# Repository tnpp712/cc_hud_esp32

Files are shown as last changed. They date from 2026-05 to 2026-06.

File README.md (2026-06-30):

# cc_hud · AI 状态灯

放在桌上的一个小硬件 HUD：一块 1.54″ 彩屏显示 **Claude Code / Codex 的额度、花费、上下文、状态**，外圈 24 颗灯随 AI "在干嘛"红黄绿变化。ESP32-S3 驱动，电脑通过蓝牙/WiFi 把状态推给它。

> 本仓库是 [`uk0/cc_hud_esp32`](https://github.com/uk0/cc_hud_esp32) 的私有 fork，在原版"BLE 推额度 + LCD HUD"基础上做了大量产品级增强（见下）。英文原版说明见 [`README.en.md`](README.en.md)。

<p align="center">
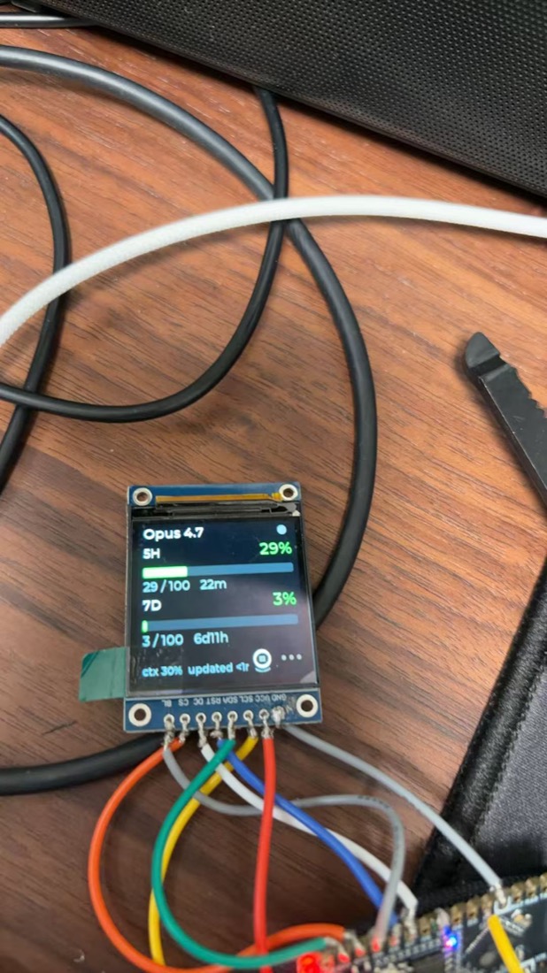
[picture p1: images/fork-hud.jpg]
HUD 显示额度
  
  &nbsp;&nbsp;
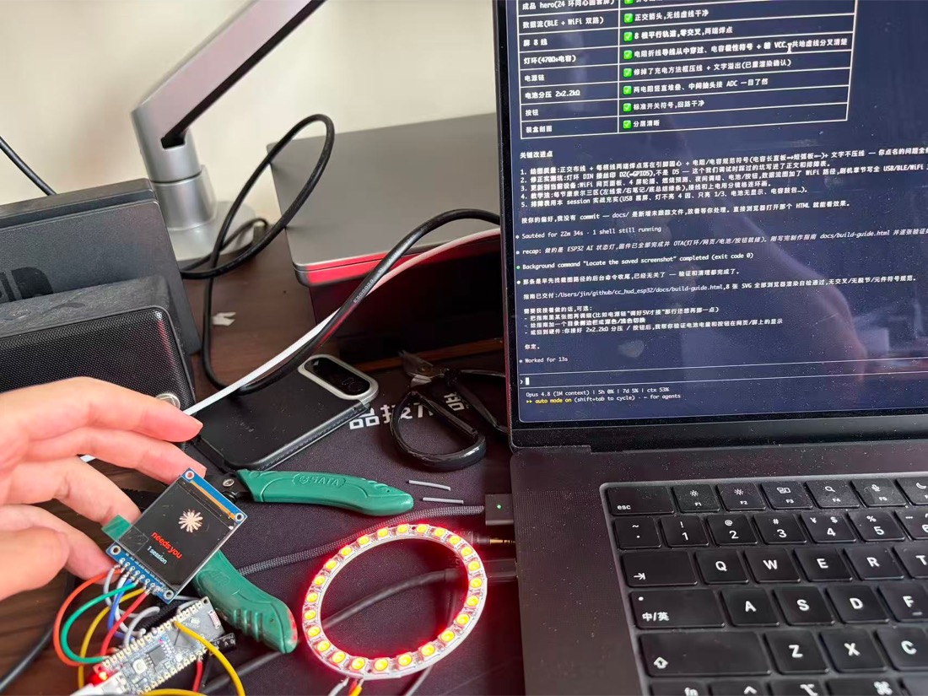
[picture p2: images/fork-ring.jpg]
设备 + 24 灯环
  
</p>

<p align="center"><em>左：屏幕实时显示 5H/7D 额度 + 重置倒计时 + 上下文用量。右：屏 + 24 颗 WS2812B 状态灯环。</em></p>

---

## 🔱 本 fork 新增功能

**显示 / UI**
- **4 屏轮播状态机**：额度页 / 统计页（成本·时长·增删行·5H 重置倒计时）/ 工具页（大图标 + N 会话·M 忙）/ 时钟页；空闲自动轮播、干活锁工具页、防抖
- **燃烧率耗尽预测**：按当前用速预测"X 窗口会在重置前耗尽" → footer 红字预警
- 更大字号 HUD + CJK 中文天气

**24 灯环状态灯（WS2812B，`firmware/src/led_ring.*`）**
- 空闲 = 绿色**额度表**（点亮颗数 = 额度%、分级变色）
- 工作 = 黄色**彗星** · 等权限 = 红色**整环闪** · 低电 = 橙色慢闪
- **Codex 完成绿脉冲**：AI 答完一轮闪三下

**无线 / OTA / 网页（`firmware/src/wifi_ota.*`）**
- **WiFi OTA**：`cc-hud.local` 局域网秒级刷机（BLE OTA 保留作救砖）
- **网页面板** `http://cc-hud.local/`：实时额度/成本/状态/电量，**亮度滑块（存 NVS、免重刷）**、翻页/调暗遥控、固件版本/运行时长/内存
- **NTP 自动校时**：WiFi 在线自动授时，断电后免手动校准

**智能 / 省电**
- 夜间(23:00–07:00)+ 长空闲自动调暗、空闲 10 分钟熄灯环
- 修复 USB-CDC-on-boot 导致的"插电脑屏黑"（`displayInit` 前移）

**多 AI 工具支持**
- **Codex CLI**：`~/.codex/config.toml` 的 `notify` → 适配器，答完触发灯环绿脉冲；链式调度器保留已有 notify（如 computer-use）
- 任意工具调 `host/push_state.py` 即可推状态；多工具/多会话**统一聚合**（有人忙就显示忙）

**可选硬件（接上即生效，不接不误报）**
- 电池电量监测（2×2.2kΩ 分压 → 丝印 A0）+ 低电告警
- 实体按钮（→ 丝印 A1）短按翻页、长按调暗

---

## 硬件一览

| 部件 | 选型 |
|---|---|
| 主板 | ESP32-S3-Nano（N8R8/N16R8，兼容 Arduino Nano ESP32 引脚） |
| 屏 | 1.54″ 240×240 IPS ST7789（4 线 SPI，8pin） |
| 灯环 | WS2812B **24 位**单圈圆环（内径 ≥56mm）+ 470Ω 电阻 + 470µF 电容 |
| 电源 | 3.7V 锂电（带保护板）+ TP4056 充电 + MT3608 升压 5V + 自锁开关 |
| 可选 | 2×2.2kΩ（电量）、自复位按钮、亚克力盒 |

> ⚠ 丝印坑：这块板低位 GPIO 标 **A0–A7**，灯环 DIN 接 **D2(=GPIO5)** 不是 "D5"。完整对照见制作指南。

---

## 快速上手

**完整图文制作指南** → **[`docs/build-guide.html`](docs/build-guide.html)**（康奈尔笔记 + 分镜，浏览器直接打开：引脚总表 / 焊接 / 接线 / 调 5V / 刷机 / 排障 / 多工具）。

最短路径：

1. **焊屏**：屏 8 线接主板（VCC→3V3，**别接 5V**）
2. **焊电源**：电池→TP4056→开关→MT3608，**先单独调好 5.0V** 再接主板
3. **焊灯环**：DIN 经 470Ω → 主板 D2(GPIO5)；VCC → MT3608 IN+（开关后 3.7V）；470µF 跨 VCC/GND
4. **刷固件**：USB 首刷 → 之后 WiFi OTA 秒刷
   ```bash
   cd firmware
   pio run -e esp32s3_nano -t upload            # USB 首刷
   pio run -e esp32s3_nano_wifi -t upload       # 之后 WiFi 秒刷
   ```
5. **配电脑**（目录 `host/`，下面命令都在这个目录里跑）

   电脑在这套系统里是"中间人"：读 AI 的状态/额度 → 通过蓝牙推给盒子。核心是一个常驻后台进程 **daemon**，它**独占一条蓝牙连接**，把多个 AI 会话的状态聚合后推给设备。按 ①→⑤ 配一遍即可。

   **① 建 Python 环境**
   ```bash
   python3.12 -m venv .venv && .venv/bin/pip install bleak
   ```
   - `venv` 是隔离的 Python 环境，依赖只装进 `host/.venv/`，不污染系统 Python；`bleak` 是跟蓝牙设备通信的库。
   - **为什么必须 Python ≥ 3.10**：daemon 启动时会建一个"蓝牙发送队列"，Python 3.9 会把这个队列错绑到旧的事件循环上，导致 daemon 一跑就满屏 `attached to a different loop`、蓝牙完全发不出去；3.10 起改了这个行为才正常。没有 3.12 就 `brew install python@3.12`。

   **② 找设备地址，存成环境变量**
   ```bash
   .venv/bin/python push_quota.py --discover          # 列出附近设备，记下你盒子的 UUID
   echo 'export CCHUD_ADDR=<上一步的UUID>' >> ~/.zshrc && source ~/.zshrc
   ```
   - macOS 上蓝牙设备没有固定 MAC，只有系统分配的一串 UUID，所有推送都要靠它指明"发给哪个盒子"。
   - **为什么写进 `~/.zshrc`、不改脚本**：地址放进环境变量后，仓库脚本保持原样——`git pull` 不冲突，也不会把你的设备地址提交进代码。之后每个命令都用 `$CCHUD_ADDR` 引用它。

   **③ 给盒子配 WiFi**（一次性，经蓝牙写入）
   ```bash
   .venv/bin/python push_wifi.py --address $CCHUD_ADDR --ssid 'WiFi名' --password '密码'
   ```
   - **为什么要联网**：盒子联网后能自动 NTP 校时、用 WiFi 秒级 OTA 刷固件、开网页面板 `http://cc-hud.local/`。不联网也能用蓝牙，但这些功能没了。

   **④ 装 hooks**（让 AI 自动上报状态）
   ```bash
   CCHUD_ADDR=$CCHUD_ADDR CCHUD_USE_V7=1 .venv/bin/python -m cchud_daemon.cli install claude
   CCHUD_ADDR=$CCHUD_ADDR CCHUD_USE_V7=1 .venv/bin/python -m cchud_daemon.cli install codex
   ```
   - **hook** = AI 工具在关键时刻（开始思考、调工具、等你确认、结束）自动运行的小脚本，这里就是把状态投给 daemon。
   - 两条命令分别给 Claude Code 和 Codex 各装一套，会自动写进它们各自的配置并**保留你已有的第三方 hook**；`CCHUD_USE_V7=1` 表示用新版 v7 协议（配最新固件）。

   **⑤ 起常驻 daemon**
   ```bash
   CCHUD_ADDR=$CCHUD_ADDR CCHUD_USE_V7=1 .venv/bin/python -m cchud_daemon.cli daemon
   ```
   - 保持这个终端窗口开着，它就一直把状态推给盒子；终端没刷出错误 = 正常。
   - **为什么必须在普通终端跑、不能用 launchd 开机自启**：macOS 的蓝牙权限按"谁启动了这个进程"授权——普通终端有授权，而 launchd 拉起的后台进程拿不到、还不弹授权框，会静默报 `BLE is not authorized`。想保活可以用 tmux 或 `nohup`。

   **Codex 额外两点**
   - 装完 hooks 要**重启 Codex**，启动时会弹"是否信任 hooks"，选 **Trust all and continue**——新版 Codex 不信任就不跑 hook。
   - ⚠️ **千万别往 `~/.codex/config.toml` 写 `hooks = true`**：新版 Codex 会报 `expected struct HooksToml` 直接起不来。`~/.codex/hooks.json` 是自动加载的，不需要这行。

   > 状态栏渲染用 `ccstatusline`；本机没装 `bun` 的话，把 `cchud-statusline.sh` 里的 `bunx` 改成 `npx`。完整步骤 / 排错见 [`host/DAEMON.md`](host/DAEMON.md)。

---

## 多 AI 工具

| 工具 | 显示 | 接法 |
|---|---|---|
| **Claude Code** | 完整：额度 + 上下文 + 成本 + 4 状态灯 + 多会话 | `cchud_daemon.cli install claude`（写 `hooks` + `statusLine`，保留第三方） |
| **Codex CLI** | 状态 + 多会话（思考/工具/等待/空闲） | `cchud_daemon.cli install codex`（写 `~/.codex/hooks.json`，重启 Codex 后 **Trust hooks**；**勿写 `hooks=true`**） |
| 其它 | 任意脚本调 `push_state.py` 推状态/灯色 | 通用 CLI |

---

## 目录结构

```
firmware/        ESP32-S3 固件（PlatformIO · LVGL 9 · NimBLE）
  src/
    main.cpp           主循环 + 状态聚合 + NTP + 省电
    led_ring.*         24 灯环状态灯
    wifi_ota.*         WiFi OTA + 网页面板
    lvgl_ui.*          4 屏 UI
    display.* ble_server.* persistence.* battery.* button.*
host/            电脑端 Python + shell
  push_wifi.py / push_state.py / push_quota.py / push_idle.py / ota.py
  cchud-hook.sh / cchud-update.sh / cchud-idle.sh   (Claude Code)
  cchud-codex-notify.sh / cchud-codex-dispatch.sh   (Codex)
docs/build-guide.html  完整图文制作指南
README.en.md           英文原版说明（upstream）
```

---

*基于 [uk0/cc_hud_esp32](https://github.com/uk0/cc_hud_esp32)。本 fork 增强见上。*

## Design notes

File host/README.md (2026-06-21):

# cc_hud host push CLI

`push_quota.py` sends a 9-byte BLE payload to the CC-HUD device, updating the
5-hour and 7-day quota bars shown on the hardware display.

`cchud-update.sh` is a rate-limited fire-and-forget wrapper meant for
high-frequency hooks (Claude Code statusline, shell prompts, etc.).

---

## Install

```bash
# Recommended (uv):
uv venv .venv
uv pip install -r requirements.txt

# Or plain Python:
python3 -m venv .venv
.venv/bin/pip install -r requirements.txt
```

---

## First-time setup: discover your device

macOS hides BLE MAC addresses, so each peripheral is identified by a
CoreBluetooth UUID instead. Linux and Windows show the real MAC. Find yours:

```bash
.venv/bin/python push_quota.py --discover --verbose --timeout 8
```

Example output:

```
ADDRESS                                   NAME              RSSI
03265204-7126-B6FE-6F17-6E9621CEA97F      CC-HUD            -37 dBm
```

Save that address — use it with `--address` (push_quota.py) or via
`CCHUD_ADDR` (cchud-update.sh) so subsequent pushes skip the scan.

---

## Usage — single push

```bash
.venv/bin/python push_quota.py \
  --address 03265204-7126-B6FE-6F17-6E9621CEA97F \
  --5h-used 42 --5h-limit 100 \
  --7d-used 300 --7d-limit 1000 \
  --verbose
```

| Flag | Default | Description |
|---|---|---|
| `--address` | (none) | BLE address/UUID. Skips scan when provided. |
| `--device-name` | `CC-HUD` | Advertisement name (used by `--discover` and the scan fallback). |
| `--discover` | off | Scan and print all matching devices, then exit. |
| `--timeout` | `10` | Scan/connect timeout in seconds. |
| `--verbose` | off | Print each step to stderr. |

Exit codes: `0` ok · `1` device not found · `2` connect failed ·
`3` write failed · `130` Ctrl-C.

> ⚠️ The Quota characteristic is written with `response=True` (Write With
> Response). bleak's CoreBluetooth backend silently drops `response=False`
> packets, so the firmware never sees them. This is enforced internally.

---

## Usage — statusline integration (recommended)

`cchud-update.sh` is the wrapper to call from a frequently-firing hook like
Claude Code's `~/.claude/statusline.sh`. It:

- Returns in **<50 ms** (no BLE on the foreground path).
- Skips silently if it pushed within the last 30 seconds
  (override via `CCHUD_RATE_LIMIT`).
- Forks the actual BLE write into the background, logged to
  `/tmp/cchud-push.log`.

### 1. Set the device address

Either edit the `CCHUD_ADDR` default inside `cchud-update.sh`, or export it
from the script that invokes it:

```bash
export CCHUD_ADDR='03265204-7126-B6FE-6F17-6E9621CEA97F'
```

### 2. Hook into your `statusline.sh`

Append near the end of your `~/.claude/statusline.sh` (or whatever it's called
in your setup):

```bash
# --- CC-HUD: push current quota over BLE (fire-and-forget) -----------------
# Replace H5_USED / H5_LIMIT / D7_USED / D7_LIMIT with whichever variables
# your statusline script already computes from the Claude Code session.
/Users/firshme/Desktop/work/cc_hud/host/cchud-update.sh \
  "${H5_USED:-0}" "${H5_LIMIT:-0}" \
  "${D7_USED:-0}" "${D7_LIMIT:-0}" \
  >/dev/null 2>&1 || true
# --------------------------------------------------------------------------
```

The `|| true` guard means a transient BLE failure never breaks your
statusline output.

### 3. Tail the background log

```bash
tail -f /tmp/cchud-push.log
```

### Environment overrides

| Variable | Default | Meaning |
|---|---|---|
| `CCHUD_ADDR` | (hardcoded UUID) | BLE address/UUID of the device. |
| `CCHUD_RATE_LIMIT` | `30` | Minimum seconds between actual pushes. |
| `CCHUD_LOG` | `/tmp/cchud-push.log` | Log path for the background bleak process. |
| `CCHUD_TIMEOUT` | `8` | Scan/connect timeout in seconds. |

---

## Important: this CLI is transport-only

Neither `push_quota.py` nor `cchud-update.sh` figures out the quota numbers
themselves. You supply them — from `ccusage`, your own jsonl parser, the
Claude Code session statusline, or wherever — and pass them as four
integers.

---

## Automate with launchd (alternative to statusline hook)

For a fixed 60-second poll independent of statusline activity:

1. Edit `com.cchud.push.plist`:
   - Replace `/REPLACE_ME/wrapper.sh` with an absolute path to your wrapper.
   - Confirm `/usr/local/bin/python3` is correct (or use the venv Python:
     `/path/to/cc_hud/host/.venv/bin/python`).

2. Install and load:

   ```bash
   cp com.cchud.push.plist ~/Library/LaunchAgents/
   launchctl load ~/Library/LaunchAgents/com.cchud.push.plist
   ```

Logs in `/tmp/cchud.out.log` / `/tmp/cchud.err.log`. Unload with
`launchctl unload …`.

---

## Troubleshooting

**`Bluetooth device is turned off`**

Either macOS Bluetooth is off, or the terminal running the script doesn't
have Bluetooth permission. Grant it in **System Settings → Privacy &
Security → Bluetooth**.

**Device not found (exit code 1)**

- Confirm the CC-HUD device is powered on and advertising (the panel should
  show "CC HUD" header + "waiting for data...").
- Try `--timeout 20`.
- Re-run `--discover --verbose` to see if scanning works at all.

**Write succeeds but screen doesn't update**

If you copy old code that uses `response=False`, the BLE packet is silently
dropped on macOS + NimBLE. The current `push_quota.py` forces `response=True`
internally — make sure you're not bypassing it.

**Statusline pushes nothing**

- Check `/tmp/cchud-push.log` — bleak errors land there.
- Check `/tmp/cchud-last-push.ts` exists and is recent (rate-limit check).
- Run `cchud-update.sh 1 100 1 100` by hand and watch the log.

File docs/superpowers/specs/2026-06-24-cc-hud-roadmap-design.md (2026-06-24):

# CC-HUD 演进路线图设计(对标 ping-island)

- 状态:草案,待 review
- 日期:2026-06-24
- 范围:全局路线图(4 层演进)+ v7 协议总设计
- 不在本文范围:单层的实现细节(每层后续各自出 spec→plan)

## 一、背景与目标

CC-HUD 是一个基于 ESP32-S3 + 1.54" 240×240 ST7789 屏 + 24 颗 WS2812B 灯环的实体 HUD,通过 BLE 接收主机推送,实时展示 Claude Code 的额度、会话成本、工作状态。当前固件已相当成熟(4 屏轮播、燃烧率预测、WiFi OTA、夜间调暗、灯环状态),但主机侧深度绑定 Claude Code,其他客户端(Codex 仅有"完成绿脉冲")基本缺席。

参考项目 ping-island 是一个 macOS 灵动岛应用,支持 13+ AI 编码客户端,核心能力包括:多客户端统一接入、权限批准/追问提醒、多会话聚合、一键跳回、音效通知。它工程上最值得借鉴的是 **单一真实源 + 接入边界规范化** 的架构:所有客户端差异被压缩在 hook 规范化处,核心逻辑完全客户端无关。

本路线图的目标:把 CC-HUD 从"Claude 专用状态灯"演进为"客户端无关的实体 AI 工作台提醒器",并在演进中放大硬件相对屏幕应用的**独有优势**。

## 二、设计原则:硬件的差异化是「离屏感知」

ping-island 是"屏幕里的应用",强在**交互**(在岛里直接批准、回答、跳回窗口);CC-HUD 是"桌面上的实体设备",强在**离屏感知**(不盯屏幕也能用余光/灯环/未来的声震,知道"AI 在等我")。

因此本路线图**不照搬** ping-island 的全部功能(如一键跳回、在设备上回答问题——这些屏幕应用做得更好),而是聚焦能放大"实体提醒"优势的能力:

1. 把"需要你介入"这件事做成**强物理信号**(屏幕大字 + 红环强闪,未来加声/震)。
2. 让设备**不挑客户端**——无论用 Claude / Codex / Gemini / Qwen,都能看到一致的状态。
3. 在小屏上对多会话做**信息优先级取舍**,让"在等你的那个"最显眼。

## 三、对标结论

| 维度 | CC-HUD 现状 | ping-island | 路线图取舍 |
|---|---|---|---|
| 多客户端 | 深度只做 Claude;Codex 仅完成脉冲 | 13+ 客户端统一接入 | 借鉴:适配器层 + 统一事件模型 |
| "需介入"提醒 | 有 waiting 红环,不区分类型/无详情 | 显示工具名+参数、问题文本 | 借鉴语义,用**物理强提醒**表达 |
| 多会话 | 主机聚合成单态,屏幕只显示聚合 | 完整会话列表 + 优先级排序 | 借鉴,小屏做信息取舍 |
| 反馈通道 | 仅视觉(屏+灯) | 系统音 + 音效包 | 协议/固件留声震接口,硬件未来焊接 |
| 主机可扩展性 | bash+python 针对 Claude 硬编码 | 统一事件模型 + 配置自动安装 | 借鉴:常驻 daemon + adapter + 自动装 hook |
| 交互(批准/跳回) | 无 | 在岛内直接操作 | **不搬**,非硬件优势 |

## 四、目标态架构(4 层全部落地后)

```
┌──────────────── 主机侧 (macOS) ────────────────┐        ┌─────── 设备 (ESP32-S3) ───────┐

 各客户端 hooks
  ├ Claude Code ─┐
  ├ Codex CLI ───┤   [适配器层]  每家一个 adapter,
  ├ Gemini CLI ──┼─► 把原生 hook/JSONL 规范化
  ├ Qwen / … ────┘   为统一 CcHudEvent
                          │
                          ▼
              ┌─ cchud-daemon (常驻) ─┐
              │  SessionStore 单一真相 │
              │  Aggregator  优先级聚合│
              │  QuotaTracker 额度/成本│
              │  BleLink 常驻BLE+v7编码 │──BLE(v7 TLV)──►  协议解析 v1-v6(旧) + v7(新)
              └────────────────────────┘                   设备侧轻量 SessionStore
                          ▲                                 ├ HUD/STATS/TOOL/CLOCK(现有)
              cchud install <client>                        ├ 介入页(第3层新增)
              自动写各客户端 hook 配置                       ├ 会话列表页(第4层新增)
                                                            └ 灯环 +(预留 声/震 GPIO)
```

关键结构变化(相对现状):

- **主机侧从无状态脚本 → 常驻 daemon**。现在每次 hook 都 fork 进程、读 `/tmp` 文件聚合、抢 flock 再重连 BLE(6s 超时)。daemon 持有 SessionStore 与常驻 BLE 连接,hook 退化为"发一条轻量事件给 daemon"的瘦客户端,提醒实时性大幅提升,多会话/多客户端天然支持。
- **接入边界规范化**。每个客户端一个 adapter,把原生 hook/JSONL 事件翻译成统一 `CcHudEvent`;daemon 核心逻辑客户端无关。
- **设备侧引入轻量 SessionStore**。从"单一聚合态"升级到能持有"会话列表 + 当前介入",为第 3、4 层铺路(ESP32-S3 有 8MB PSRAM,容量充足)。

## 五、四层演进路线图

每层独立交付价值,各自出 spec→plan→实现。依赖关系:第 1 层是地基,2/3/4 层都长在其上。

### 第 1 层:主机侧统一接入层(地基)

- **目标**:把现有 Claude 硬编码脚本重构为"daemon + 适配器层"架构,并定稿 v7 协议。
- **主机交付物**:
  - `cchud-daemon` 常驻进程:SessionStore(单一真相)、Aggregator(优先级聚合 `waiting>tool>thinking>idle`)、QuotaTracker、BleLink(常驻 BLE + v7 TLV 编码)。
  - 适配器接口 + **Claude adapter**(把现有 `cchud-hook.sh` / `cchud-quota-push.sh` 的逻辑迁为第一个 adapter)。
  - 瘦 hook 脚本:仅向 daemon 发事件(Unix domain socket,借鉴 ping-island `HookSocketServer`)。
  - `cchud install <client>` / `cchud status`:自动安装/校验各客户端 hook 配置与 statusLine。
  - daemon 生命周期:`launchd` plist(macOS),崩溃自启,日志落 `~/.cchud/`。
- **设备交付物**:固件接入 v7 TLV 解析骨架;设备侧轻量 SessionStore;旧 v1–v6 解析路径原样保留。
- **协议**:**v7 总设计定稿**(见第七节)。
- **验收**:Claude 全部现有能力在新架构下功能等价;BLE 不再每次重连;`cchud install claude` 一键可用。

### 第 2 层:多客户端一等公民

- **目标**:Codex / Gemini / Qwen 等做成与 Claude 同级的完整状态接入(thinking/tool/waiting/idle + 成本 + 标题 + 会话元数据),而非仅"完成脉冲"。
- **主机交付物**:Codex adapter、Gemini adapter、Qwen adapter(纯增量,各自把原生 hook/JSONL 映射为 `CcHudEvent`);`cchud install codex|gemini|qwen`。
- **设备交付物**:品牌/图标随当前活跃客户端切换(tag `CLIENT_ID`);"心情猫/Claude logo"不再写死。
- **协议**:复用 v7,启用 `CLIENT_ID` / `CLIENT_NAME` tag。
- **验收**:任一客户端单独使用时,设备显示与 Claude 体验一致。

### 第 3 层:强化物理提醒(硬件核心价值)

- **目标**:把"需要你介入"做成强物理信号,区分 `等批准` / `等回答问题` / `出错`,屏幕显示工具名/问题摘要。
- **主机交付物**:Aggregator 在 waiting 态细分 `INTERVENTION_KIND`,携带工具名、问题摘要、来源会话。
- **设备交付物**:新增**介入页**——大字显示 `⚠ 等你批准: Bash` / `❓ 问题: 选哪个方案`,红环强闪(1Hz→高强度);预留声/震驱动接口(`ALERT_CHANNELS` bitmask 已定义,焊接后无需改协议)。
- **协议**:启用介入域 tag(0x40–0x5F)。
- **验收**:Claude/Codex 触发工具批准或 AskUserQuestion 时,设备 3 秒内进入介入页并强提醒;清除后自动恢复。

### 第 4 层:多会话概览

- **目标**:小屏呈现多个会话,"在等你的"排最前。
- **主机交付物**:daemon 推送会话列表摘要(每条:客户端、状态、短标题),按优先级排序。
- **设备交付物**:新增**会话列表页**,小屏分行显示,介入态置顶高亮;与现有轮播/锁定逻辑协调。
- **协议**:启用会话列表域 tag(0x60–0x7F),处理分片(见第七节 MTU)。
- **验收**:并发 3+ 会话时,设备列表页正确排序与高亮,刷新无闪烁。

## 六、主机侧 daemon 形态

- **进程**:单一常驻进程 `cchud-daemon`,由 `launchd` 守护(KeepAlive),崩溃自启。
- **接入**:监听 Unix domain socket(如 `~/.cchud/daemon.sock`),hook 脚本以瘦客户端身份发送 JSON 事件;socket 不可用时 hook 静默降级(不阻塞客户端)。
- **适配器层**:`Adapter` 接口约定 `normalize(rawEvent) -> CcHudEvent`;`ClientProfile` 注册表登记每个客户端的 hook 路径、JSONL 路径、品牌、`CLIENT_ID`(借鉴 ping-island `ClientProfile.swift`)。
- **SessionStore**:以 `sessionId` 为键维护会话状态(阶段、工具、标题、最后活动时间、介入上下文);TTL 清理死会话(沿用现 5 分钟语义)。
- **BleLink**:常驻持有设备连接,断线重连退避;统一负责 v7 TLV 编码与(必要时)分片;替代现有"每次推送 flock + 重连"。
- **实现语言**:建议 Python(沿用现有 `bleak` BLE 栈,迁移成本最低);daemon 化与 socket 用标准库即可。语言最终在第 1 层 spec 定。

## 七、v7 协议总设计(TLV 可扩展帧)

### 7.1 为什么转 TLV

v1–v6 是"固定布局 + 版本号",固件已背 6 个解析分支。后三层还要加大量字段。TLV 让固件用一个循环解析全部字段,以后加能力只是**分配新 tag**,不再升版、不再加分支;daemon 也只发设备关心的字段。旧 v1–v6 路径原样保留,平滑过渡。

### 7.2 帧结构

复用现有 GATT(Service `12345678-aaaa-bbbb-cccc-1234567890ab`,Quota/State Characteristic 不变)。新增统一 msg_type:

```
偏移  字段        类型   说明
0     msg_type    u8     0x0B = CCHUD_MSG_V7_TLV
1     flags       u8     bit0=MORE_FRAGMENTS  bit1..7 预留
2     seq         u8     分片序号(未分片时为 0)
3     total       u8     分片总数(未分片时为 1)
4..N  fields      TLV*   连续若干 [tag:u8][len:u8][value:len]
```

- 未分片帧:`flags.bit0=0, seq=0, total=1`,字段直接跟在头后。
- 单字段格式:`[tag:u8][len:u8][value: len 字节]`;`len=0` 表示存在性标志位字段。
- 未知 tag:固件**跳过**(读 len 跳过 value),保证前向兼容。

### 7.3 MTU 与分片

- BLE 默认 ATT MTU 23 字节(有效载荷 20)。NimBLE 支持 MTU 协商至 ~512;**daemon 连接后先协商更大 MTU**,绝大多数帧单包可达。
- 仅当单帧(如会话列表、长问题文本)超出协商后 MTU 时启用分片:同一 msg_type,`flags.bit0=1`,按 `seq`/`total` 重组;固件侧设重组缓冲与超时丢弃。
- 高频状态帧(state/quota)应控制在单包内,避免分片开销。

### 7.4 完整 tag 分配表

tag 按域分区,预留充足空间;`✓`=本路线图已规划,`预留`=未来扩展。

#### 额度 / 成本域(0x01–0x1F)

| tag | 名称 | 类型 | 引入层 | 说明 |
|-----|---|---|---|---|
| 0x01 | FIVE_HOUR_USED_PCT | u8 | 1 | 5h 用量百分比 |
| 0x02 | FIVE_HOUR_RESET_IN_S | u32 | 1 | 5h 重置倒计时(秒) |
| 0x03 | SEVEN_DAY_USED_PCT | u8 | 1 | 7d 用量百分比 |
| 0x04 | SEVEN_DAY_RESET_IN_S | u32 | 1 | 7d 重置倒计时(秒) |
| 0x05 | CONTEXT_USED_PCT | u8 | 1 | 上下文窗口用量 |
| 0x06 | COST_MICRO_USD | u32 | 1 | 会话成本(微美元) |
| 0x07 | DURATION_S | u32 | 1 | 会话时长(秒) |
| 0x08 | LINES_ADDED | u32 | 1 | 代码增加行 |
| 0x09 | LINES_REMOVED | u32 | 1 | 代码删除行 |
| 0x0A | PLAN_MODE | u8 | 1 | 0=sub,1=api |
| 0x0B | TITLE | utf8 | 1 | 屏幕标题(计划名) |
| 0x0C–0x1F | — | — | 预留 | 额度/成本扩展 |

#### 会话 / 状态域(0x20–0x3F)

| tag | 名称 | 类型 | 引入层 | 说明 |
|-----|---|---|---|---|
| 0x20 | AGG_STATE | u8 | 1 | 聚合态 0=idle 1=thinking 2=tool 3=waiting 4=done |
| 0x21 | ACTIVE_TOOL_NAME | utf8 | 1 | 当前工具名 |
| 0x22 | TOTAL_SESSIONS | u8 | 1 | 总会话数 |
| 0x23 | BUSY_SESSIONS | u8 | 1 | 忙碌会话数 |
| 0x24 | ACTIVE_SESSION_TITLE | utf8 | 2 | 当前活跃会话短标题 |
| 0x25–0x3F | — | — | 预留 | 会话/状态扩展 |

#### 介入 / 提醒域(0x40–0x5F,第 3 层)

| tag | 名称 | 类型 | 引入层 | 说明 |
|-----|---|---|---|---|
| 0x40 | INTERVENTION_KIND | u8 | 3 | 0=none 1=approval 2=question 3=error |
| 0x41 | INTERVENTION_TOOL | utf8 | 3 | 等批准的工具名 |
| 0x42 | INTERVENTION_TEXT | utf8 | 3 | 问题摘要/提示文本 |
| 0x43 | INTERVENTION_SOURCE | utf8 | 3 | 来源会话短标识 |
| 0x44 | ALERT_LEVEL | u8 | 3 | 提醒强度(驱动灯环/未来声震) |
| 0x45 | ALERT_CHANNELS | u8(bitmask) | 3 | bit0=屏 bit1=灯 bit2=蜂鸣 bit3=震(声/震预留) |
| 0x46–0x5F | — | — | 预留 | 介入扩展 |

#### 会话列表域(0x60–0x7F,第 4 层)

| tag | 名称 | 类型 | 引入层 | 说明 |
|-----|---|---|---|---|
| 0x60 | SESSION_LIST_COUNT | u8 | 4 | 列表条数 |
| 0x61 | SESSION_ENTRY | bytes(子记录) | 4 | 一条会话摘要,见下 |
| 0x62–0x7F | — | — | 预留 | 列表扩展 |

`SESSION_ENTRY`(0x61)value 子结构(定长头 + 变长标题):

```
偏移  字段          类型   说明
0     entry_idx     u8     排序序号(0 最优先)
1     client_id     u8     客户端(见 CLIENT_ID 取值)
2     state         u8     同 AGG_STATE 取值
3     intervention  u8     同 INTERVENTION_KIND(0=无)
4     title_len     u8     短标题字节数
5..   title         utf8   短标题
```

#### 设备控制 / 时间域(0x80–0x9F)

| tag | 名称 | 类型 | 引入层 | 说明 |
|-----|---|---|---|---|
| 0x80 | UNIX_TS | u32 | 1 | 当前 unix 时间 |
| 0x81 | UTC_OFFSET_MIN | i16 | 1 | 时区偏移(分钟) |
| 0x82 | IDLE_FORCE | u8 | 1 | 强制空闲(对应旧 0x05) |
| 0x83 | MOOD_PREVIEW | u8 | 1 | 心情预览 0–4(对应旧 0x06) |
| 0x84 | STATUS_STRING | utf8 | 1 | 空闲页天气/状态串 |
| 0x85–0x9F | — | — | 预留 | 设备控制扩展 |

#### 客户端 / 品牌域(0xA0–0xBF,第 2 层)

| tag | 名称 | 类型 | 引入层 | 说明 |
|-----|---|---|---|---|
| 0xA0 | CLIENT_ID | u8 | 2 | 0=claude 1=codex 2=gemini 3=qwen 4=cursor …(注册表统一) |
| 0xA1 | CLIENT_NAME | utf8 | 2 | 客户端显示名 |
| 0xA2–0xBF | — | — | 预留 | 客户端扩展 |

#### 厂商 / 实验预留(0xC0–0xFF)

整段预留给实验性/厂商私有字段,固件遇到一律跳过。

### 7.5 旧协议与迁移

- msg_type `0x01–0x0A` 与 WiFi 凭证 `0x09` 路径**原样保留**;v7 不替换它们,只承载新能力。
- WiFi 凭证(敏感、一次性)继续走独立 msg_type,不进 v7 通用帧。
- 迁移顺序:第 1 层 daemon 先用 v7 重发"现有等价字段",验证 TLV 通路与 MTU 协商无误后,旧字段逐步只保留兼容。
- 固件协商失败回退:若 MTU 协商失败,daemon 退回单包小帧 + 必要分片,保证旧设备/弱链路可用。

## 八、关键风险与取舍

| 风险 | 影响 | 缓解 |
|---|---|---|
| daemon 生命周期复杂度 | 后台进程崩溃/僵死导致设备失更新 | launchd KeepAlive + 心跳日志 + hook 静默降级 |
| BLE MTU/分片 | 会话列表/长文本超单包 | 连接先协商大 MTU;仅超长才分片;高频帧控制单包 |
| 固件内存/渲染 | 介入页/列表页 + 多会话状态增加占用 | 复用 PSRAM;短标题截断;LVGL 对象复用 |
| 多客户端 hook 差异 | 各家事件语义不一 | adapter 边界吸收差异;核心只认 `CcHudEvent` |
| 中文/UTF8 显示 | 工具名/标题/问题文本含中文 | 复用现有 20pt CJK 字体;按宽度截断 |
| 范围蔓延 | 4 层一起做易失控 | 严格分层交付,每层独立 spec→plan→验收 |

## 九、后续步骤

1. 本路线图 review 通过后,**第 1 层(地基)单独出 spec**:细化 daemon 模块边界、adapter 接口、socket 事件格式、launchd 配置、v7 在固件侧的解析实现与回归验证清单。
2. 第 1 层 plan→实现→验收(Claude 功能等价 + BLE 常驻)。
3. 依次推进第 2/3/4 层,各自 spec→plan→实现。

## 实施进展

- **第 1 层(地基):✅ 已完成(2026-06-24)**。主机 daemon(adapter 层 + SessionStore/QuotaTracker/Aggregator + 常驻 BLE)+ 固件 v7 TLV 解析 已合入 `main`(host 30 + 固件 native 4 测试全绿)。BLE OTA 刷入 v7 固件并完成真机 1b 验证:v7 编码 ↔ 解析 ↔ 显示与 v6 等价(5h/7d 额度、标题、倒计时正确)。daemon 使用见 `host/DAEMON.md` 。
  - 已知遗留(后续层处理):状态帧仍走 `0x07`(quota 才走 v7);v7 `title` UTF-8 截断;BLE OTA 慢(建议 WiFi OTA)。
- 第 2/3/4 层:待启动。

## 附:关键文件参照(现状)

- 固件主循环/状态机:`firmware/src/main.cpp`
- BLE GATT 解析:`firmware/src/ble_server.cpp`
- 全局配置/UUID/协议常量:`firmware/src/config.h`
- 4 屏 UI:`firmware/src/lvgl_ui.cpp`
- 灯环:`firmware/src/led_ring.cpp`
- 现有主机 hook:`host/cchud-hook.sh`、`host/cchud-quota-push.sh`、`host/cchud-update.sh`
- 现有 BLE 推送:`host/push_quota.py`、`host/push_state.py`
- 接入指南:`host/HOOKS_SETUP.md`

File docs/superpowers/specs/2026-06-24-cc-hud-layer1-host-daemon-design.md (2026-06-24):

# CC-HUD 第 1 层(地基)详细设计:主机侧统一接入层 + v7 协议落地

- 状态:草案,待 review
- 日期:2026-06-24
- 上游:`2026-06-24-cc-hud-roadmap-design.md`(全局路线图)
- 范围:第 1 层(地基)。常驻 daemon + 适配器层 + Claude adapter 迁移 + v7 TLV 固件解析骨架 + CLI 安装。
- 不在本范围:Codex/Gemini/Qwen adapter(第 2 层)、介入页/会话列表页(第 3/4 层)。本层只保证 **Claude 现有能力功能等价**,并铺好后三层的地基与协议。

## 一、目标与验收

### 目标

1. 把现有"无状态 hook 脚本 + `/tmp` 文件 IPC"重构为单一常驻进程 `cchud-daemon`,内部持有会话/额度状态与常驻 BLE 连接。
2. 抽出 **adapter 层**,把现有 Claude 逻辑迁为"第一个 adapter",核心逻辑客户端无关。
3. 固件接入 **v7 TLV 解析**(与旧 v1–v6 并存),daemon 用 v7 编码下发。
4. 提供 `cchud` CLI:一键安装/校验 hook、管理 daemon。

### 验收标准(逐条对照现状,功能等价)

| # | 验收项 | 现状来源 |
|---|---|---|
| A1 | 多会话状态聚合优先级 `waiting>tool>thinking>idle` 不变 | `cchud-hook.sh:90-115` |
| A2 | 死会话 TTL 清理(默认 300s)语义不变 | `cchud-hook.sh:96-98` |
| A3 | 额度跨会话按 `resets_at` 分窗取最大值合并 | `cchud-quota-push.sh:57-76` |
| A4 | Notification 降级:仅真权限请求算 `waiting`,否则降级 `idle` | `cchud-hook.sh:52-58` |
| A5 | 额度推送 30s 限频 | `cchud-update.sh:58-64` |
| A6 | 标题拼装 `模型名 (1M context)` | `cchud-quota-push.sh:82-100` |
| A7 | BLE 写入串行(不并发连同一设备) | `ble.lock` 机制 |
| A8 | 设备显示与现状一致(额度/成本/上下文/行数/状态/会话数) | v6 + state 字段 |
| A9 | BLE 不再每次推送重连(常驻连接) | 新增收益 |
| A10 | `cchud install claude` 一键写好 hook + statusLine | 替代手工编辑 settings.json |

## 二、现状盘点(迁移基线)

### 2.1 现有主机脚本职责

| 脚本 | 职责 | 关键隐含约定 |
|---|---|---|
| `cchud-hook.sh` | 应用状态:每会话写 `sessions/<sid>.state`,抢 `ble.lock` 后聚合推送 | 优先级聚合、TTL、Notification 降级、收敛重推(≤3 轮) |
| `cchud-statusline.sh` | statusLine 包装,转交 quota-push | — |
| `cchud-quota-push.sh` | 从 statusline JSON 抽额度/成本/标题,跨会话合并额度 | 按 resets_at 分窗取最大、标题拼装 |
| `cchud-update.sh` | 30s 限频 + 后台 fork + 抢 `ble.lock` 调 push_quota | 限频时间戳、共享 BLE 锁 |
| `push_quota.py` | v6 payload 编码 + BLE 写(直连/扫描/discover) | response=True 必须、重试 1 次 |
| `push_state.py` | 0x07 state payload 编码 + BLE 写 | total/busy 可选尾字节 |

### 2.2 现有 `/tmp` IPC 机制 → daemon 内存映射

这是迁移的核心:文件系统 IPC 在 daemon 内坍缩为内存状态。**每一项都必须有对应承接,否则丢行为。**

| 现有 `/tmp` 机制 | 作用 | daemon 内承接 |
|---|---|---|
| `cchud/sessions/<sid>.state` + mtime | 多进程间共享每会话状态 + 存活信号 | `SessionStore`:`dict[sid → SessionState]`,含 `last_seen` 时间戳 |
| `cchud/quota.state` + `quota-state.lock` | 跨会话额度合并 | `QuotaTracker`:内存中按窗口保留最大值 |
| `cchud/ble.lock`(mkdir 原子锁) | 串行化 BLE 访问(macOS 单连接) | `BleLink`:单一 asyncio 任务串行处理发送队列 |
| `cchud-last-push.ts` | 额度 30s 限频 | `QuotaTracker`:内存限频时间戳 |
| `cchud/last-pushed.state` | 状态去重(不变不推) | `Aggregator`:内存中上次推送指纹 |

### 2.3 固件 BLE 解析现状

- `ble_server.cpp` `QuotaCallbacks::onWrite` 按 `(length, msg_type)` 路由;已用 msg_type `0x01–0x0A`(见路线图 7.4 对照)。
- onConnect 已设 **DLE 251 + 请求 2M PHY**(`ble_server.cpp:284-298`),但**未主动设 ATT MTU**(依赖 central 协商,macOS 通常 ~185B)。
- `bleNotifyState` 回包限 20 字节(保守兼容 23B MTU)。

## 三、daemon 架构

### 3.1 进程与生命周期

- **单进程** `cchud-daemon`,Python(沿用 `bleak`,迁移成本最低;`asyncio` 事件循环统一驱动 socket 与 BLE)。
- **守护**:macOS `launchd` user agent(`~/Library/LaunchAgents/io.cchud.daemon.plist`),`KeepAlive=true` 崩溃自启,`RunAtLoad=true`。
- **日志**:`~/.cchud/daemon.log`(轮转);状态目录从 `/tmp/cchud` 迁到 `~/.cchud/`(跨重启保留),`/tmp` 仅留 socket。
- **socket**:Unix domain socket `~/.cchud/daemon.sock`。

### 3.2 模块边界

每个模块单一职责、可独立测试。

```
        hook 瘦客户端 ──JSON──► SocketServer
                                   │ 规范化(经 AdapterRegistry)
                                   ▼
                              CcHudEvent
                                   │
                ┌──────────────────┼───────────────────┐
                ▼                  ▼                     ▼
          SessionStore       QuotaTracker          (其它未来)
                └────────┬─────────┘
                         ▼
                     Aggregator  ── 计算聚合态/快照,去重 ──►  BleLink
                                                               │ v7 编码 + 串行发送队列
                                                               ▼
                                                          BLE 设备(常驻连接)
```

| 模块 | 职责 | 对应现状 |
|---|---|---|
| `SocketServer` | 监听 UDS,收 hook JSON,交 AdapterRegistry 规范化 | 替代"每 hook fork 进程" |
| `AdapterRegistry` | 持有各 adapter,按 client 字段路由 `normalize()` | 新增(地基) |
| `ClaudeAdapter` | 把 Claude hook/statusline 数据 → `CcHudEvent` | 迁移 `cchud-hook.sh` + `cchud-quota-push.sh` 逻辑 |
| `SessionStore` | 维护会话状态 + TTL 清理 | 承接 `sessions/*.state` |
| `QuotaTracker` | 额度分窗合并 + 限频 | 承接 `quota.state` + `last-push.ts` |
| `Aggregator` | 聚合态计算 + 快照组装 + 去重 | 承接 `cchud-hook.sh` 聚合 + `last-pushed.state` |
| `BleLink` | 常驻连接 + 重连退避 + v7 编码 + 串行发送 | 承接 `ble.lock` + `push_*.py` |

### 3.3 BleLink:常驻连接

- 启动后扫描/直连设备地址(`CCHUD_ADDR`),建立后**保持连接**;断线指数退避重连(0.5s→…→上限 30s)。
- 内部 `asyncio.Queue` 串行处理发送项,天然满足"不并发连同一设备",取代 `ble.lock`。
- 连接建立后**主动协商 MTU**(bleak 在 macOS 由系统协商,记录协商结果到日志;Linux 可显式 `client.mtu_size`),并校验是否满足单包阈值。
- 写入沿用 `response=True`(macOS + NimBLE 硬性要求)与单次重试。

## 四、Adapter 层与统一事件模型

### 4.1 `CcHudEvent`(规范化事件)

adapter 的唯一产物,核心逻辑只认它:

```python
@dataclass
class CcHudEvent:
    client_id: int            # 0=claude(第1层只有它);第2层扩展
    session_id: str
    kind: str                 # "state" | "quota" | "idle"
    # --- state 类 ---
    state: str | None         # idle|thinking|tool|waiting|done
    detail: str | None        # 工具名
    # --- quota 类 ---
    five_h_used: int | None    # 官方百分比
    five_h_resets_at: int | None
    seven_d_used: int | None
    seven_d_resets_at: int | None
    ctx_pct: int | None
    cost_usd: float | None
    duration_s: int | None
    lines_added: int | None
    lines_removed: int | None
    title: str | None
    mode: str | None          # sub|api
    ts: float                 # 事件接收时刻
```

### 4.2 `Adapter` 接口

```python
class Adapter(Protocol):
    client_id: int
    name: str
    def normalize(self, raw: dict) -> list[CcHudEvent]: ...   # 一条 hook 可产 0..N 事件
    def hook_spec(self) -> HookSpec: ...                      # 供 `cchud install` 写配置
```

### 4.3 `ClaudeAdapter`(迁移要点)

把现有两段 shell 逻辑搬进来,**逐项对应** 2.2 的隐含约定:

- 入参:hook 事件(含 `session_id`、`tool_name`、`message`)与 statusline JSON。
- `state` 事件:复刻 `cchud-hook.sh` 的状态映射;**A4 Notification 降级**——`message` 不含 permission/approve/confirm/needs-your 时降级 `idle`(第 3 层会改为细分 `INTERVENTION_KIND`,本层先保留降级,行为等价)。
- `quota` 事件:复刻 `cchud-quota-push.sh` 的字段抽取与 **A6 标题拼装**;跨会话合并交给 `QuotaTracker`(A3)。

## 五、Socket 事件协议(hook → daemon)

hook 脚本退化为瘦客户端:读 stdin → 包成 JSON → 写 socket → 立即退出(socket 不可用则**静默退出 0**,绝不阻塞客户端)。

```json
{ "client": "claude", "event": "PreToolUse", "payload": { /* 原始 hook stdin + statusline JSON */ } }
```

- daemon 侧由 `AdapterRegistry` 按 `client` 选 adapter 调 `normalize()`。
- 瘦 hook 用一个通用脚本 `cchud-emit.sh <client> <event>`(或编译版),所有客户端共用,差异在 daemon 的 adapter 里。

## 六、v7 TLV 固件侧实现

### 6.1 落点

在 `QuotaCallbacks::onWrite` 路由链尾部、回退分支前,新增:

```cpp
if (len >= 4 && data[0] == kQuotaMsgTypeV7Tlv) {   // 0x0B
    handleV7Tlv(data, len);
    return;
}
```

### 6.2 帧与解析(对应路线图 7.2/7.3)

- 帧头:`[0]=0x0B [1]=flags [2]=seq [3]=total`,其后为连续 `[tag][len][value]`。
- 第 1 层**所有帧保证单包**(等价字段总长 <100B < 协商 MTU),`flags.bit0=0, seq=0, total=1`。
- 解析循环:游标从 4 开始,逐字段读 `tag/len`,`len` 越界即 `kStateErrLen` 返回;**未知 tag 跳过**(读 len 跳 value),保证前向兼容。
- 把已知 tag 填进一个统一结构(扩展现有 `QuotaSnapshot` + 复用 state 分发):
  - 额度/成本/标题/上下文/行数 tag → 填 `QuotaSnapshot` → 调 `g_on_write`。
  - `AGG_STATE/ACTIVE_TOOL_NAME/TOTAL_SESSIONS/BUSY_SESSIONS` → 调 `g_on_state`。
  - `UNIX_TS/UTC_OFFSET_MIN/STATUS_STRING/IDLE_FORCE/MOOD_PREVIEW` → 调对应 idle 路径。
- **分片骨架**:本层解析 `seq/total` 字段但只接受 `total=1`;`total>1` 暂回 `kStateErrLen` 并日志告警。完整重组缓冲留到第 4 层(届时需要会话列表才超单包)。

### 6.3 MTU 加固(建议)

固件 `bleServerInit` 增加 `NimBLEDevice::setMTU(247)`(preferred),配合已有 DLE/2M PHY,确保单包阈值稳定;daemon 连接后记录实际协商值,低于阈值时日志告警并退回小帧策略。

### 6.4 新增常量(`config.h`)

`kQuotaMsgTypeV7Tlv = 0x0B`;v7 tag 枚举(按路线图 7.4 tag 表全量定义,本层只填充已规划字段,预留 tag 留空)。

## 七、CLI:`cchud`

| 子命令 | 行为 |
|---|---|
| `cchud install claude` | 写入 `~/.claude/settings.json` 的 5 个 hook + statusLine(指向 `cchud-emit.sh`);幂等、自动备份原配置 |
| `cchud status` | 探测 daemon 存活、BLE 连接、最近事件/推送、当前聚合态 |
| `cchud daemon` | 前台运行 daemon(调试用);正式由 launchd 拉起 |
| `cchud uninstall claude` | 还原 hook 配置 |

借鉴 ping-island `HookInstaller`/`ClientProfile` 思路:`hook_spec()` 由各 adapter 提供,`install` 通用。

## 八、迁移策略(解耦"架构重构"与"协议切换")

分两步落地,各自独立可回退,降低风险:

- **阶段 1a:架构重构,协议仍用 v6/0x07。** 建 daemon 全部模块 + ClaudeAdapter + socket + 瘦 hook;BleLink 先内联现有 v6 quota / 0x07 state 编码。此时固件**无需改动**,验证 A1–A10(除 A9 外行为等价 + 常驻连接)。
- **阶段 1b:协议切 v7。** 固件加 v7 解析(与旧并存);daemon BleLink 切 v7 编码。固件可单独 OTA 升级,daemon 通过开关回退 v6,保证新旧固件都能用。

旧脚本(`cchud-hook.sh` 等)在 1a 完成后保留一个版本周期作回退,确认稳定后删除。

## 九、回归验证清单

每条对应第一节验收项,给出可执行验证方式:

1. **A1/A2 聚合**:模拟 3 个 sid 并发写不同 state(含一个超 TTL),`cchud status` 应显示正确聚合态与会话计数。
2. **A3 额度合并**:用两份不同 `resets_at` 的 statusline JSON 喂入,确认新窗口替换、同窗口取最大。
3. **A4 降级**:发 `Notification` 含/不含 "permission" 两种 message,确认仅前者进 `waiting`。
4. **A5 限频**:连续高频 quota 事件,确认 BLE 写间隔 ≥30s。
5. **A6 标题**:喂含 `model.display_name` + `context_window_size` 的 JSON,确认标题为 `Opus 4.8 (1M context)`。
6. **A7 串行 / A9 常驻**:并发 quota+state 事件,确认 BLE 不并发、不重连(日志单一连接)。
7. **A8 显示**:真机比对额度/成本/上下文/行数/状态/会话数与重构前一致。
8. **v7**:固件 v7 帧解析单元测试(已知 tag、未知 tag 跳过、越界 len 报错、total>1 告警);真机 1b 后端到端比对。
9. **A10 安装**:干净环境 `cchud install claude` 后 settings.json 正确、备份生成、再次执行幂等。

## 十、风险与缓解

| 风险 | 缓解 |
|---|---|
| daemon 僵死导致设备停更 | launchd KeepAlive + `cchud status` 健康探测 + hook 静默降级不阻塞客户端 |
| 重构丢失隐含行为 | 第 2.2/2.3 节逐项映射 + 第九节逐条回归 |
| v7 与旧固件不兼容 | 1a/1b 解耦;daemon v6/v7 开关;旧路径原样保留 |
| MTU 协商不足 | 固件 setMTU(247) + daemon 记录协商值 + 单包阈值守护 |
| Python 常驻内存/稳定性 | 模块无状态化、定期 GC、日志监控;崩溃由 launchd 兜底 |

## 十一、后续

第 1 层 spec review 通过后进入 writing-plans,产出实现计划(建议拆分:① daemon 骨架+socket+SessionStore/QuotaTracker/Aggregator;② ClaudeAdapter 迁移+回归;③ BleLink 常驻连接;④ 固件 v7 解析;⑤ CLI install)。

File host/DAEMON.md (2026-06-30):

# CC-HUD Daemon 使用指南(第 1 层地基)

> 第 1 层把主机侧从"无状态 hook 脚本"重构为常驻 daemon。本文是 daemon 的安装、运行、协议与排错说明。旧脚本(`cchud-hook.sh` 等)仍保留作回退,但新接入请用 daemon。

## 1. 架构一览

```
各客户端 hooks ──► cchud-emit.sh(瘦客户端,投递 JSON)
                       │ Unix domain socket (~/.cchud/daemon.sock)
                       ▼
              cchud-daemon(常驻 Python 进程)
               ├ AdapterRegistry → ClaudeAdapter   把原生 hook/statusline 规范化为 CcHudEvent
               ├ SessionStore     多会话状态 + TTL(300s)
               ├ QuotaTracker     额度按 resets_at 分窗取最大 + 30s 限频
               ├ Aggregator       聚合态(waiting>tool>thinking>idle)+ 去重
               └ BleLink          常驻 BLE 连接 + 串行发送 + v6/v7 编码
                       │ BLE
                       ▼
                   CC-HUD 设备(固件解析 v1-v7)
```

模块代码在 `host/cchud_daemon/`,每个文件单一职责;纯逻辑模块(codec/quota_tracker/aggregator/session_store)均有单测(`host/tests/`,`pytest` 全绿)。

## 2. 安装

> ⚠️ **Python 必须 ≥ 3.10**(推荐 3.12)。3.9 下 `asyncio.Queue/Event` 在 `BleLink.__init__`(`asyncio.run` 之前)绑死旧事件循环,daemon 一跑 BLE 全程 `got Future attached to a different loop`。重建 venv:`python3.12 -m venv host/.venv`。

```bash
# 1) 依赖(首次):bleak 给 daemon;构建固件还需 platformio
host/.venv/bin/python -m pip install bleak

# 2) 找设备地址(macOS 是 CoreBluetooth UUID),用环境变量注入(别改脚本里的默认地址)
host/.venv/bin/python host/push_quota.py --discover --verbose
echo 'export CCHUD_ADDR=<设备UUID>' >> ~/.zshrc && source ~/.zshrc

# 3) 一键装 hooks(Claude / Codex 各一条;CCHUD_USE_V7=1 配 v7 固件)
CCHUD_ADDR=$CCHUD_ADDR CCHUD_USE_V7=1 host/.venv/bin/python -m cchud_daemon.cli install claude
CCHUD_ADDR=$CCHUD_ADDR CCHUD_USE_V7=1 host/.venv/bin/python -m cchud_daemon.cli install codex
```

`install claude` 会:
- 把 5 个 hook(UserPromptSubmit/PreToolUse/PostToolUse/Stop/Notification)与 statusLine 写入 `~/.claude/settings.json`,**保留该事件下已有的第三方 hook**,仅首次写入 `settings.json.cchud-bak` 备份。
- 渲染 `~/Library/LaunchAgents/io.cchud.daemon.plist`(含 `CCHUD_ADDR`/`CCHUD_USE_V7`)。
- ⚠️ 若你曾用过旧的 `cchud-hook.sh` 直推 hook,install **不会**自动删它(只识别 `cchud-emit.sh` 旧条目)→ 需手动从 `settings.json` 删掉含 `cchud-hook.sh` 的条目,否则新旧抢 BLE。

`install codex` 会:
- 写 `~/.codex/hooks.json`(5 个 `cchud-emit.sh codex` 事件,保留 ping-island/r2c 等第三方 hook)。
- ⚠️ **不要往 `~/.codex/config.toml` 写 `hooks = true`**——新版 Codex 报 `invalid type: boolean, expected struct HooksToml` 起不来。Codex **自动加载** `~/.codex/hooks.json`;**重启 Codex 后按提示 `Trust hooks`** 才生效(信任态由 Codex 自己写进 config.toml 的 `[hooks.state]`)。

> statusLine 指向 `cchud-statusline.sh`,它**保留 ccstatusline 渲染** + 后台把额度 JSON 投递给 daemon,状态栏显示不受影响。本机没装 `bun` 就把里面的 `bunx` 改 `npx`。

## 3. 运行

> ⚠️ **macOS 蓝牙权限**:daemon 必须从**有蓝牙授权的终端**(Terminal/iTerm)启动。launchd 拉起的进程拿不到蓝牙 TCC 授权、又不弹框,会 `BLE is not authorized` 静默失败。所以 macOS 上**别用 launchd 常驻**,用终端跑(可配 tmux / `nohup` 保活)。

```bash
# 常驻运行(从有蓝牙权限的终端;cwd=host 时 -m 能找到包,无需 PYTHONPATH)
cd host && CCHUD_ADDR=$CCHUD_ADDR CCHUD_USE_V7=1 .venv/bin/python -m cchud_daemon.cli daemon
# 首次连接 macOS 弹蓝牙授权 → 点允许

# 查看状态(socket / 日志末尾)
host/.venv/bin/python -m cchud_daemon.cli status
```

| 环境变量 | 含义 |
|---|---|
| `CCHUD_ADDR` | 设备 BLE 地址 / macOS 外设 UUID(必需) |
| `CCHUD_USE_V7` | `1` 时 quota 走 v7 TLV(`0x0B`),否则 v6(`0x0A`) |

## 4. 协议:v6 与 v7

- **v6(默认)**:固定布局 `0x0A` 帧,与旧 `push_quota.py` 字节一致。
- **v7(`CCHUD_USE_V7=1`)**:TLV 可扩展帧 `0x0B`,`[msg_type][flags][seq][total]` + 连续 `[tag][len][value]`。tag 表见 `docs/superpowers/specs/2026-06-24-cc-hud-roadmap-design.md` 7.4 节。固件未知 tag 跳过,`total!=1` 拒绝(分片留待第 4 层)。旧 v1–v6 路径在固件中原样保留。
- 两种编码表达同一份数据,设备显示等价(已真机验证)。

## 5. 排错

| 现象 | 原因 / 处理 |
|---|---|
| 发了一帧但设备没更新 | **30s 限频**:`QuotaTracker` 同一窗口 30s 内只推一次。即时验证请等 30s 或临时停 daemon 直接用脚本推。 |
| 设备显示旧额度值 | 多半是限频拦了新帧,显示的是上次推送。等下一次 statusline 触发即可。 |
| ctx/成本/代码行"看不到" | 这些在 STATS 轮播页(stage 2/3),HUD 额度页只显示额度。等轮播或短按翻页。 |
| daemon 终端无日志 | 成功路径不打印,只有 BLE 连接/写入失败才 `warning`。属正常。 |
| 调试时连不上设备 | daemon 常驻独占 BLE 连接(macOS 单连接)。先停 daemon 再用 `push_*.py` 直连。 |
| daemon 起来但不推送 | 检查进程环境 `CCHUD_ADDR` 是否非空(launchd 不继承 shell 环境,靠 plist 的 `EnvironmentVariables`)。 |
| daemon 一跑 BLE 就 `attached to a different loop` | **Python 3.9 的坑**:升到 ≥3.10(`python3.12 -m venv host/.venv` 重建并装 `bleak`)。 |
| daemon `BLE is not authorized` | macOS 蓝牙 TCC 不授权 launchd 进程。改从有蓝牙权限的终端跑 daemon(见 §3)。 |
| BLE 失败看不到日志 | warning 走 **stderr**,不是 `~/.cchud/daemon.log`(那个常空)。前台跑看终端,后台跑看重定向的 stderr。 |
| Codex 启动报 `expected struct HooksToml` | config.toml 里写了 `hooks = true`,删掉。Codex 自动读 `~/.codex/hooks.json`,重启后 `Trust hooks` 即可。 |
| Codex 状态不上报 | 装完 hooks 后**没重启 Codex 或没 Trust hooks**。重启 Codex,按提示信任 hooks。 |

## 6. 已知限制(后续层处理)

- **状态帧仍走 `0x07`**(非 v7),quota 才走 v7;状态 v7 化留待第 2 层。
- v7 `title` 用 UTF-8,固件 `title` 缓冲按字节截断,非 ASCII 标题可能截断;第 2 层引入非 ASCII 客户端名前需处理。
- BLE OTA 慢(实测约 2.7 KB/s);大固件建议用 WiFi OTA(`pio run -e esp32s3_nano_wifi -t upload`)。

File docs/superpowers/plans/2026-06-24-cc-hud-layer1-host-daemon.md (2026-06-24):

# CC-HUD 第 1 层(地基)实现计划

> **For agentic workers:** REQUIRED SUB-SKILL: Use superpowers:subagent-driven-development (recommended) or superpowers:executing-plans to implement this plan task-by-task. Steps use checkbox (`- [ ]`) syntax for tracking.

**Goal:** 把 CC-HUD 主机侧从无状态 hook 脚本重构为常驻 `cchud-daemon`(adapter 层 + 内存状态 + 常驻 BLE),并在固件接入 v7 TLV 解析,保证 Claude 现有能力功能等价。

**Architecture:** daemon 用 Python(asyncio + bleak),hook 退化为瘦客户端经 Unix domain socket 投递事件;事件经 adapter 规范化为 `CcHudEvent`,流经 SessionStore/QuotaTracker/Aggregator,由单一 BleLink 任务串行编码下发。固件新增 `0x0B` TLV 分支,解析逻辑剥离为可 native 单测的纯函数。

**Tech Stack:** Python 3.13(uv venv)、pytest、bleak、Arduino/NimBLE(ESP32-S3)、PlatformIO native test。

## Global Constraints

- daemon 语言:Python,沿用 `host/.venv`(Python 3.13.2)与 `bleak` BLE 栈。
- 状态目录迁至 `~/.cchud/`(跨重启保留);`/tmp` 仅保留 socket 路径 `~/.cchud/daemon.sock`。
- 新 BLE msg_type:`0x0B = V7_TLV`;旧 `0x01–0x0A` 路径原样保留、不改。
- v7 帧头:`[0]=0x0B [1]=flags [2]=seq [3]=total`,其后连续 `[tag:u8][len:u8][value]`;本层所有帧单包(`flags=0,seq=0,total=1`)。
- v7 tag 取值严格依据 `docs/superpowers/specs/2026-06-24-cc-hud-roadmap-design.md` 7.4 节 tag 表。
- BLE 写入 `response=True`(macOS + NimBLE 硬性要求),失败重试 1 次。
- 迁移解耦:阶段 1a 架构重构仍用 v6/0x07 编码;阶段 1b 切 v7。BleLink 以开关切换编码版本。
- 提交规范:Conventional Commits 英文标题,正文中文,**禁止任何 AI 署名/Co-Authored-By**。
- 注释、日志文案用简体中文;标识符、错误码、字段名保持原文。

---

## 文件结构

新建 daemon 包 `host/cchud_daemon/`,按职责拆分:

| 文件 | 职责 |
|---|---|
| `host/cchud_daemon/__init__.py` | 包标记 |
| `host/cchud_daemon/event.py` | `CcHudEvent` 数据类 |
| `host/cchud_daemon/session_store.py` | `SessionStore`:会话状态 + TTL |
| `host/cchud_daemon/quota_tracker.py` | `QuotaTracker`:额度分窗合并 + 限频 |
| `host/cchud_daemon/aggregator.py` | `Aggregator`:聚合态 + 快照 + 去重 |
| `host/cchud_daemon/codec.py` | v6 兼容编码 + v7 TLV 编码(纯函数) |
| `host/cchud_daemon/adapters/base.py` | `Adapter` 协议 + `HookSpec` |
| `host/cchud_daemon/adapters/claude.py` | `ClaudeAdapter` |
| `host/cchud_daemon/registry.py` | `AdapterRegistry` |
| `host/cchud_daemon/socket_server.py` | `SocketServer`:UDS 监听 |
| `host/cchud_daemon/ble_link.py` | `BleLink`:常驻连接 + 发送队列 |
| `host/cchud_daemon/daemon.py` | 组装 + asyncio 主循环 |
| `host/cchud_daemon/cli.py` | `cchud` CLI(install/status/daemon) |
| `host/cchud-emit.sh` | 通用瘦 hook 客户端 |
| `host/io.cchud.daemon.plist` | launchd user agent 模板 |
| `host/tests/*.py` | pytest 单元测试 |
| `host/pyproject.toml` | pytest 配置 + dev 依赖声明 |
| `firmware/src/v7_tlv.h` / `v7_tlv.cpp` | v7 TLV 纯解析(不依赖 NimBLE) |
| `firmware/test/test_v7_tlv/test_v7_tlv.cpp` | native 单元测试 |

---

## Task 1: 测试设施 + CcHudEvent + SessionStore

**Files:**
- Create: `host/pyproject.toml`
- Create: `host/cchud_daemon/__init__.py`
- Create: `host/cchud_daemon/event.py`
- Create: `host/cchud_daemon/session_store.py`
- Test: `host/tests/test_session_store.py`

**Interfaces:**
- Produces:
  - `CcHudEvent`(dataclass,字段见 spec 4.1;本层 `client_id:int, session_id:str, kind:str, state:str|None, detail:str|None, five_h_used:int|None, five_h_resets_at:int|None, seven_d_used:int|None, seven_d_resets_at:int|None, ctx_pct:int|None, cost_usd:float|None, duration_s:int|None, lines_added:int|None, lines_removed:int|None, title:str|None, mode:str|None, ts:float`)
  - `SessionStore(ttl_s: float = 300.0)`,方法:`update(session_id: str, state: str, detail: str, now: float) -> None`、`live_states(now: float) -> list[tuple[str, str]]`(返回 `(state, detail)`,已剔除过期)、`counts(now: float) -> tuple[int, int]`(返回 `(total, busy)`,busy = 非 idle 数)。

- [ ] **Step 1: 建 pytest 配置与 dev 依赖**

`host/pyproject.toml`:

```toml
[project]
name = "cchud-daemon"
version = "0.1.0"
requires-python = ">=3.13"
dependencies = ["bleak>=0.21"]

[project.optional-dependencies]
dev = ["pytest>=8.0", "pytest-asyncio>=0.23"]

[tool.pytest.ini_options]
testpaths = ["tests"]
asyncio_mode = "auto"
```

安装:`host/.venv/bin/python -m pip install -e 'host[dev]'`

- [ ] **Step 2: 写失败测试**

`host/tests/test_session_store.py`:

```python
from cchud_daemon.session_store import SessionStore

def test_busy_session_counts_and_states():
    s = SessionStore(ttl_s=300)
    s.update("a", "thinking", "", now=1000)
    s.update("b", "tool", "Bash", now=1000)
    s.update("c", "idle", "", now=1000)
    assert s.counts(now=1000) == (3, 2)         # total=3, busy=2(idle 不计)
    assert ("tool", "Bash") in s.live_states(now=1000)

def test_expired_sessions_are_swept():
    s = SessionStore(ttl_s=300)
    s.update("old", "tool", "Bash", now=1000)
    s.update("new", "thinking", "", now=1400)
    # old 已超 300s(now=1400),应被剔除
    assert s.counts(now=1400) == (1, 1)
    assert s.live_states(now=1400) == [("thinking", "")]
```

- [ ] **Step 3: 运行测试确认失败**

Run: `cd host && .venv/bin/python -m pytest tests/test_session_store.py -v`
Expected: FAIL（ModuleNotFoundError: cchud_daemon.session_store）

- [ ] **Step 4: 写最小实现**

`host/cchud_daemon/__init__.py`:空文件。

`host/cchud_daemon/event.py`:

```python
from __future__ import annotations
from dataclasses import dataclass

@dataclass
class CcHudEvent:
    client_id: int
    session_id: str
    kind: str                       # "state" | "quota" | "idle"
    state: str | None = None
    detail: str | None = None
    five_h_used: int | None = None
    five_h_resets_at: int | None = None
    seven_d_used: int | None = None
    seven_d_resets_at: int | None = None
    ctx_pct: int | None = None
    cost_usd: float | None = None
    duration_s: int | None = None
    lines_added: int | None = None
    lines_removed: int | None = None
    title: str | None = None
    mode: str | None = None
    ts: float = 0.0
```

`host/cchud_daemon/session_store.py`:

```python
from __future__ import annotations

# 状态优先级:waiting > tool > thinking > idle(复刻 cchud-hook.sh)
_PRIORITY = {"waiting": 3, "tool": 2, "thinking": 1, "idle": 0}

class SessionStore:
    """每会话最新状态 + 最后活动时刻;过期会话视为已结束(复刻 TTL 扫描)。"""

    def __init__(self, ttl_s: float = 300.0) -> None:
        self._ttl = ttl_s
        self._sessions: dict[str, tuple[str, str, float]] = {}

    def update(self, session_id: str, state: str, detail: str, now: float) -> None:
        self._sessions[session_id] = (state, detail, now)

    def _sweep(self, now: float) -> None:
        dead = [sid for sid, (_, _, ts) in self._sessions.items()
                if now - ts > self._ttl]
        for sid in dead:
            del self._sessions[sid]

    def live_states(self, now: float) -> list[tuple[str, str]]:
        self._sweep(now)
        return [(st, det) for (st, det, _) in self._sessions.values()]

    def counts(self, now: float) -> tuple[int, int]:
        self._sweep(now)
        total = len(self._sessions)
        busy = sum(1 for (st, _, _) in self._sessions.values()
                   if _PRIORITY.get(st, 0) > 0)
        return total, busy
```

- [ ] **Step 5: 运行测试确认通过**

Run: `cd host && .venv/bin/python -m pytest tests/test_session_store.py -v`
Expected: PASS（2 passed）

- [ ] **Step 6: 提交**

```bash
git add host/pyproject.toml host/cchud_daemon/__init__.py host/cchud_daemon/event.py host/cchud_daemon/session_store.py host/tests/test_session_store.py
git commit -m "feat: 新增 daemon 测试设施 + CcHudEvent + SessionStore"
```

---

## Task 2: QuotaTracker(额度分窗合并 + 限频)

**Files:**
- Create: `host/cchud_daemon/quota_tracker.py`
- Test: `host/tests/test_quota_tracker.py`

**Interfaces:**
- Consumes: 无(纯逻辑)。
- Produces:
  - `QuotaTracker(rate_limit_s: float = 30.0)`,方法:
    - `merge(used: int, resets_at: int, window: str, now: float) -> tuple[int, int]`:`window` 为 `"5h"|"7d"`;按 `resets_at` 分窗——`resets_at` 更大则替换(处理归零),相等则取较大 used;返回合并后 `(used, resets_at)`。
    - `should_push(now: float) -> bool`:距上次 `mark_pushed` 不足 `rate_limit_s` 返回 `False`。
    - `mark_pushed(now: float) -> None`。

- [ ] **Step 1: 写失败测试**

`host/tests/test_quota_tracker.py`:

```python
from cchud_daemon.quota_tracker import QuotaTracker

def test_merge_takes_max_in_same_window():
    q = QuotaTracker()
    assert q.merge(40, 2000, "5h", now=1000) == (40, 2000)
    # 同窗口(resets_at 相同),取较大 used
    assert q.merge(35, 2000, "5h", now=1001) == (40, 2000)
    assert q.merge(55, 2000, "5h", now=1002) == (55, 2000)

def test_merge_replaces_on_newer_window():
    q = QuotaTracker()
    q.merge(90, 2000, "5h", now=1000)
    # 新窗口(resets_at 更大)→ 直接替换,处理用量归零
    assert q.merge(5, 9000, "5h", now=2001) == (5, 9000)

def test_rate_limit():
    q = QuotaTracker(rate_limit_s=30)
    assert q.should_push(now=1000) is True
    q.mark_pushed(now=1000)
    assert q.should_push(now=1020) is False    # 不足 30s
    assert q.should_push(now=1031) is True      # 超过 30s
```

- [ ] **Step 2: 运行测试确认失败**

Run: `cd host && .venv/bin/python -m pytest tests/test_quota_tracker.py -v`
Expected: FAIL（ModuleNotFoundError）

- [ ] **Step 3: 写最小实现**

`host/cchud_daemon/quota_tracker.py`:

```python
from __future__ import annotations

class QuotaTracker:
    """额度跨会话分窗合并 + BLE 推送限频(复刻 cchud-quota-push.sh / cchud-update.sh)。"""

    def __init__(self, rate_limit_s: float = 30.0) -> None:
        self._rate = rate_limit_s
        self._last_push: float | None = None
        # window -> (used, resets_at)
        self._win: dict[str, tuple[int, int]] = {}

    def merge(self, used: int, resets_at: int, window: str, now: float) -> tuple[int, int]:
        cur = self._win.get(window)
        if cur is None or resets_at > cur[1]:
            merged = (used, resets_at)
        elif resets_at == cur[1]:
            merged = (max(used, cur[0]), resets_at)
        else:
            merged = cur                       # incoming 是旧窗口,忽略
        self._win[window] = merged
        return merged

    def should_push(self, now: float) -> bool:
        return self._last_push is None or (now - self._last_push) >= self._rate

    def mark_pushed(self, now: float) -> None:
        self._last_push = now
```

- [ ] **Step 4: 运行测试确认通过**

Run: `cd host && .venv/bin/python -m pytest tests/test_quota_tracker.py -v`
Expected: PASS（3 passed）

- [ ] **Step 5: 提交**

```bash
git add host/cchud_daemon/quota_tracker.py host/tests/test_quota_tracker.py
git commit -m "feat: 新增 QuotaTracker 额度分窗合并与限频"
```

---

## Task 3: Aggregator(聚合态 + 去重)

**Files:**
- Create: `host/cchud_daemon/aggregator.py`
- Test: `host/tests/test_aggregator.py`

**Interfaces:**
- Consumes: `SessionStore`(Task 1)。
- Produces:
  - `Aggregator()`,方法:
    - `aggregate(store: SessionStore, now: float) -> tuple[str, str, int, int]`:返回 `(state, detail, total, busy)`,state 取优先级最高者(`waiting>tool>thinking>idle`),detail 取该会话的 detail;无会话返回 `("idle","",0,0)`。
    - `changed(key: tuple) -> bool`:与上次 `aggregate` 结果指纹比较,变了返回 `True` 并记录;不变返回 `False`(复刻 `last-pushed.state` 去重)。

- [ ] **Step 1: 写失败测试**

`host/tests/test_aggregator.py`:

```python
from cchud_daemon.aggregator import Aggregator
from cchud_daemon.session_store import SessionStore

def test_aggregate_picks_highest_priority():
    s = SessionStore()
    s.update("a", "thinking", "", now=1000)
    s.update("b", "tool", "Bash", now=1000)
    agg = Aggregator()
    assert agg.aggregate(s, now=1000) == ("tool", "Bash", 2, 2)

def test_aggregate_empty_is_idle():
    assert Aggregator().aggregate(SessionStore(), now=1000) == ("idle", "", 0, 0)

def test_changed_dedup():
    agg = Aggregator()
    key = ("tool", "Bash", 2, 2)
    assert agg.changed(key) is True     # 首次
    assert agg.changed(key) is False    # 不变
    assert agg.changed(("idle", "", 0, 0)) is True
```

- [ ] **Step 2: 运行测试确认失败**

Run: `cd host && .venv/bin/python -m pytest tests/test_aggregator.py -v`
Expected: FAIL（ModuleNotFoundError）

- [ ] **Step 3: 写最小实现**

`host/cchud_daemon/aggregator.py`:

```python
from __future__ import annotations

from .session_store import SessionStore, _PRIORITY

class Aggregator:
    """把多会话聚合为单一推送态,并对不变结果去重(复刻 cchud-hook.sh)。"""

    def __init__(self) -> None:
        self._last_key: tuple | None = None

    def aggregate(self, store: SessionStore, now: float) -> tuple[str, str, int, int]:
        best_state, best_detail, best_p = "idle", "", -1
        for state, detail in store.live_states(now):
            p = _PRIORITY.get(state, 0)
            if p > best_p:
                best_p, best_state, best_detail = p, state, detail
        total, busy = store.counts(now)
        return best_state, best_detail, total, busy

    def changed(self, key: tuple) -> bool:
        if key == self._last_key:
            return False
        self._last_key = key
        return True
```

- [ ] **Step 4: 运行测试确认通过**

Run: `cd host && .venv/bin/python -m pytest tests/test_aggregator.py -v`
Expected: PASS（3 passed）

- [ ] **Step 5: 提交**

```bash
git add host/cchud_daemon/aggregator.py host/tests/test_aggregator.py
git commit -m "feat: 新增 Aggregator 多会话聚合与去重"
```

---

## Task 4: codec(v6 兼容编码 + v7 TLV 编码)

**Files:**
- Create: `host/cchud_daemon/codec.py`
- Test: `host/tests/test_codec.py`

**Interfaces:**
- Consumes: 无。
- Produces:
  - `encode_quota_v6(*, mode:int, h5_used:int, h5_limit:int, d7_used:int, d7_limit:int, h5_reset_s:int, d7_reset_s:int, cost_micro_usd:int, duration_s:int, ctx_pct:int, lines_added:int, lines_removed:int, title:str) -> bytes`(从 `push_quota.py:_pack_payload_v6` 抽取,字节布局完全一致)。
  - `encode_state_0x07(state_code:int, detail:str, total:int, busy:int) -> bytes`(从 `push_state.py:pack_state` 抽取)。
  - v7 tag 常量(`TAG_FIVE_H_USED_PCT=0x01` … 见 spec 7.4)。
  - `encode_v7(fields: list[tuple[int, bytes]]) -> bytes`:组帧 `0x0B,flags=0,seq=0,total=1` + 连续 `[tag][len][value]`;单字段 `len>255` 抛 `ValueError`。
  - `tlv_u8(tag:int, v:int)->tuple[int,bytes]`、`tlv_u16(...)`、`tlv_u32(...)`、`tlv_str(tag:int, s:str)->tuple[int,bytes]` 辅助。

- [ ] **Step 1: 写失败测试**

`host/tests/test_codec.py`:

```python
import struct
from cchud_daemon import codec

def test_v6_matches_legacy_layout():
    # 与 push_quota.py 的 _pack_payload_v6 字节级一致
    p = codec.encode_quota_v6(
        mode=0, h5_used=40, h5_limit=100, d7_used=28, d7_limit=100,
        h5_reset_s=120, d7_reset_s=3600, cost_micro_usd=420000,
        duration_s=23, ctx_pct=65, lines_added=127, lines_removed=45,
        title="Opus 4.8 (1M context)")
    assert p[0] == 0x0A                       # v6 msg_type
    title_b = "Opus 4.8 (1M context)".encode("ascii")[:32]
    assert p[-len(title_b):] == title_b
    assert p[35] == len(title_b)              # title_len 偏移

def test_state_0x07_layout():
    p = codec.encode_state_0x07(2, "Bash", total=3, busy=2)
    assert p[0] == 0x07 and p[1] == 2 and p[2] == 4
    assert p[3:7] == b"Bash"
    assert p[7] == 3 and p[8] == 2            # total, busy 尾字节

def test_v7_frame_and_tlv():
    frame = codec.encode_v7([
        codec.tlv_u8(codec.TAG_FIVE_H_USED_PCT, 40),
        codec.tlv_str(codec.TAG_TITLE, "Opus"),
    ])
    assert frame[:4] == bytes([0x0B, 0, 0, 1])         # 头
    # 第一个字段:tag=0x01 len=1 value=40
    assert frame[4] == 0x01 and frame[5] == 1 and frame[6] == 40
    # 第二个字段:tag=TAG_TITLE len=4 "Opus"
    off = 7
    assert frame[off] == codec.TAG_TITLE and frame[off + 1] == 4
    assert frame[off + 2:off + 6] == b"Opus"

def test_v7_rejects_oversize_field():
    import pytest
    with pytest.raises(ValueError):
        codec.encode_v7([codec.tlv_str(codec.TAG_TITLE, "x" * 300)])
```

- [ ] **Step 2: 运行测试确认失败**

Run: `cd host && .venv/bin/python -m pytest tests/test_codec.py -v`
Expected: FAIL（ModuleNotFoundError）

- [ ] **Step 3: 写最小实现**

`host/cchud_daemon/codec.py`:

```python
from __future__ import annotations
import struct

# ── v7 tag 常量(对照路线图 7.4)────────────────────────────────────────
TAG_FIVE_H_USED_PCT      = 0x01
TAG_FIVE_H_RESET_IN_S    = 0x02
TAG_SEVEN_D_USED_PCT     = 0x03
TAG_SEVEN_D_RESET_IN_S   = 0x04
TAG_CONTEXT_USED_PCT     = 0x05
TAG_COST_MICRO_USD       = 0x06
TAG_DURATION_S           = 0x07
TAG_LINES_ADDED          = 0x08
TAG_LINES_REMOVED        = 0x09
TAG_PLAN_MODE            = 0x0A
TAG_TITLE                = 0x0B
TAG_AGG_STATE            = 0x20
TAG_ACTIVE_TOOL_NAME     = 0x21
TAG_TOTAL_SESSIONS       = 0x22
TAG_BUSY_SESSIONS        = 0x23
TAG_UNIX_TS              = 0x80
TAG_UTC_OFFSET_MIN       = 0x81
TAG_STATUS_STRING        = 0x84

MSG_V7_TLV = 0x0B

def encode_quota_v6(*, mode, h5_used, h5_limit, d7_used, d7_limit,
                    h5_reset_s, d7_reset_s, cost_micro_usd, duration_s,
                    ctx_pct, lines_added, lines_removed, title) -> bytes:
    title_b = title.encode("ascii", errors="replace")[:32]
    fixed = struct.pack(
        "<BBHHHHIIIIBIIB",
        0x0A, mode & 0xFF,
        h5_used, h5_limit, d7_used, d7_limit,
        h5_reset_s, d7_reset_s,
        cost_micro_usd, duration_s,
        max(0, min(100, ctx_pct)),
        max(0, lines_added), max(0, lines_removed),
        len(title_b),
    )
    return fixed + title_b

def encode_state_0x07(state_code: int, detail: str, total: int, busy: int) -> bytes:
    d = detail.encode("ascii", errors="replace")[:15]
    base = struct.pack("<BBB", 0x07, state_code, len(d)) + d
    base += struct.pack("<BB", min(255, max(0, total)), min(255, max(0, busy)))
    return base

def tlv_u8(tag: int, v: int) -> tuple[int, bytes]:
    return tag, struct.pack("<B", v & 0xFF)

def tlv_u16(tag: int, v: int) -> tuple[int, bytes]:
    return tag, struct.pack("<H", v & 0xFFFF)

def tlv_u32(tag: int, v: int) -> tuple[int, bytes]:
    return tag, struct.pack("<I", v & 0xFFFFFFFF)

def tlv_str(tag: int, s: str) -> tuple[int, bytes]:
    return tag, s.encode("utf-8", errors="replace")

def encode_v7(fields: list[tuple[int, bytes]]) -> bytes:
    out = bytearray([MSG_V7_TLV, 0, 0, 1])      # msg_type, flags, seq, total
    for tag, value in fields:
        if len(value) > 255:
            raise ValueError(f"tag 0x{tag:02X} value too long: {len(value)}")
        out += bytes([tag & 0xFF, len(value)]) + value
    return bytes(out)
```

- [ ] **Step 4: 运行测试确认通过**

Run: `cd host && .venv/bin/python -m pytest tests/test_codec.py -v`
Expected: PASS（4 passed）

- [ ] **Step 5: 提交**

```bash
git add host/cchud_daemon/codec.py host/tests/test_codec.py
git commit -m "feat: 新增 codec(v6 兼容编码 + v7 TLV 编码)"
```

---

## Task 5: ClaudeAdapter(规范化 + 行为复刻)

**Files:**
- Create: `host/cchud_daemon/adapters/__init__.py`
- Create: `host/cchud_daemon/adapters/base.py`
- Create: `host/cchud_daemon/adapters/claude.py`
- Test: `host/tests/test_claude_adapter.py`

**Interfaces:**
- Consumes: `CcHudEvent`(Task 1)。
- Produces:
  - `HookSpec`(dataclass:`events: dict[str,str]`,`statusline_wrapper: str | None`)。
  - `Adapter`(Protocol:`client_id:int`、`name:str`、`normalize(raw:dict)->list[CcHudEvent]`、`hook_spec()->HookSpec`)。
  - `ClaudeAdapter(client_id=0)`:`normalize` 接受 `{"event":..., "payload":{...}}`,产出事件:
    - `PreToolUse` → state=tool,detail=tool_name;`UserPromptSubmit`/`PostToolUse` → thinking;`Stop` → idle;
    - `Notification` → 仅 message 含 permission/approve/confirm/"needs your" 时 state=waiting,否则 state=idle(复刻降级);
    - `Status` → payload 本身即 statusline JSON(emit 透传 statusLine 的 stdin),产出 kind=quota 事件(抽 5h/7d used%+resets_at、ctx_pct、cost、duration、行数、标题)。

- [ ] **Step 1: 写失败测试**

`host/tests/test_claude_adapter.py`:

```python
from cchud_daemon.adapters.claude import ClaudeAdapter

def test_pretooluse_maps_to_tool():
    a = ClaudeAdapter()
    evs = a.normalize({"event": "PreToolUse",
                       "payload": {"session_id": "s1", "tool_name": "Bash"}})
    e = [x for x in evs if x.kind == "state"][0]
    assert e.state == "tool" and e.detail == "Bash" and e.session_id == "s1"

def test_notification_permission_is_waiting():
    a = ClaudeAdapter()
    evs = a.normalize({"event": "Notification",
                       "payload": {"session_id": "s1",
                                   "message": "Claude needs your permission to run Bash"}})
    assert [x for x in evs if x.kind == "state"][0].state == "waiting"

def test_notification_benign_downgrades_to_idle():
    a = ClaudeAdapter()
    evs = a.normalize({"event": "Notification",
                       "payload": {"session_id": "s1",
                                   "message": "Claude is waiting for your input"}})
    assert [x for x in evs if x.kind == "state"][0].state == "idle"

def test_statusline_produces_quota_event_with_title():
    a = ClaudeAdapter()
    # payload 本身即 statusLine 的 stdin JSON(emit 原样透传)
    payload = {"session_id": "s1",
        "rate_limits": {"five_hour": {"used_percentage": 40, "resets_at": 2000},
                        "seven_day": {"used_percentage": 28, "resets_at": 9000}},
        "context_window": {"used_percentage": 65, "context_window_size": 1000000},
        "cost": {"total_cost_usd": 0.42, "total_duration_ms": 23000,
                 "total_lines_added": 127, "total_lines_removed": 45},
        "model": {"display_name": "Opus 4.8"}}
    q = [x for x in a.normalize({"event": "Status", "payload": payload})
         if x.kind == "quota"][0]
    assert q.five_h_used == 40 and q.seven_d_resets_at == 9000
    assert q.ctx_pct == 65 and q.lines_added == 127
    assert q.title == "Opus 4.8 (1M context)"
```

- [ ] **Step 2: 运行测试确认失败**

Run: `cd host && .venv/bin/python -m pytest tests/test_claude_adapter.py -v`
Expected: FAIL（ModuleNotFoundError）

- [ ] **Step 3: 写最小实现**

`host/cchud_daemon/adapters/__init__.py`:空文件。

`host/cchud_daemon/adapters/base.py`:

```python
from __future__ import annotations
from dataclasses import dataclass, field
from typing import Protocol
from ..event import CcHudEvent

@dataclass
class HookSpec:
    events: dict[str, str] = field(default_factory=dict)   # 事件名 -> emit 参数
    statusline_wrapper: str | None = None                  # statusLine 包装脚本文件名(同 emit 目录)

class Adapter(Protocol):
    client_id: int
    name: str
    def normalize(self, raw: dict) -> list[CcHudEvent]: ...
    def hook_spec(self) -> HookSpec: ...
```

`host/cchud_daemon/adapters/claude.py`:

```python
from __future__ import annotations
from ..event import CcHudEvent
from .base import HookSpec

# 复刻 cchud-hook.sh 的 Notification 降级关键词
_PERMISSION_HINTS = ("permission", "Permission", "approve", "Approve",
                     "needs your", "confirm", "Confirm")

_EVENT_STATE = {
    "UserPromptSubmit": "thinking",
    "PostToolUse": "thinking",
    "PreToolUse": "tool",
    "Stop": "idle",
}

def _fmt_ctx_size(n: int) -> str:
    if n >= 1_000_000:
        return f"{n // 1_000_000}M"
    if n >= 1000:
        return f"{n // 1000}K"
    return ""

class ClaudeAdapter:
    client_id = 0
    name = "claude"

    def normalize(self, raw: dict) -> list[CcHudEvent]:
        event = raw.get("event", "")
        payload = raw.get("payload", {})
        sid = payload.get("session_id") or "default"
        out: list[CcHudEvent] = []

        if event in _EVENT_STATE:
            state = _EVENT_STATE[event]
            detail = payload.get("tool_name", "") if state == "tool" else ""
            out.append(CcHudEvent(self.client_id, sid, "state",
                                  state=state, detail=detail))
        elif event == "Notification":
            msg = payload.get("message", "") or ""
            state = "waiting" if any(h in msg for h in _PERMISSION_HINTS) else "idle"
            out.append(CcHudEvent(self.client_id, sid, "state", state=state))

        if event == "Status":
            # statusLine 透传:payload 本身就是 statusline JSON
            out.append(self._quota_from_statusline(sid, payload))
        return out

    def _quota_from_statusline(self, sid: str, sl: dict) -> CcHudEvent:
        rl = sl.get("rate_limits", {})
        fh = rl.get("five_hour", {})
        sd = rl.get("seven_day", {})
        cw = sl.get("context_window", {})
        cost = sl.get("cost", {})
        model = (sl.get("model", {}) or {}).get("display_name", "") or ""
        ctx_size = int(cw.get("context_window_size", 0) or 0)
        ctx_txt = _fmt_ctx_size(ctx_size)
        if model and ctx_txt:
            title = f"{model} ({ctx_txt} context)"
        elif model:
            title = model
        else:
            title = None
        return CcHudEvent(
            self.client_id, sid, "quota",
            five_h_used=int(fh.get("used_percentage", 0) or 0),
            five_h_resets_at=int(fh.get("resets_at", 0) or 0),
            seven_d_used=int(sd.get("used_percentage", 0) or 0),
            seven_d_resets_at=int(sd.get("resets_at", 0) or 0),
            ctx_pct=int(cw.get("used_percentage", 0) or 0),
            cost_usd=float(cost.get("total_cost_usd", 0) or 0),
            duration_s=int((cost.get("total_duration_ms", 0) or 0)) // 1000,
            lines_added=int(cost.get("total_lines_added", 0) or 0),
            lines_removed=int(cost.get("total_lines_removed", 0) or 0),
            title=title, mode="sub")

    def hook_spec(self) -> HookSpec:
        return HookSpec(events={
            "UserPromptSubmit": "claude UserPromptSubmit",
            "PreToolUse": "claude PreToolUse",
            "PostToolUse": "claude PostToolUse",
            "Stop": "claude Stop",
            "Notification": "claude Notification",
        }, statusline_wrapper="cchud-statusline.sh")
```

- [ ] **Step 4: 运行测试确认通过**

Run: `cd host && .venv/bin/python -m pytest tests/test_claude_adapter.py -v`
Expected: PASS（4 passed）

- [ ] **Step 5: 提交**

```bash
git add host/cchud_daemon/adapters host/tests/test_claude_adapter.py
git commit -m "feat: 新增 Adapter 接口与 ClaudeAdapter(复刻状态/额度/降级逻辑)"
```

---

## Task 6: AdapterRegistry + SocketServer

**Files:**
- Create: `host/cchud_daemon/registry.py`
- Create: `host/cchud_daemon/socket_server.py`
- Test: `host/tests/test_registry.py`
- Test: `host/tests/test_socket_server.py`

**Interfaces:**
- Consumes: `Adapter`/`ClaudeAdapter`(Task 5)、`CcHudEvent`。
- Produces:
  - `AdapterRegistry()`:`register(a: Adapter)`、`normalize(raw: dict) -> list[CcHudEvent]`(按 `raw["client"]` 选 adapter;未知 client 返回 `[]`)。
  - `SocketServer(path: str, on_events: Callable[[list[CcHudEvent]], Awaitable[None]], registry: AdapterRegistry)`:`async start()` 监听 UDS,每条连接读一行 JSON → `registry.normalize` → `await on_events`;解析失败忽略该行。`async stop()`。

- [ ] **Step 1: 写失败测试(registry)**

`host/tests/test_registry.py`:

```python
from cchud_daemon.registry import AdapterRegistry
from cchud_daemon.adapters.claude import ClaudeAdapter

def test_routes_to_claude():
    r = AdapterRegistry()
    r.register(ClaudeAdapter())
    evs = r.normalize({"client": "claude", "event": "Stop",
                       "payload": {"session_id": "s1"}})
    assert evs and evs[0].state == "idle"

def test_unknown_client_returns_empty():
    assert AdapterRegistry().normalize({"client": "nope", "event": "x"}) == []
```

- [ ] **Step 2: 写失败测试(socket server)**

`host/tests/test_socket_server.py`:

```python
import asyncio
import json
import pytest
from cchud_daemon.registry import AdapterRegistry
from cchud_daemon.adapters.claude import ClaudeAdapter
from cchud_daemon.socket_server import SocketServer

@pytest.mark.asyncio
async def test_socket_roundtrip(tmp_path):
    received = []

    async def on_events(evs):
        received.extend(evs)

    reg = AdapterRegistry(); reg.register(ClaudeAdapter())
    sock = str(tmp_path / "d.sock")
    srv = SocketServer(sock, on_events, reg)
    await srv.start()
    try:
        r, w = await asyncio.open_unix_connection(sock)
        w.write((json.dumps({"client": "claude", "event": "PreToolUse",
                             "payload": {"session_id": "s1", "tool_name": "Bash"}}) + "\n").encode())
        await w.drain(); w.close()
        await asyncio.sleep(0.1)
    finally:
        await srv.stop()
    assert any(e.detail == "Bash" for e in received)
```

- [ ] **Step 3: 运行测试确认失败**

Run: `cd host && .venv/bin/python -m pytest tests/test_registry.py tests/test_socket_server.py -v`
Expected: FAIL（ModuleNotFoundError）

- [ ] **Step 4: 写最小实现**

`host/cchud_daemon/registry.py`:

```python
from __future__ import annotations
from .adapters.base import Adapter
from .event import CcHudEvent

class AdapterRegistry:
    def __init__(self) -> None:
        self._by_name: dict[str, Adapter] = {}

    def register(self, a: Adapter) -> None:
        self._by_name[a.name] = a

    def normalize(self, raw: dict) -> list[CcHudEvent]:
        a = self._by_name.get(raw.get("client", ""))
        return a.normalize(raw) if a else []
```

`host/cchud_daemon/socket_server.py`:

```python
from __future__ import annotations
import asyncio
import json
import os
from typing import Awaitable, Callable
from .event import CcHudEvent
from .registry import AdapterRegistry

OnEvents = Callable[[list[CcHudEvent]], Awaitable[None]]

class SocketServer:
    """监听 Unix domain socket,把 hook 投递的 JSON 规范化为事件。"""

    def __init__(self, path: str, on_events: OnEvents, registry: AdapterRegistry) -> None:
        self._path = path
        self._on_events = on_events
        self._registry = registry
        self._server: asyncio.AbstractServer | None = None

    async def _handle(self, reader: asyncio.StreamReader,
                      writer: asyncio.StreamWriter) -> None:
        try:
            line = await reader.readline()
            if not line:
                return
            raw = json.loads(line.decode("utf-8"))
            evs = self._registry.normalize(raw)
            if evs:
                await self._on_events(evs)
        except (json.JSONDecodeError, UnicodeDecodeError):
            pass                                  # 脏行忽略,不崩溃
        finally:
            writer.close()

    async def start(self) -> None:
        if os.path.exists(self._path):
            os.unlink(self._path)
        os.makedirs(os.path.dirname(self._path), exist_ok=True)
        self._server = await asyncio.start_unix_server(self._handle, path=self._path)

    async def stop(self) -> None:
        if self._server:
            self._server.close()
            await self._server.wait_closed()
        if os.path.exists(self._path):
            os.unlink(self._path)
```

- [ ] **Step 5: 运行测试确认通过**

Run: `cd host && .venv/bin/python -m pytest tests/test_registry.py tests/test_socket_server.py -v`
Expected: PASS（3 passed）

- [ ] **Step 6: 提交**

```bash
git add host/cchud_daemon/registry.py host/cchud_daemon/socket_server.py host/tests/test_registry.py host/tests/test_socket_server.py
git commit -m "feat: 新增 AdapterRegistry 与 SocketServer"
```

---

## Task 7: BleLink(常驻连接 + 串行发送队列)

**Files:**
- Create: `host/cchud_daemon/ble_link.py`
- Test: `host/tests/test_ble_link.py`

**Interfaces:**
- Consumes: 无(BLE 客户端经构造注入,便于测试)。
- Produces:
  - `BleLink(address: str, *, client_factory=..., use_v7: bool = False)`:
    - `async enqueue(payload: bytes) -> None`:把已编码 payload 入串行队列。
    - `async run() -> None`:常驻——连接(失败指数退避重连 0.5→30s),从队列取项,`write_gatt_char(QUOTA_CHAR, payload, response=True)`,失败重试 1 次。
    - `async stop() -> None`。
  - 关键:**写入串行**——同一时刻只有一个 write 在飞(取代 `ble.lock`)。

- [ ] **Step 1: 写失败测试(用假 client 验证串行与重连)**

`host/tests/test_ble_link.py`:

```python
import asyncio
import pytest
from cchud_daemon.ble_link import BleLink

QUOTA_CHAR = "12345678-aaaa-bbbb-cccc-1234567890a1"

class FakeClient:
    """记录写入顺序、断言无并发写。"""
    instances = []

    def __init__(self, address, timeout=10):
        self.address = address
        self.writes = []
        self._in_write = False
        FakeClient.instances.append(self)

    async def __aenter__(self):
        return self

    async def __aexit__(self, *a):
        return False

    async def write_gatt_char(self, uuid, payload, response=True):
        assert not self._in_write, "并发写!应串行"
        self._in_write = True
        await asyncio.sleep(0.01)
        self.writes.append(bytes(payload))
        self._in_write = False

@pytest.mark.asyncio
async def test_serial_writes():
    FakeClient.instances.clear()
    link = BleLink("addr", client_factory=lambda addr, timeout: FakeClient(addr))
    task = asyncio.create_task(link.run())
    await link.enqueue(b"\x0b\x00\x00\x01")
    await link.enqueue(b"\x0b\x00\x00\x01\x01\x01\x28")
    await asyncio.sleep(0.1)
    await link.stop()
    task.cancel()
    writes = [w for c in FakeClient.instances for w in c.writes]
    assert len(writes) == 2
```

- [ ] **Step 2: 运行测试确认失败**

Run: `cd host && .venv/bin/python -m pytest tests/test_ble_link.py -v`
Expected: FAIL（ModuleNotFoundError）

- [ ] **Step 3: 写最小实现**

`host/cchud_daemon/ble_link.py`:

```python
from __future__ import annotations
import asyncio
import logging

QUOTA_CHAR = "12345678-aaaa-bbbb-cccc-1234567890a1"
_log = logging.getLogger("cchud.ble")

def _default_factory(address: str, timeout: float):
    from bleak import BleakClient
    return BleakClient(address, timeout=timeout)

class BleLink:
    """常驻 BLE 连接 + 串行发送队列(取代 ble.lock + 每次重连)。"""

    def __init__(self, address: str, *, client_factory=_default_factory,
                 use_v7: bool = False, timeout: float = 8.0) -> None:
        self._address = address
        self._factory = client_factory
        self._timeout = timeout
        self.use_v7 = use_v7
        self._queue: asyncio.Queue[bytes] = asyncio.Queue()
        self._stop = asyncio.Event()

    async def enqueue(self, payload: bytes) -> None:
        await self._queue.put(payload)

    async def _write_one(self, payload: bytes) -> None:
        last = None
        for _ in range(2):                       # 重试 1 次
            try:
                async with self._factory(self._address, self._timeout) as c:
                    await c.write_gatt_char(QUOTA_CHAR, payload, response=True)
                return
            except Exception as exc:             # noqa: BLE001
                last = exc
                await asyncio.sleep(0.4)
        _log.warning("BLE 写入失败: %s", last)

    async def run(self) -> None:
        backoff = 0.5
        while not self._stop.is_set():
            try:
                payload = await asyncio.wait_for(self._queue.get(), timeout=1.0)
            except asyncio.TimeoutError:
                continue
            await self._write_one(payload)        # 串行:一次一个
            backoff = 0.5

    async def stop(self) -> None:
        self._stop.set()
```

> 说明:本实现每次写入用一个短连接上下文(`async with`),队列保证串行。后续可在此模块内升级为"保持长连接"——接口不变,测试不变。常驻长连接的真机验证见 Task 11。

- [ ] **Step 4: 运行测试确认通过**

Run: `cd host && .venv/bin/python -m pytest tests/test_ble_link.py -v`
Expected: PASS（1 passed）

- [ ] **Step 5: 提交**

```bash
git add host/cchud_daemon/ble_link.py host/tests/test_ble_link.py
git commit -m "feat: 新增 BleLink 串行发送队列与重连骨架"
```

---

## Task 8: daemon 组装 + 状态管线 + launchd

**Files:**
- Create: `host/cchud_daemon/daemon.py`
- Create: `host/io.cchud.daemon.plist`
- Test: `host/tests/test_daemon_pipeline.py`

**Interfaces:**
- Consumes: 全部前序模块。
- Produces:
  - `Daemon(address, sock_path, *, ble=None, now=time.time)`:
    - `async on_events(evs: list[CcHudEvent]) -> None`:state 事件 → `SessionStore.update`,聚合变更则 enqueue `encode_state_0x07`;quota 事件 → `QuotaTracker.merge`,`should_push` 为真则 enqueue 编码(use_v7 决定 v6/v7),并 `mark_pushed`。
    - `async start()/stop()`。
  - state code 映射:`{"idle":0,"thinking":1,"tool":2,"waiting":3,"done":4}`。

- [ ] **Step 1: 写失败测试(端到端管线,注入假 BleLink)**

`host/tests/test_daemon_pipeline.py`:

```python
import pytest
from cchud_daemon.daemon import Daemon
from cchud_daemon.event import CcHudEvent

class SpyBle:
    def __init__(self): self.sent = []; self.use_v7 = False
    async def enqueue(self, payload): self.sent.append(bytes(payload))
    async def run(self): pass
    async def stop(self): pass

@pytest.mark.asyncio
async def test_state_event_pushes_0x07():
    ble = SpyBle()
    t = {"v": 1000.0}
    d = Daemon("addr", "/tmp/x.sock", ble=ble, now=lambda: t["v"])
    await d.on_events([CcHudEvent(0, "s1", "state", state="tool", detail="Bash")])
    assert ble.sent and ble.sent[0][0] == 0x07 and ble.sent[0][1] == 2

@pytest.mark.asyncio
async def test_quota_rate_limited():
    ble = SpyBle()
    t = {"v": 1000.0}
    d = Daemon("addr", "/tmp/x.sock", ble=ble, now=lambda: t["v"])
    q = CcHudEvent(0, "s1", "quota", five_h_used=40, five_h_resets_at=2000,
                   seven_d_used=28, seven_d_resets_at=9000, ctx_pct=65,
                   cost_usd=0.42, duration_s=23, lines_added=1, lines_removed=0,
                   title="Opus 4.8", mode="sub")
    await d.on_events([q])
    assert len(ble.sent) == 1                       # 首次推送
    t["v"] = 1010.0
    await d.on_events([q])
    assert len(ble.sent) == 1                       # 30s 内被限频
    t["v"] = 1040.0
    await d.on_events([q])
    assert len(ble.sent) == 2                       # 超 30s 再推
```

- [ ] **Step 2: 运行测试确认失败**

Run: `cd host && .venv/bin/python -m pytest tests/test_daemon_pipeline.py -v`
Expected: FAIL（ModuleNotFoundError）

- [ ] **Step 3: 写最小实现**

`host/cchud_daemon/daemon.py`:

```python
from __future__ import annotations
import asyncio
import time
from .aggregator import Aggregator
from .ble_link import BleLink
from .codec import (encode_state_0x07, encode_quota_v6, encode_v7,
                    tlv_u8, tlv_u32, tlv_str, TAG_FIVE_H_USED_PCT,
                    TAG_FIVE_H_RESET_IN_S, TAG_SEVEN_D_USED_PCT,
                    TAG_SEVEN_D_RESET_IN_S, TAG_CONTEXT_USED_PCT,
                    TAG_COST_MICRO_USD, TAG_DURATION_S, TAG_LINES_ADDED,
                    TAG_LINES_REMOVED, TAG_PLAN_MODE, TAG_TITLE)
from .event import CcHudEvent
from .quota_tracker import QuotaTracker
from .registry import AdapterRegistry
from .adapters.claude import ClaudeAdapter
from .session_store import SessionStore
from .socket_server import SocketServer

_STATE_CODE = {"idle": 0, "thinking": 1, "tool": 2, "waiting": 3, "done": 4}

class Daemon:
    def __init__(self, address: str, sock_path: str, *, ble=None,
                 now=time.time) -> None:
        self._now = now
        self._store = SessionStore()
        self._quota = QuotaTracker()
        self._agg = Aggregator()
        self._ble = ble if ble is not None else BleLink(address)
        self._registry = AdapterRegistry()
        self._registry.register(ClaudeAdapter())
        self._sock = SocketServer(sock_path, self.on_events, self._registry)
        self._last_title = "CC HUD"

    async def on_events(self, evs: list[CcHudEvent]) -> None:
        for e in evs:
            if e.kind == "state":
                await self._handle_state(e)
            elif e.kind == "quota":
                await self._handle_quota(e)

    async def _handle_state(self, e: CcHudEvent) -> None:
        now = self._now()
        self._store.update(e.session_id, e.state or "idle", e.detail or "", now)
        state, detail, total, busy = self._agg.aggregate(self._store, now)
        if self._agg.changed((state, detail, total, busy)):
            await self._ble.enqueue(
                encode_state_0x07(_STATE_CODE.get(state, 0), detail, total, busy))

    async def _handle_quota(self, e: CcHudEvent) -> None:
        now = self._now()
        used5, reset5_at = self._quota.merge(
            e.five_h_used or 0, e.five_h_resets_at or 0, "5h", now)
        used7, reset7_at = self._quota.merge(
            e.seven_d_used or 0, e.seven_d_resets_at or 0, "7d", now)
        if not self._quota.should_push(now):
            return
        self._quota.mark_pushed(now)
        if e.title:
            self._last_title = e.title
        reset5 = max(0, reset5_at - int(now)) if reset5_at else 0
        reset7 = max(0, reset7_at - int(now)) if reset7_at else 0
        cost_micro = max(0, int(round((e.cost_usd or 0) * 1_000_000)))
        if getattr(self._ble, "use_v7", False):
            payload = encode_v7([
                tlv_u8(TAG_PLAN_MODE, 0 if (e.mode or "sub") == "sub" else 1),
                tlv_u8(TAG_FIVE_H_USED_PCT, used5),
                tlv_u32(TAG_FIVE_H_RESET_IN_S, reset5),
                tlv_u8(TAG_SEVEN_D_USED_PCT, used7),
                tlv_u32(TAG_SEVEN_D_RESET_IN_S, reset7),
                tlv_u8(TAG_CONTEXT_USED_PCT, e.ctx_pct or 0),
                tlv_u32(TAG_COST_MICRO_USD, cost_micro),
                tlv_u32(TAG_DURATION_S, e.duration_s or 0),
                tlv_u32(TAG_LINES_ADDED, e.lines_added or 0),
                tlv_u32(TAG_LINES_REMOVED, e.lines_removed or 0),
                tlv_str(TAG_TITLE, self._last_title),
            ])
        else:
            payload = encode_quota_v6(
                mode=0 if (e.mode or "sub") == "sub" else 1,
                h5_used=used5, h5_limit=100, d7_used=used7, d7_limit=100,
                h5_reset_s=reset5, d7_reset_s=reset7,
                cost_micro_usd=cost_micro, duration_s=e.duration_s or 0,
                ctx_pct=e.ctx_pct or 0, lines_added=e.lines_added or 0,
                lines_removed=e.lines_removed or 0, title=self._last_title)
        await self._ble.enqueue(payload)

    async def start(self) -> None:
        await self._sock.start()
        asyncio.create_task(self._ble.run())

    async def stop(self) -> None:
        await self._sock.stop()
        await self._ble.stop()
```

- [ ] **Step 4: 写 launchd 模板**

`host/io.cchud.daemon.plist`(占位 `__PYTHON__`/`__DAEMON__` 由 `cchud install` 替换):

```xml
<?xml version="1.0" encoding="UTF-8"?>
<!DOCTYPE plist PUBLIC "-//Apple//DTD PLIST 1.0//EN"
  "http://www.apple.com/DTDs/PropertyList-1.0.dtd">
<plist version="1.0">
<dict>
  <key>Label</key><string>io.cchud.daemon</string>
  <key>ProgramArguments</key>
  <array><string>__PYTHON__</string><string>-m</string><string>cchud_daemon.cli</string><string>daemon</string></array>
  <key>RunAtLoad</key><true/>
  <key>KeepAlive</key><true/>
  <key>StandardErrorPath</key><string>__HOME__/.cchud/daemon.log</string>
  <key>StandardOutPath</key><string>__HOME__/.cchud/daemon.log</string>
  <key>WorkingDirectory</key><string>__DAEMON__</string>
</dict>
</plist>
```

- [ ] **Step 5: 运行测试确认通过**

Run: `cd host && .venv/bin/python -m pytest tests/test_daemon_pipeline.py -v`
Expected: PASS（2 passed）

- [ ] **Step 6: 提交**

```bash
git add host/cchud_daemon/daemon.py host/io.cchud.daemon.plist host/tests/test_daemon_pipeline.py
git commit -m "feat: 组装 Daemon 状态管线 + launchd 模板"
```

---

## Task 9: CLI(daemon/install/status)+ 瘦 hook 脚本

**Files:**
- Create: `host/cchud_daemon/cli.py`
- Create: `host/cchud-emit.sh`
- Modify: `host/cchud-statusline.sh`(后台采集从 quota-push 改为投递 daemon;保留 ccstatusline 渲染)
- Test: `host/tests/test_cli_install.py`

**Interfaces:**
- Consumes: `Daemon`(Task 8)、`ClaudeAdapter.hook_spec()`(Task 5)。
- Produces:
  - `cli.main(argv: list[str]) -> int`,子命令:
    - `daemon`:读 `CCHUD_ADDR`,建 `Daemon`,`asyncio.run` 常驻。
    - `install <client>`:把 adapter 的 `hook_spec` 写进 `~/.claude/settings.json`(5 个 hook 指向 `cchud-emit.sh`,statusLine 指向 `cchud-statusline.sh` 包装脚本);**先备份**原文件为 `settings.json.cchud-bak`;幂等(重复执行不产生重复项)。
    - `status`:打印 socket 是否存在、daemon.log 末尾若干行。
  - `merge_claude_settings(settings: dict, emit_path: str) -> dict`:纯函数,便于测试幂等与正确性;statusLine 命令由 `emit_path` 同目录的 `statusline_wrapper` 推算。

- [ ] **Step 1: 写失败测试(install 合并幂等)**

`host/tests/test_cli_install.py`:

```python
from cchud_daemon.cli import merge_claude_settings

def test_install_adds_hooks_and_statusline():
    s = merge_claude_settings({}, "/x/cchud-emit.sh")
    assert "Stop" in s["hooks"]
    cmd = s["hooks"]["Stop"][0]["hooks"][0]["command"]
    assert cmd.endswith("cchud-emit.sh claude Stop")
    # statusLine 指向渲染包装脚本(同目录),而非裸 emit
    assert s["statusLine"]["command"].endswith("cchud-statusline.sh")

def test_install_is_idempotent():
    s1 = merge_claude_settings({}, "/x/cchud-emit.sh")
    s2 = merge_claude_settings(s1, "/x/cchud-emit.sh")
    assert s1 == s2                              # 重复执行不增项
```

- [ ] **Step 2: 运行测试确认失败**

Run: `cd host && .venv/bin/python -m pytest tests/test_cli_install.py -v`
Expected: FAIL（ModuleNotFoundError）

- [ ] **Step 3: 写最小实现**

`host/cchud_daemon/cli.py`:

```python
from __future__ import annotations
import asyncio
import json
import os
import sys
from .daemon import Daemon
from .adapters.claude import ClaudeAdapter

HOME = os.path.expanduser("~")
SOCK = os.path.join(HOME, ".cchud", "daemon.sock")
LOG = os.path.join(HOME, ".cchud", "daemon.log")

def merge_claude_settings(settings: dict, emit_path: str) -> dict:
    s = dict(settings)
    hooks = dict(s.get("hooks", {}))
    spec = ClaudeAdapter().hook_spec()
    for event, args in spec.events.items():
        command = f"{emit_path} {args}"
        entry = {"hooks": [{"type": "command", "command": command}]}
        # 幂等:若已存在指向同一 emit 的项则覆盖该项,否则设为唯一项
        hooks[event] = [entry]
    s["hooks"] = hooks
    if spec.statusline_wrapper:
        wrapper = os.path.join(os.path.dirname(emit_path), spec.statusline_wrapper)
        s["statusLine"] = {"type": "command", "command": wrapper, "padding": 0}
    return s

def _install(client: str) -> int:
    if client != "claude":
        print(f"未知客户端: {client}", file=sys.stderr)
        return 2
    emit = os.path.join(os.path.dirname(os.path.dirname(os.path.abspath(__file__))),
                        "cchud-emit.sh")
    cfg = os.path.join(HOME, ".claude", "settings.json")
    cur = {}
    if os.path.exists(cfg):
        with open(cfg) as f:
            cur = json.load(f)
        with open(cfg + ".cchud-bak", "w") as f:
            json.dump(cur, f, indent=2)
    merged = merge_claude_settings(cur, emit)
    os.makedirs(os.path.dirname(cfg), exist_ok=True)
    with open(cfg, "w") as f:
        json.dump(merged, f, indent=2)
    print(f"已写入 {cfg}(备份 {cfg}.cchud-bak)")
    return 0

def _status() -> int:
    print(f"socket: {'存在' if os.path.exists(SOCK) else '缺失'} ({SOCK})")
    if os.path.exists(LOG):
        with open(LOG) as f:
            tail = f.readlines()[-10:]
        print("".join(tail))
    return 0

def _daemon() -> int:
    addr = os.environ.get("CCHUD_ADDR", "")
    d = Daemon(addr, SOCK)

    async def _run():
        await d.start()
        while True:
            await asyncio.sleep(3600)

    asyncio.run(_run())
    return 0

def main(argv: list[str]) -> int:
    if not argv:
        print("usage: cchud {daemon|install <client>|status}", file=sys.stderr)
        return 2
    cmd = argv[0]
    if cmd == "daemon":
        return _daemon()
    if cmd == "install":
        return _install(argv[1] if len(argv) > 1 else "")
    if cmd == "status":
        return _status()
    print(f"未知命令: {cmd}", file=sys.stderr)
    return 2

if __name__ == "__main__":
    sys.exit(main(sys.argv[1:]))
```

`host/cchud-emit.sh`(瘦 hook;socket 不可用静默退出):

```bash
#!/usr/bin/env bash
# cchud-emit.sh — 瘦 hook 客户端:读 stdin,包成 JSON,投递给 daemon socket。
# 用法: cchud-emit.sh <client> <event>
# 失败一律静默退出 0,绝不阻塞调用方。
set -u
CLIENT="${1:-}"; EVENT="${2:-}"
SOCK="$HOME/.cchud/daemon.sock"
[ -S "$SOCK" ] || exit 0
STDIN="$(cat 2>/dev/null || true)"
# payload 直接透传 hook 的原始 stdin(JSON);daemon 侧 adapter 解析。
PAYLOAD="${STDIN:-\{\}}"
MSG="$(printf '{"client":"%s","event":"%s","payload":%s}' "$CLIENT" "$EVENT" "$PAYLOAD")"
# 用 nc 投递一行;无 nc 时尝试 /dev/tcp 不可用于 unix socket,退回 python 兜底。
if command -v nc >/dev/null 2>&1; then
    printf '%s\n' "$MSG" | nc -U "$SOCK" -w 1 >/dev/null 2>&1 || true
else
    printf '%s\n' "$MSG" | "$(dirname "$0")/.venv/bin/python" -c \
      'import socket,sys,os;s=socket.socket(socket.AF_UNIX);s.connect(os.path.expanduser("~/.cchud/daemon.sock"));s.sendall(sys.stdin.buffer.read());s.close()' \
      >/dev/null 2>&1 || true
fi
exit 0
```

`host/cchud-statusline.sh`(**Modify** 现有文件:把后台采集从 `cchud-quota-push.sh` 改为投递 daemon,渲染保持不变):

```bash
#!/usr/bin/env bash
# cchud-statusline.sh — Claude Code statusLine 包装:渲染状态栏 + 把 JSON 投递给 daemon。
#
# 双职责:(1) 沿用 ccstatusline 渲染终端状态栏;(2) 后台把 statusline JSON
# 透传给 cchud-emit.sh(投递 daemon 采集额度)。绝不阻塞、绝不弄坏状态栏。
set -u
HERE="$(cd "$(dirname "$0")" && pwd)"

# Claude 通过 stdin 把会话/额度 JSON 传进来,只读一次。
INPUT="$(cat)"

# 后台投递给 daemon(fire-and-forget,吞掉所有输出)。
printf '%s' "$INPUT" | "$HERE/cchud-emit.sh" claude Status >/dev/null 2>&1 &
disown 2>/dev/null || true

# 渲染真正的状态栏(沿用原命令)。
printf '%s' "$INPUT" | bunx -y ccstatusline@latest
```

设权限:`chmod +x host/cchud-emit.sh host/cchud-statusline.sh`

- [ ] **Step 4: 运行测试确认通过**

Run: `cd host && .venv/bin/python -m pytest tests/test_cli_install.py -v`
Expected: PASS（2 passed）

- [ ] **Step 5: 全量回归 + 提交**

Run: `cd host && .venv/bin/python -m pytest -v`
Expected: PASS（全部测试)

```bash
chmod +x host/cchud-emit.sh host/cchud-statusline.sh
git add host/cchud_daemon/cli.py host/cchud-emit.sh host/cchud-statusline.sh host/tests/test_cli_install.py
git commit -m "feat: 新增 cchud CLI(daemon/install/status)与瘦 hook 脚本"
```

---

## Task 10: 固件 v7 TLV 解析(native 单测)+ 接线 + MTU

**Files:**
- Create: `firmware/src/v7_tlv.h`
- Create: `firmware/src/v7_tlv.cpp`
- Create: `firmware/test/test_v7_tlv/test_v7_tlv.cpp`
- Modify: `firmware/platformio.ini`(加 `[env:native]`)
- Modify: `firmware/src/config.h`(加 `kQuotaMsgTypeV7Tlv` 与 tag 常量)
- Modify: `firmware/src/ble_server.cpp`(加 0x0B 分支 + setMTU)

**Interfaces:**
- Consumes: 无(纯函数)。
- Produces:
  - `struct V7Fields { ... }`:解析结果(额度/成本/状态/会话数等可选字段 + `has_*` 标志)。
  - `enum V7Result { V7_OK, V7_ERR_LEN, V7_ERR_FRAGMENT }`。
  - `V7Result parseV7Tlv(const uint8_t* buf, size_t len, V7Fields& out)`:校验头(`buf[0]==0x0B`,`total==1` 否则 `V7_ERR_FRAGMENT`),循环读 `[tag][len][value]`,越界返回 `V7_ERR_LEN`,未知 tag 跳过。

- [ ] **Step 1: 加 native 测试环境**

`firmware/platformio.ini` 追加:

```ini
[env:native]
platform = native
test_framework = unity
build_flags = -std=c++17 -I src
```

- [ ] **Step 2: 写失败测试**

`firmware/test/test_v7_tlv/test_v7_tlv.cpp`:

```cpp
#include <unity.h>
#include <cstdint>
#include <cstddef>
#include "v7_tlv.h"

using namespace cc_hud;

void test_parse_known_tags() {
    // 头 + TAG_FIVE_H_USED_PCT(0x01)=40 + TAG_TITLE(0x0B)="Hi"
    const uint8_t buf[] = {0x0B,0,0,1, 0x01,1,40, 0x0B,2,'H','i'};
    V7Fields f{};
    TEST_ASSERT_EQUAL(V7_OK, parseV7Tlv(buf, sizeof(buf), f));
    TEST_ASSERT_TRUE(f.has_five_h_used);
    TEST_ASSERT_EQUAL_UINT8(40, f.five_h_used);
    TEST_ASSERT_EQUAL_STRING("Hi", f.title);
}

void test_unknown_tag_skipped() {
    // 未知 tag 0xC0 len=2,后跟已知 AGG_STATE(0x20)=2
    const uint8_t buf[] = {0x0B,0,0,1, 0xC0,2,0xAA,0xBB, 0x20,1,2};
    V7Fields f{};
    TEST_ASSERT_EQUAL(V7_OK, parseV7Tlv(buf, sizeof(buf), f));
    TEST_ASSERT_TRUE(f.has_agg_state);
    TEST_ASSERT_EQUAL_UINT8(2, f.agg_state);
}

void test_len_overflow_errors() {
    const uint8_t buf[] = {0x0B,0,0,1, 0x01,9,40};   // len=9 越界
    V7Fields f{};
    TEST_ASSERT_EQUAL(V7_ERR_LEN, parseV7Tlv(buf, sizeof(buf), f));
}

void test_fragment_rejected() {
    const uint8_t buf[] = {0x0B,0,0,2, 0x01,1,40};   // total=2
    V7Fields f{};
    TEST_ASSERT_EQUAL(V7_ERR_FRAGMENT, parseV7Tlv(buf, sizeof(buf), f));
}

int main(int, char**) {
    UNITY_BEGIN();
    RUN_TEST(test_parse_known_tags);
    RUN_TEST(test_unknown_tag_skipped);
    RUN_TEST(test_len_overflow_errors);
    RUN_TEST(test_fragment_rejected);
    return UNITY_END();
}
```

- [ ] **Step 3: 运行测试确认失败**

Run: `cd firmware && pio test -e native`
Expected: FAIL（v7_tlv.h not found / 链接失败）

- [ ] **Step 4: 写最小实现**

`firmware/src/v7_tlv.h`:

```cpp
#pragma once
#include <cstdint>
#include <cstddef>

namespace cc_hud {

// v7 tag(对照路线图 7.4,本层用到的子集)
enum V7Tag : uint8_t {
    kV7TagFiveHUsedPct    = 0x01,
    kV7TagFiveHResetInS   = 0x02,
    kV7TagSevenDUsedPct   = 0x03,
    kV7TagSevenDResetInS  = 0x04,
    kV7TagContextUsedPct  = 0x05,
    kV7TagCostMicroUsd    = 0x06,
    kV7TagDurationS       = 0x07,
    kV7TagLinesAdded      = 0x08,
    kV7TagLinesRemoved    = 0x09,
    kV7TagPlanMode        = 0x0A,
    kV7TagTitle           = 0x0B,
    kV7TagAggState        = 0x20,
    kV7TagActiveToolName  = 0x21,
    kV7TagTotalSessions   = 0x22,
    kV7TagBusySessions    = 0x23,
};

enum V7Result { V7_OK, V7_ERR_LEN, V7_ERR_FRAGMENT };

struct V7Fields {
    bool     has_five_h_used = false;  uint8_t five_h_used = 0;
    bool     has_five_h_reset = false; uint32_t five_h_reset_s = 0;
    bool     has_seven_d_used = false; uint8_t seven_d_used = 0;
    bool     has_seven_d_reset = false; uint32_t seven_d_reset_s = 0;
    bool     has_ctx = false;          uint8_t ctx_pct = 0;
    bool     has_cost = false;         uint32_t cost_micro_usd = 0;
    bool     has_duration = false;     uint32_t duration_s = 0;
    bool     has_lines_added = false;  uint32_t lines_added = 0;
    bool     has_lines_removed = false; uint32_t lines_removed = 0;
    bool     has_mode = false;         uint8_t mode = 0;
    bool     has_title = false;        char title[33] = {0};
    bool     has_agg_state = false;    uint8_t agg_state = 0;
    bool     has_tool = false;         char tool[16] = {0};
    bool     has_total = false;        uint8_t total_sessions = 0;
    bool     has_busy = false;         uint8_t busy_sessions = 0;
};

V7Result parseV7Tlv(const uint8_t* buf, size_t len, V7Fields& out);

}  // namespace cc_hud
```

`firmware/src/v7_tlv.cpp`:

```cpp
#include "v7_tlv.h"
#include <cstring>

namespace cc_hud {

static uint32_t rdU32(const uint8_t* p) {
    return uint32_t(p[0]) | (uint32_t(p[1]) << 8) |
           (uint32_t(p[2]) << 16) | (uint32_t(p[3]) << 24);
}

static void cpyStr(char* dst, size_t cap, const uint8_t* src, uint8_t len) {
    size_t n = len < cap - 1 ? len : cap - 1;
    std::memcpy(dst, src, n);
    dst[n] = '\0';
}

V7Result parseV7Tlv(const uint8_t* buf, size_t len, V7Fields& out) {
    if (len < 4) return V7_ERR_LEN;
    if (buf[3] != 1) return V7_ERR_FRAGMENT;     // 分片:本层不支持
    size_t i = 4;
    while (i + 2 <= len) {
        uint8_t tag = buf[i];
        uint8_t l   = buf[i + 1];
        if (i + 2 + l > len) return V7_ERR_LEN;
        const uint8_t* v = buf + i + 2;
        switch (tag) {
            case kV7TagFiveHUsedPct:   if (l>=1){out.has_five_h_used=true; out.five_h_used=v[0];} break;
            case kV7TagFiveHResetInS:  if (l>=4){out.has_five_h_reset=true; out.five_h_reset_s=rdU32(v);} break;
            case kV7TagSevenDUsedPct:  if (l>=1){out.has_seven_d_used=true; out.seven_d_used=v[0];} break;
            case kV7TagSevenDResetInS: if (l>=4){out.has_seven_d_reset=true; out.seven_d_reset_s=rdU32(v);} break;
            case kV7TagContextUsedPct: if (l>=1){out.has_ctx=true; out.ctx_pct=v[0];} break;
            case kV7TagCostMicroUsd:   if (l>=4){out.has_cost=true; out.cost_micro_usd=rdU32(v);} break;
            case kV7TagDurationS:      if (l>=4){out.has_duration=true; out.duration_s=rdU32(v);} break;
            case kV7TagLinesAdded:     if (l>=4){out.has_lines_added=true; out.lines_added=rdU32(v);} break;
            case kV7TagLinesRemoved:   if (l>=4){out.has_lines_removed=true; out.lines_removed=rdU32(v);} break;
            case kV7TagPlanMode:       if (l>=1){out.has_mode=true; out.mode=v[0];} break;
            case kV7TagTitle:          out.has_title=true; cpyStr(out.title, sizeof(out.title), v, l); break;
            case kV7TagAggState:       if (l>=1){out.has_agg_state=true; out.agg_state=v[0];} break;
            case kV7TagActiveToolName: out.has_tool=true; cpyStr(out.tool, sizeof(out.tool), v, l); break;
            case kV7TagTotalSessions:  if (l>=1){out.has_total=true; out.total_sessions=v[0];} break;
            case kV7TagBusySessions:   if (l>=1){out.has_busy=true; out.busy_sessions=v[0];} break;
            default: break;                       // 未知 tag 跳过
        }
        i += 2 + l;
    }
    return V7_OK;
}

}  // namespace cc_hud
```

- [ ] **Step 5: 运行测试确认通过**

Run: `cd firmware && pio test -e native`
Expected: PASS（4 tests passed）

- [ ] **Step 6: 接线进 ble_server + config + MTU**

`firmware/src/config.h` 增加(放在现有 msg_type 常量旁):

```cpp
constexpr uint8_t kQuotaMsgTypeV7Tlv = 0x0B;   // v7 统一 TLV 帧
```

`firmware/src/ble_server.cpp`:
- 顶部 `#include "v7_tlv.h"`。
- 在 `onWrite` 的回退分支(`if (!is_v1 && ...)`)**之前**插入 v7 分支:

```cpp
// v7 TLV 统一帧(msg_type 0x0B):解析后按已知字段分发。
if (len >= 4 && data[0] == kQuotaMsgTypeV7Tlv) {
    V7Fields f{};
    V7Result rc = parseV7Tlv(data, len, f);
    if (rc != V7_OK) {
        // 分片(V7_ERR_FRAGMENT)与越界(V7_ERR_LEN)目前都归入长度错误码;
        // 第 4 层引入分片重组后,可为 fragment 单列状态码。
        bleNotifyState(kStateErrLen);
        return;
    }
    // 额度/成本类 → QuotaSnapshot
    if (f.has_five_h_used || f.has_title || f.has_cost) {
        QuotaSnapshot q;
        q.mode          = f.has_mode ? f.mode : kSnapshotModeSubscription;
        q.used_5h       = f.five_h_used;  q.limit_5h = 100;
        q.used_7d       = f.seven_d_used; q.limit_7d = 100;
        q.reset_in_s_5h = f.five_h_reset_s;
        q.reset_in_s_7d = f.seven_d_reset_s;
        q.cost_micro_usd = f.cost_micro_usd;
        q.duration_s     = f.duration_s;
        q.ctx_pct        = f.ctx_pct;
        q.lines_added    = f.lines_added;
        q.lines_removed  = f.lines_removed;
        std::strncpy(q.title, f.has_title ? f.title : "CC HUD", sizeof(q.title) - 1);
        q.title[sizeof(q.title) - 1] = '\0';
        q.last_update_ms = static_cast<uint64_t>(millis());
        if (g_on_write) g_on_write(q);
    }
    // 状态类 → g_on_state
    if (f.has_agg_state) {
        if (g_on_state) g_on_state(static_cast<int8_t>(f.agg_state),
                                   f.tool, f.total_sessions, f.busy_sessions);
    }
    bleNotifyState(kStateOk);
    return;
}
```

- 在 `bleServerInit` 的 `NimBLEDevice::init(...)` 之后加:

```cpp
NimBLEDevice::setMTU(247);   // 提高单包阈值,配合 DLE/2M PHY
```

- [ ] **Step 7: 编译固件确认通过**

Run: `cd firmware && pio run -e esp32s3_nano`
Expected: SUCCESS(编译链接通过)

- [ ] **Step 8: 提交**

```bash
git add firmware/src/v7_tlv.h firmware/src/v7_tlv.cpp firmware/test/test_v7_tlv firmware/platformio.ini firmware/src/config.h firmware/src/ble_server.cpp
git commit -m "feat: 固件接入 v7 TLV 解析(native 单测)+ 0x0B 分支 + setMTU"
```

---

## Task 11: 端到端真机验证(阶段 1a→1b 切换)

**Files:** 无新增代码;执行验证清单(对应 spec 第九节)。

- [ ] **Step 1: 阶段 1a 真机验证(daemon 用 v6)**

操作:
1. `host/.venv/bin/python -m pip install -e 'host[dev]'`
2. `cchud install claude`(经 `python -m cchud_daemon.cli install claude`)
3. `CCHUD_ADDR=<UUID> python -m cchud_daemon.cli daemon &`
4. 在 Claude Code 跑一个含工具调用的任务。

验证(对照 A1–A10):
- A8 显示:额度/成本/上下文/行数/状态/会话数与重构前一致。
- A4 降级:触发权限请求 → 红环 waiting;普通 end-of-turn → 不变红。
- A5 限频:`~/.cchud/daemon.log` 中 quota 写入间隔 ≥30s。
- A7/A9:日志显示 BLE 写入串行、无每次重连报错。

- [ ] **Step 2: 阶段 1b 切 v7**

操作:
1. OTA 升级固件到含 v7 解析版本(WiFi OTA `cc-hud.local` 或 `pio run -t upload`)。
2. daemon 开启 v7:`CCHUD_USE_V7=1`(在 `cli._daemon` 读环境变量设 `Daemon` 的 BleLink `use_v7=True`)。

> 实现补充(本步顺带改 `cli.py` 的 `_daemon`):
> ```python
> use_v7 = os.environ.get("CCHUD_USE_V7", "") == "1"
> from .ble_link import BleLink
> ble = BleLink(addr, use_v7=use_v7)
> d = Daemon(addr, SOCK, ble=ble)
> ```

验证:
- 设备显示与 1a(v6)完全一致(额度/标题/状态),证明 v7 通路等价。
- 串口日志 `[BLE] write ... msg_type=0x0B` 出现且无 `kStateErrLen`。

- [ ] **Step 3: 旧脚本下线**

确认稳定后,从 `~/.claude/settings.json` 移除旧 `cchud-hook.sh`/`cchud-statusline.sh` 引用(`cchud install` 已覆盖为 emit),旧脚本保留一个版本周期后删除。

- [ ] **Step 4: 提交验证记录**

```bash
git commit --allow-empty -m "test: 第 1 层端到端真机验证通过(1a v6 / 1b v7 等价)"
```

---

## 自检(spec 覆盖核对)

- 验收 A1 聚合优先级 → Task 3 `test_aggregate_picks_highest_priority`。
- A2 TTL → Task 1 `test_expired_sessions_are_swept`。
- A3 额度分窗取最大 → Task 2 `test_merge_*`。
- A4 Notification 降级 → Task 5 `test_notification_*`。
- A5 限频 → Task 2 + Task 8 `test_quota_rate_limited`。
- A6 标题拼装 → Task 5 `test_statusline_produces_quota_event_with_title`。
- A7 串行 → Task 7 `test_serial_writes`。
- A8 显示等价 → Task 11 Step 1。
- A9 常驻连接 → Task 7 + Task 11。
- A10 install → Task 9 `test_install_*` + Task 11。
- v7 TLV(解析/未知 tag/越界/分片) → Task 10 四个 native 测试。
- v6/v7 编码字节布局 → Task 4。
- daemon 管线 → Task 8。
- socket → Task 6。

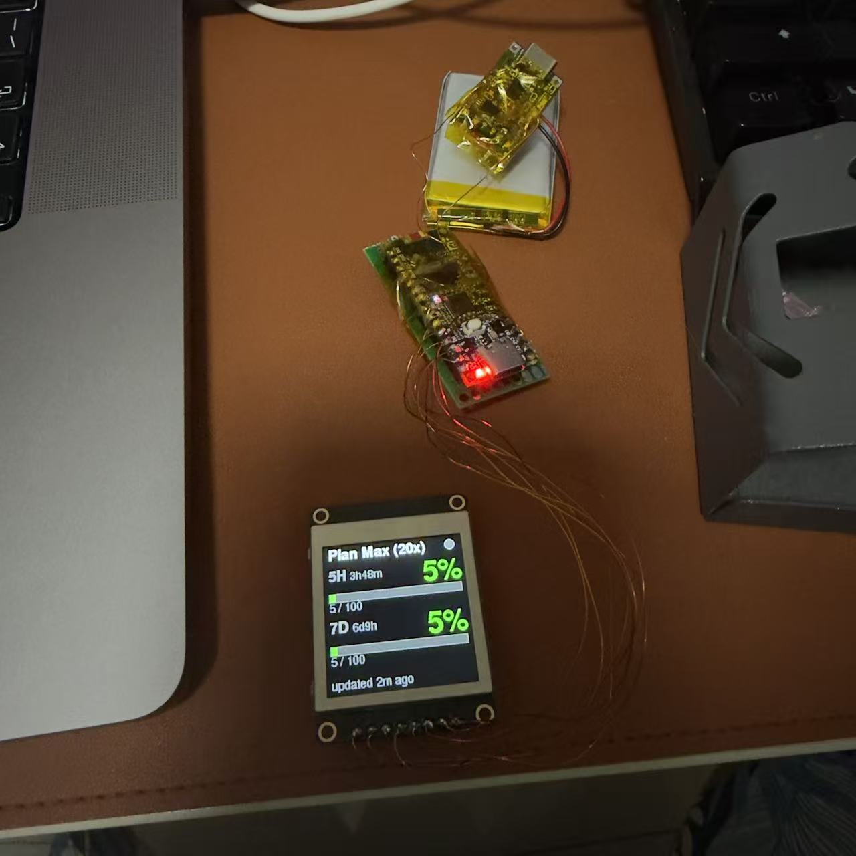
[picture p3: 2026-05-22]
images/screen-ota.jpg

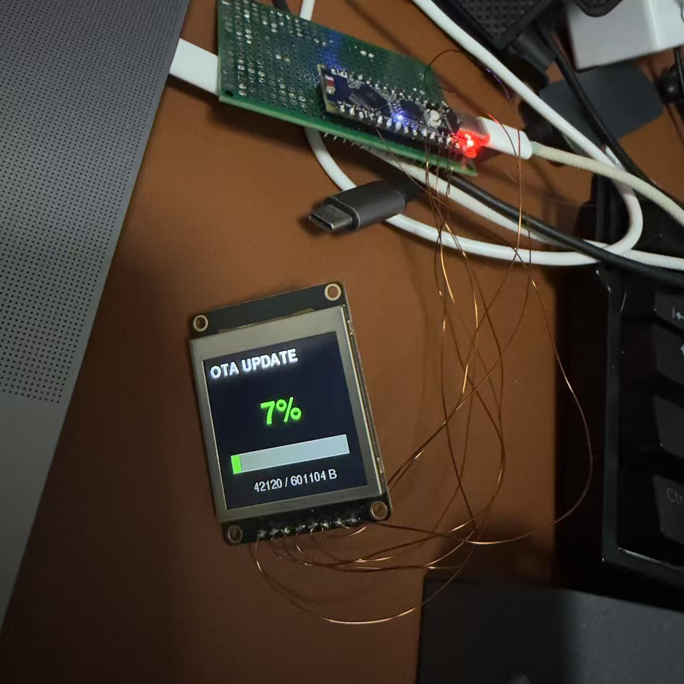
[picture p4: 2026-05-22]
images/screen.jpg

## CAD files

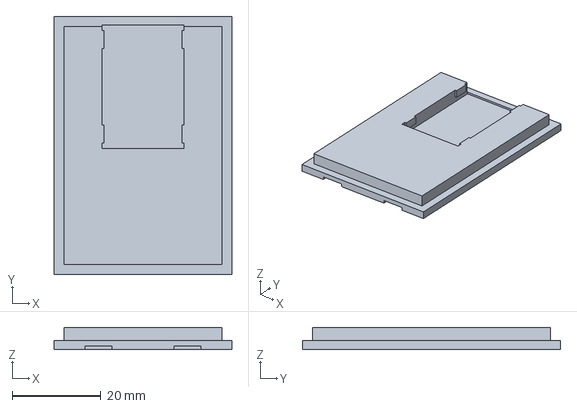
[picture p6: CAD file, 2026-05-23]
cc_hud_back_cover.step
40.0 x 58.0 x 5.00 mm

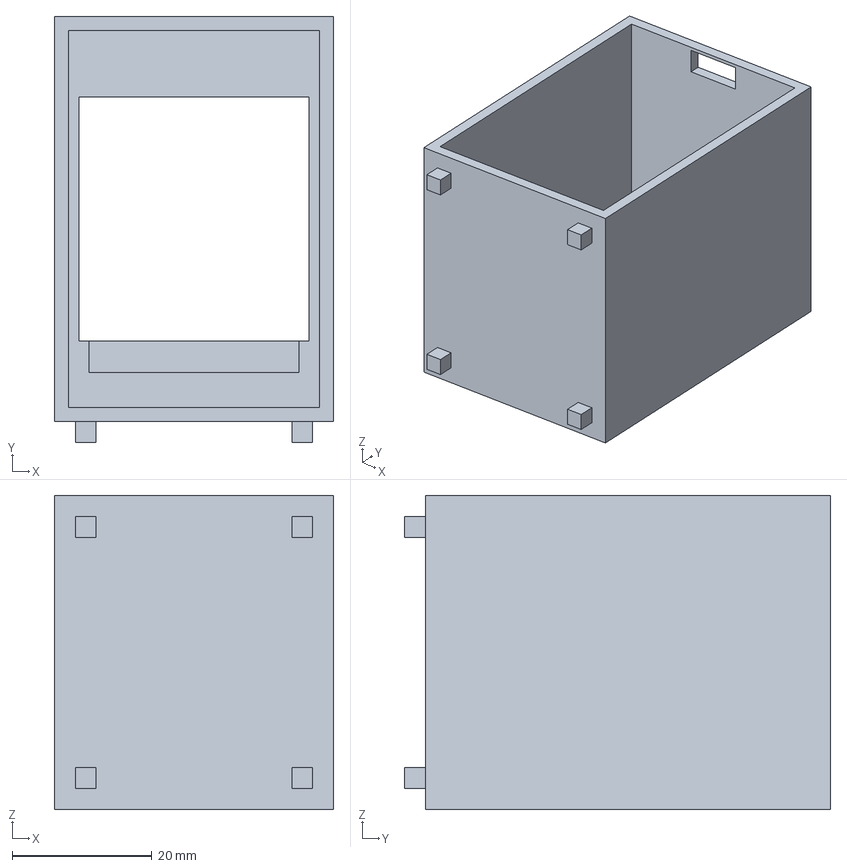
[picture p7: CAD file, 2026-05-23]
cc_hud_case.step
40.0 x 61.0 x 45.0 mm

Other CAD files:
cc_hud_back_cover.3mf
cc_hud_case.3mf

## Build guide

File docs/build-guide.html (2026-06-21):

# AI 状态灯 · 完整制作指南

一个放在桌上的透明小盒子：一块 1.54″ 彩屏显示 Claude Code 的额度 / 花费 / 状态，外圈 24 颗灯随 AI 在干嘛红黄绿变化。本指南覆盖从零件到点亮、从接线到刷机、再到手机网页遥控的全过程。

1 这是什么 2 怎么工作 3 零件 BOM 4 工具 ⚡ 引脚总表 🔧 焊接要点 5 接线（核心） 6 调 5V 7 刷固件 8 电脑端配置 🤖 多 AI 工具 ✚ 可选升级 9 装盒 ✓ 自检清单 10 排障

怎么读这份指南：每节左边灰栏是「线索栏」（关键词 + 这节回答的问题），右边是讲解和图，底部绿条是「一句话总结」——这是康奈尔笔记法，复习时只看左栏和绿条就能回忆全节。接线和上电这种「有先后顺序」的步骤，用分镜格（像连环画）一格一步。

🚀 最短路径（老手速览）：

1

焊屏

屏 8 线接主板（5A），VCC→3V3

2

焊电源

电池→TP4056→开关→MT3608，先调 5V

3

焊灯环

DIN→D2(GPIO5)经470Ω；VCC→MT3608 IN+；470µF

4

刷固件

USB 首刷 → 之后 WiFi OTA 秒刷

5

配电脑

statusline+hooks 推数据；push_wifi 配网

## 1这是个什么东西？

#### 线索

它解决什么痛点？

- AI 在终端干活，你不知道它在思考 / 等你 / 干完了
- 灯色 = 状态，瞄一眼就懂
- 屏 = 额度 / 花费 / 上下文

用 Claude Code 写代码时，AI 在终端里跑，但你常常不知道它正在思考、卡住等你确认、还是已经干完了。要么反复切回去看打断自己，要么忘了它在等你。

这个装置把「AI 在屏幕里的文字流」变成桌上一眼能懂的状态灯 + 数据屏。

成品示意图（同心圆套屏：屏从 24 灯环正中露出，同一平面）

灯的样子 | AI 在干嘛 | 你该做什么
绿色弧（亮的颗数=额度） | 空闲。同时把灯环当额度表用 | 不用管
黄色彗星绕圈 | 正在思考 / 跑工具 / 改代码 | 等它跑
红灯整环闪烁 | 卡住了 / 要权限 / 等你确认 | 马上去处理
微亮或全灭 | 夜间自动调暗 / 待机 | 不用管

📌 一句话总结：它是 AI 的「情绪 + 仪表表盘」——文字流变成桌上一眼看懂的灯色和数据。

## 2它是怎么工作的？

#### 线索

数据怎么从电脑到盒子？

- 电脑 → 脚本 → 蓝牙/WiFi → 盒子
- 两条无线路：BLE 推数据、WiFi 刷机+网页
- 盒子自带锂电，独立供电

本质是一条「传话链」。你的电脑知道 AI 在干嘛，把消息无线发给盒子，盒子控制屏和灯。这一版有两条无线通道：

整条传话链：AI 动作 → 脚本捕捉 → BLE 推数据（高频）/ WiFi 刷机+网页（按需）→ 主板接收 → 屏 4 页轮播 + 灯环变色。盒子与电脑之间全程无线，盒子靠自带锂电供电。

📌 一句话总结：电脑脚本把 AI 状态用蓝牙实时推给盒子；WiFi 额外提供秒级刷机和手机网页遥控。

## 3零件清单（BOM）

#### 线索

买什么？哪些有坑？

- 主板认准N8R8/N16R8，引脚对得上
- 屏认准 IPS · 8pin · 独立 CS
- 灯环 24 位 · 内径≥56mm
- 升压 MT3608 先调 5V 再接

类别 | 零件 | 选型要点 / 避坑
主板 | ESP32-S3 Nano（兼容 Arduino Nano） | N8R8 或 N16R8（Flash≥8MB）。⚠ 避开引脚对不上的便宜款。买未焊排针版直接焊线
屏 | 1.54″ ST7789 240×240 IPS | 4 线 SPI，8pin（GND/VCC/SCL/SDA/RES/DC/CS/BL）。认准 IPS + 独立 CS
灯环 | WS2812B 24 位 圆环 | ⚠ 内径必须 >56mm 才套得住屏；推荐内 60/外 72mm。避开 8/12/16 位小环
灯环配件 | 470Ω 电阻 + 470µF/10V 电解电容 | 电阻串 DIN；电容跨 VCC/GND。⚠ 电容有正负极
电源 | 3.7V 1000mAh 锂电（带保护板） | ⚠ 必须带保护板（安全底线）
充电 | TP4056 Type-C 带保护二合一 | 板上有 DW01+8205 两颗保护芯片。⚠ 认准带 CC 电阻(5.1K)版——很多便宜款没焊 CC 电阻，C-to-C 线充不进电（只能用 USB-A→C 线）。详情料里搜「5.1K」「支持 C to C」
升压 | MT3608（可调裸板） | ⚠ 装机前先单独调到 5.0V，否则可能输出 12V 烧主板
开关 | 16mm 自锁带灯按钮（5V 灯） | 总电源开关。⚠ 选自锁 + 5V 灯
外壳/耗材 | 透明亚克力盒 + 硅胶导线 26AWG + 焊锡 + 热缩管 + 双面泡棉胶 | 盒内净宽≥85mm 容下灯环
可选① | 2× 2.2kΩ 电阻（电池电量） | 做电池分压。电磁炮项目余料里就有（LED 指示用 2.2k）
可选② | 自复位轻触按钮 ×1（实体翻页键） | 同样可从电磁炮余料取；不接也能用网页遥控

💡 分两阶段做最稳：① 先把「ESP32 + 屏 + 电源」跑通，确认蓝牙能收到额度并显示；② 再加灯环。每步独立可验证，出问题好定位。

📌 一句话总结：核心五件 = 主板 + 屏 + 24 灯环 + 锂电链 + 盒子；电阻电容是灯环必备，分压电阻和按钮是可选升级。

## 4工具

#### 线索

动手前要备什么？

- 烙铁 + 焊锡（焊线不焊排针）
- 万用表（调 5V 必备）
- 热缩管护焊点

工具 | 用途 | 备注
恒温电烙铁套装 | 所有焊接 | 60W 可调，配吸锡/镊子
数字万用表 | 调 MT3608 的 5V、测通断 | ⚠ 不能省，这步靠它保命
热熔胶枪 | 固定灯环/底座 | 20W 小号
剥线钳 / 尖嘴钳 | 剥线、弯脚 | —

📌 一句话总结：烙铁 + 万用表是底线，万用表用来调 5V，没有它别接升压。

## ⚡引脚总表（接线前先背这张）

⚠ 这是整个项目最容易翻车的地方，务必先看。这块 ESP32-S3 Nano 用的是 Arduino Nano ESP32 真排列：丝印上低位 GPIO 标 A0–A7（不是 D！），高位标 D2–D13。千万别拿「GPIO 几」去板上找「D 几」——连 BOM 都把灯环写错成「D5」，实际是 D2(=GPIO5)。下表丝印为准。

接什么 | 板上丝印（照这个焊！） | = GPIO | 线色建议
屏 SCL（时钟） | D13 | GPIO48 | 黄
屏 SDA（数据） | D11 | GPIO38 | 绿
屏 CS（片选） | D10 | GPIO21 | 橙
屏 DC | D7 | GPIO10 | 白
屏 RES（复位） | D8 | GPIO17 | 蓝
屏 BL（背光） | D9 | GPIO18 | 灰
屏 VCC | 3V3 ⚠不是5V | — | 红
屏 GND | GND | — | 黑/灰
灯环 DIN（经470Ω） | D2 ⚠不是D5 | GPIO5 | 黄
电池电量（可选，经分压） | A0 | GPIO1 | —
按钮（可选） | A1 | GPIO2 | —

💡 拿不准就用万用表通断档：黑表笔搭板上某个丝印脚，红表笔去碰 ESP32 芯片对应引脚，响=对上了。低位脚记住口诀：A0=GPIO1、A1=GPIO2、…、D2=GPIO5、D3=GPIO6（A 段从 GPIO1 起，D 段从 GPIO5 起）。

## 🔧新手焊接要点

#### 线索

焊导线不焊排针，怎么焊好？

- 先上锡，再贴合
- 第三只手固定
- 焊点套热缩管
- 26AWG 软线好焊

本方案全部焊导线、不焊排针（保持低高度、贴平面板）。新手按这几条做不容易翻车：

1

两边先上锡

焊盘和线头各先熔一点锡（搪锡），再对上一碰即焊牢

2

第三只手

用焊接辅助夹固定板和线，腾出两只手拿烙铁+锡

3

先穿热缩管

焊前把热缩管先套到线上，焊完推过去吹热收紧

4

温度+时间

恒温 ~330℃，每点 ≤2 秒，焊点光亮饱满不拉尖

✓ 好焊点长这样：光亮、饱满、像小山包；轻拽线不动。灰暗、像球、一拽就掉 = 虚焊，重焊。

⚠ 最常见三个翻车：① 焊盘没上锡直接怼线 → 虚焊；② 烙铁停太久 → 焊盘脱落/烧坏元件；③ 忘了先穿热缩管 → 焊完才发现套不进去。

📌 一句话总结：两边先搪锡、第三只手固定、焊前先穿热缩管、每点 2 秒内。

## 5接线（核心）

分五部分：(A) 屏接主板、(B) 灯环接主板、(C) 电源链、(D) 电池电量（可选）、(E) 按钮（可选）。先别通电，全部焊好、调好 5V 再上电。

总装系统总览（先看懂整体，再逐段焊；下面每段是它的放大）

看懂这张就懂整体了：屏用 8 线接主板；灯环 DIN 经 470Ω 接主板 D2；电源链一路串下来到主板 5V；灯环电源从开关后的 MT3608 IN+ 取 3.7V（这样开关能一起关灯环）。下面 (A)–(E) 是每段的放大接法。

正极 / 电源 GND 地 数据/信号 数据/信号 ● 焊点（线落在引脚圆心）

### (A) 屏幕 ↔ 主板（8 根线，平行直连）

⚠ 屏的 VCC 一定接 3.3V（3V3），千万别接 5V，会烧屏！

屏 8 线接法：把屏 8 个引脚和主板对应脚按同一上下顺序排成两列，平行直连——这样 8 根线永不交叉。每根线两端都有焊点（●）落在引脚圆心。屏 VCC → 主板 3V3，绝不接 5V。

### (B) 灯环 ↔ 主板（含 470Ω 电阻 + 470µF 电容）

⚠ 灯环 DIN 接的是主板 GPIO5。注意：很多 ESP32-S3 Nano 克隆板丝印写 D2 才是 GPIO5（丝印的「D5」往往不是 GPIO5）。本指南固件按 GPIO5 配置——接到丝印 D2 那个脚。灯不亮先怀疑这里。

💡 为什么灯环电源接锂电 3.7V，不接主板 5V？WS2812B 用 5V 供电时要求数据高电平门槛 3.5V，而主板 GPIO 只能输出 3.3V，正好卡边界。改用 3.7V 锂电直供后 3.3V 数据就在安全区，免电平转换芯片。代价仅是灯略暗，状态指示无感。

灯环接法（3.7V 直供）：DIN 经 470Ω（靠灯环端，画成折线电阻、导线从中穿过）接主板 D2=GPIO5；VCC 接 MT3608 IN+（开关之后的 3.7V）——这样开关能一起关掉灯环；GND 与主板共地（虚线）；VCC↔GND 间跨一个 470µF 电容，长脚正极朝 VCC（符号长直板=+、短弧板=−）。

灯环脚 | 接到 | 中间元件 | 线色
VCC（+） | 开关之后、升压之前的 3.7V（= MT3608 的 IN+） | VCC↔GND 间并 470µF（长脚+朝VCC） | 红
GND（−） | 锂电负极 + 主板 GND（共地） | — | 灰/黑
DIN | 主板 D2（=GPIO5） | 串 470Ω（靠灯环端） | 黄

⚠ 灯环 VCC 必须接「开关之后」的 3.7V（MT3608 IN+），不能接 TP4056 OUT+ / 电池正极！否则开关只切主板、切不掉灯环 → 关机后灯环有电没信号，显示乱码常亮。接到开关后的 IN+，开关一关主板和灯环一起灭。

### (C) 电源链：电池 → 充电 → 开关 → 升压 → 主板

这是「有先后顺序」的部分，用分镜格一步一步看，再看整图：

1

电池 → TP4056

电池 +/− 焊到 TP4056 的 B+ / B−

2

TP4056 → 开关

OUT+ 接自锁开关一脚；OUT− 留作总负极

3

开关 → MT3608

开关另一脚 → MT3608 IN+；OUT− → IN−

4

先调 5V！

⚠ MT3608 单独通电，万用表拧到 5.0V

5

MT3608 → 主板

调好后 OUT+/OUT− → 主板 5V / GND

电源链：实线先焊，虚线（MT3608→主板）等第 4 步调好 5V 再接。灯环不接这条 5V，它从 MT3608 IN+（开关之后的 3.7V）取电（见 B 节）——这样开关能同时关掉主板和灯环。红=正极、灰=负极，别接反。
充电方法：USB-C 插 TP4056 自己的口（不是主板口）；充电时把主开关拨「关」，防 USB / 升压 / 电池三路反灌。⚠ 若 TP4056 缺 CC 电阻，C-to-C 线充不进（无灯）→ 改用 USB-A→C 线（见排障）。

### (D) 电池电量监测（可选，2× 2.2kΩ 分压）

💡 为什么要两个电阻？锂电满电 4.2V，但主板 ADC 最高只能量 ~3.3V，直接接会超量程甚至烧脚。两个等值电阻串联把电压砍一半（4.2V→2.1V），中间抽头给 ADC 读。固件已按 2:1 配置，不接也不影响其它功能（自动判定「无传感器」）。电阻无正负极，但抽头要接在两电阻中间。

电池分压：BAT+ →[R1 2.2kΩ]→ 中间抽头 →[R2 2.2kΩ]→ GND；抽头接主板 A0=GPIO1，GND 共地。两电阻等值即可（无正负极），关键是抽头取在两者正中间。接好后统计页 / 网页自动显示电量 % + 低电红字告警。

### (E) 实体按钮（可选，翻页 / 调暗）

💡 用什么零件：任意 2 脚自复位轻触开关（momentary tactile switch，按下导通、松开断开，无正负极）。淘宝搜「自复位按钮开关 2脚」或「6×6 轻触开关」。常见的 6×6mm 4 脚轻触开关也能用——它 4 个脚其实是两两内部相连的一组，取对角的两个脚即可。

接法：按钮一脚接 GPIO2（这块板丝印是 A1，不是 D1！低位 GPIO 标 A 开头），另一脚接 GND。固件用内部上拉，不按=高电平，按下接通到 GND=触发。短按翻页、长按调暗。不接也行——手机打开 cc-hud.local 网页有同样的「next page / dim」按钮。

⚠ 丝印对照（本 clone 板 = Arduino Nano ESP32 真排列）：GPIO1=丝印 A0、GPIO2=丝印 A1、GPIO5=丝印 D2。低位 GPIO 标 A0–A7，别照 GPIO 号去找「D+数字」。拿不准就用万用表通断档：从丝印脚量到 ESP32 芯片对应引脚确认。

按钮接法：GPIO2 ── 按钮 ── GND，就这两根。固件已就绪，接上即用；不接则用网页按钮。

## 6调 5V（MT3608）——上电前最关键一步

#### 线索

为什么先调 5V？

- 裸板出厂可能输出 12V+
- 直接接主板 = 烧板
- 万用表拧到 5.0V 再接

1

单独通电

MT3608 IN 接电池（经开关），OUT 先不接主板

2

表笔搭 OUT

万用表直流电压档，红表笔 OUT+、黑表笔 OUT−

3

拧电位器

慢拧蓝色电位器，读数调到 5.0V

4

断电再接

断电，OUT+/OUT− 接主板 5V/GND

⚠ 这步不能省、不能猜。没有万用表就别接升压——一旦输出过压，主板瞬间烧毁不可逆。

✓ 过关标准：万用表稳定读 4.9–5.1V 才能接主板。读数乱跳/偏高 → 继续拧电位器；拧到底还高 → 模块不对，换一个。

📌 一句话总结：MT3608 必须先单独通电、万用表拧到 5.0V，再接主板。

## 7刷固件（三条路）

#### 线索

怎么把固件烧进去？

- 首刷走 USB 串口
- 之后 BLE / WiFi OTA 无线刷
- 插电脑黑屏 = CDC 时序坑

三条路，按"什么情况用哪条"选：

方式 | 什么时候用 | 速度 | 前提
① USB 串口 | 第一次刷 / 彻底救砖 | ~10s | USB 数据线 + 板 USB 数据正常
② BLE OTA | 无 WiFi / WiFi 刷不了时救砖 | ~22s | 蓝牙权限 + 设备在广播
③ WiFi OTA | 日常迭代（最快） | ~2s 上传 | 已配过 WiFi（见下）

决策树：第一次 → 走①把固件刷进去 → 用 push_wifi.py 配一次 WiFi → 之后都用③。③ 刷不动了 / 设备失联 → 用② BLE 救回来（BLE 不依赖 WiFi）。

# ① USB 首刷
pio run -e esp32s3_nano -t upload

# ③ WiFi OTA（日常，先 build 再传；mDNS 抽风就用 IP）
pio run -e esp32s3_nano_wifi -t upload
pio run -e esp32s3_nano_wifi -t upload --upload-port 192.168.x.x

# ② BLE 救砖（不需要 WiFi，需蓝牙权限）
python ota.py --address <设备UUID> \
  --firmware .pio/build/esp32s3_nano/firmware.bin --verbose

⚠ 坑1：USB-C 插电脑，屏背光亮但不显示。ARDUINO_USB_CDC_ON_BOOT=1 时插活动 USB 主机会在开机早期触发枚举，干扰 ST7789 初始化时序。本指南固件已把 displayInit() 提到 Serial.begin() 之前修掉。

⚠ 坑2：USB 首刷识别不到串口。这块板 USB 数据偶尔不稳。按住 BOOT(GPIO0) → 点一下 RST → 松开，强制进 ROM 下载模式（只有 RST 键时，用镊子把 GPIO0 短到 GND 替代 BOOT）。还不行就换条数据线（很多是充电线没数据）。

✓ 刷成功的标志：USB 看到 Writing... 100% + 自动重启；OTA 看到 100% / OK / Success，设备屏一闪回到 HUD。WiFi OTA 进行时屏幕会显示进度条。

⚠ 救砖口诀：WiFi 刷不进 / 设备 ping 不通 → 别慌，BLE OTA 一定能救（蓝牙独立于 WiFi）。跑上面 ② 那条即可。

📌 一句话总结：首刷 USB → 配 WiFi → 日常 WiFi 秒刷；刷挂了用 BLE 救（蓝牙不依赖 WiFi）。

## 8电脑端配置

#### 线索

电脑怎么把数据推给盒子？

- statusline 推额度
- hooks 推状态
- 首次推一次 WiFi 凭证

三步：配网 → 接状态栏 → 接 hooks。(脚本都在仓库 host/ 下，先 cd host 建好 .venv)

① 一次性配 WiFi（经蓝牙推 SSID/密码，存盒子 NVS，之后开机自动联网）：

.venv/bin/python push_wifi.py --address <设备UUID> \
    --ssid '你的WiFi名' --password '你的密码' --verbose

② 状态栏推额度（~/.claude/settings.json）—— 每次刷新把 5h/7d 额度、ctx、成本、增删行推给盒子，顺带每 10 分钟校时+推天气：

"statusLine": { "type": "command",
  "command": "/你的路径/cc_hud_esp32/host/cchud-statusline.sh" }

③ hooks 推状态（同文件 "hooks" 段）—— 把 AI 的 thinking/tool/idle/waiting 推给盒子，多会话自动聚合（waiting>tool>thinking>idle）：

"UserPromptSubmit": [{"hooks":[{"type":"command","command":".../cchud-hook.sh thinking"}]}],
"PreToolUse":  [{"matcher":"*","hooks":[{"type":"command","command":".../cchud-hook.sh tool"}]}],
"PostToolUse": [{"matcher":"*","hooks":[{"type":"command","command":".../cchud-hook.sh thinking"}]}],
"Stop":         [{"hooks":[{"type":"command","command":".../cchud-hook.sh idle"}]}],
"Notification": [{"hooks":[{"type":"command","command":".../cchud-hook.sh waiting"}]}]

仓库 host/settings.hooks.example.json 是可直接抄的完整模板，把路径换成你的。

💡 网页面板：同 WiFi 下手机/电脑开 http://cc-hud.local/，看实时额度/成本/状态/电量，拖亮度滑块实时调灯环（存 NVS、免重刷），「next page / dim」遥控按钮 = 实体按钮的零硬件替代，底部还有 固件版本 / 运行时长 / 内存。

✓ 配好的标志：跟 Claude Code 对话时，盒子屏数字会变、灯环随状态变色；ping cc-hud.local 通。额度没动？多半是 Claude 这会儿还没下发 rate_limits（订阅用户真用起来才有），正常。

📌 一句话总结：push_wifi 配网 → statusLine 推额度 → hooks 推状态；之后手机网页实时看+遥控。

## 🤖支持多个 AI 工具（Claude / Codex …）

#### 线索

不止 Claude Code？

- 设备本身工具无关
- Claude：完整(额度+状态)
- Codex：状态灯(turn 级)
- 多工具会话自动聚合

盒子本身是工具无关的——谁往它推数据就显示谁。不同工具的"接入深度"取决于各自能暴露多少事件：

工具 | 能显示 | 怎么接
Claude Code | ✅ 额度(5h/7d) + 上下文 + 成本 + 4 状态灯(thinking/tool/idle/waiting) + 多会话 | statusLine + hooks（见上节，最完整）
Codex CLI | 🟢 答完一轮 → 灯环绿色脉冲闪三下（无视其它状态，一眼可见"该你看了"）。Codex 只暴露 turn 结束事件，没有 working 态 | config.toml 的 notify 指向适配器
其它工具 | 🟡 任意脚本调 push_state.py 即可推状态/灯色 | 通用 CLI

Codex 接法——编辑 ~/.codex/config.toml：

notify = ["/你的路径/cc_hud_esp32/host/cchud-codex-notify.sh"]

Codex 每个 turn 结束会调它 → 灯环绿色脉冲闪三下（"该你看了"）。这个脉冲无视当前状态强制显示 ~1.8 秒，所以即便 Claude 在忙也看得到。

注意：Codex 的 notify 只支持一个程序。若你已有别的 notify（如 computer-use），用 cchud-codex-dispatch.sh 链式调用同时保留两者，再把 notify 指向它。

💡 想要 Codex 也显示"working"黄灯？Codex 没有"开始工作"事件，notify 只在答完时触发。要细粒度需开 Codex 的实验性 hooks（~/.codex/hooks.json + codex_hooks flag），把 pre/post 事件指向 cchud-hook.sh tool / idle。实验特性、Windows 不支持。

✓ Codex 接好的标志：在终端跑 codex exec "说你好"，Codex 答完那刻 → 灯环绿色闪三下。已实测通过。

📌 一句话总结：设备工具无关；Claude 走 statusLine+hooks 最完整，Codex 走 config.toml 的 notify 显示 turn 级状态，多工具会话自动聚合。

## ✚可选升级（做不做都行）

#### 线索

还能加什么？

- 电量显示（2 电阻）
- 实体翻页键（1 按钮）
- 亮度/天气/夜间（纯软件）

升级 | 要什么料 | 怎么接 / 怎么设 | 效果
电池电量 | 2× 2.2kΩ 电阻 (电磁炮余料就有) | BAT+ →[2.2k]→中间抽头→[2.2k]→ GND；抽头接 A0(GPIO1)。详见接线 (D) 节 | 统计页 + 网页显示电量%；低电灯环橙闪
实体按钮 | 2 脚自复位轻触开关 (电磁炮余料就有) | 一脚 A1(GPIO2)、一脚 GND。详见接线 (E) 节 | 短按翻页、长按调暗（网页也能做，不接也行）
灯环亮度 | 纯软件（网页） | 手机开 cc-hud.local，拖亮度滑块实时调，存 NVS、重启不丢、免重刷 | 1–60；8–10 柔和、14–18 适中
时钟（NTP 自动） | 纯软件（已内置） | WiFi 在线时自动从网络授时，断电后自动恢复，无需手动校准 | 设 CCHUD_WEATHER_CITY 还可在时钟页显示天气
夜间自动调暗 | 纯软件（已内置） | 23:00–07:00 屏+灯自动变暗；空闲 3 分钟也自动调暗、10 分钟熄灯环 | 护眼省电，无需操作
固件版本/健康 | 纯软件（网页） | 网页底部显示 fw 版本 · 运行时长 · 可用内存 | 排障/确认刷没刷成功

💡 这些都是"接上/改完即生效"：电量和按钮没接时固件判为"无传感器/松开"，绝不误报，可随时补。

📌 一句话总结：电量=2电阻接A0、按钮=1开关接A1、亮度/天气/夜间是纯软件，都可选、可后补。

## 9装盒（同心圆套屏）

#### 线索

怎么固定？

- 灯环 + 屏贴前面板内壁
- 同一平面，屏从环中露出
- 焊点套热缩管，电池别扎到

装配：灯环和屏都用双面泡棉胶贴在前面板内壁，屏从灯环正中露出、与环同平面（同心圆效果）；主板/电池/电源模块叠在后方；开关和 TP4056 充电口开在盒子侧面。电池焊点务必套热缩管，装盒别被焊点扎破电池。

📌 一句话总结：灯环+屏贴前面板同一平面成同心圆，主板电池叠后方，开关充电口开侧面。

## ✓成品自检清单

#### 线索

通电前 / 通电后逐项核对

- 先断电查焊接
- 再上电查显示
- 最后查无线

① 通电前（万用表通断档，断电状态）

检查 | 期望
屏 VCC ↔ 主板 3V3 | 通；且 不与 5V 相通
灯环 VCC ↔ MT3608 IN+ | 通（开关后的 3.7V，不是 TP4056 OUT+）
灯环 GND ↔ 主板 GND | 通（共地）
电容长脚 ↔ 灯环 VCC | 通（长脚=正极朝 VCC）
任意 VCC ↔ 任意 GND | 不通（通=短路，排查）
MT3608 OUT+ 电压 | 单独通电拧到 5.0V 再接主板

② 通电后（先电池供电）

检查 | 期望
屏点亮 | 显示 HUD（标题/额度条/footer）
开关断开 | 屏 + 灯环一起灭（不灭=灯环接错到开关前）
灯环 | 空闲=绿色弧；推 state 测试=黄/红变化

③ 无线

检查 | 期望
BLE 推额度 | 屏数字更新、右上点变绿
ping cc-hud.local | 通（WiFi 已连）
手机开 cc-hud.local | 看到实时面板 + 翻页/调暗按钮

📌 一句话总结：断电先查「该通的通、该断的断、5V 调好」，上电查「屏亮 + 开关能关灯环」，最后查「BLE/WiFi 通」。

## 10排障（实战汇总）

#### 线索

不亮 / 不显示 / 不更新？

- 电池正常但 USB 不显示
- 灯不亮的 4 个原因
- 屏没新数据

症状 | 原因 | 解决
USB-C 供电屏亮但不显示，电池供电正常 | USB CDC 枚举干扰屏初始化时序 | 刷本指南固件（displayInit 已前移）；或先用纯充电头（不走数据）
USB-C 插电脑识别不到串口 | 线是充电线 / 没进下载模式 | 换数据线；按住 GPIO0 再点 RST 进下载模式
灯完全不亮 | ① DIN 接到的不是 GPIO5（丝印 D5≠GPIO5，应接 D2） ② 电容接反击穿，把 VCC 拉到 ~0.6V ③ 没共地 ④ 3.7V 太低 | ① 改接丝印 D2 ② 拆掉/换电容，长脚+朝 VCC ③ 灯环 GND 与主板 GND 直连 ④ 给电池充电
只亮约 1/3 的灯 | 固件灯数配成 8，实际 24 | 用本指南固件（已配 24）
彗星转太快 | 步进太短 | 本指南固件已调到 ~2s/圈
屏显示但额度不更新 | Claude Code 暂未下发 rate_limits（新会话/长时间没调 API） | 正常现象；真正交互产生用量后 30s 内自动更新
电池电量不显示 | 分压电阻没接（显示「无传感器」） | 接 2× 2.2kΩ 分压到 GPIO1（D 节）
电容鼓包/发烫 | 电解电容接反 | 立即断电，换新电容，长脚+朝 VCC
TP4056 插 Type-C 没灯不充电，但 USB-A→C 线能充 | TP4056 的 Type-C 缺 CC 下拉电阻(5.1K)，C-to-C 线检测不到受电端就不供电（Apple C-to-C 尤其严格） | ① 最省事：充电固定用 USB-A→C 线（已能充） ② 彻底：换一块带 CC 电阻的 TP4056 ③ 自补：CC1、CC2 各加一个 5.1kΩ 下拉到 GND（脚小难焊）
TP4056 完全没灯（USB-A 也没） | 线是纯充电线坏了 / Type-C 座虚焊 / 模块坏 | 换数据线；补焊 Type-C 座 4 角脚；万用表量输入有无 5V，没有就换模块

📌 一句话总结：USB 黑屏=CDC 时序、灯不亮先查 D2/电容极性/共地、额度不更新多是 Claude 还没下发数据。

AI 状态灯 · 完整制作指南 · 基于 cc_hud 固件（含 WiFi 网页面板 / 4 屏轮播 / 燃烧预测 / 夜间调暗 / 电池 / 按钮）

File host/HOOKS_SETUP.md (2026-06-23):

# CC-HUD 主机接入指南(Claude Code / Codex)

把 CC-HUD 硬件接到 Claude Code 与 Codex:实时显示**工作状态**(思考/工具/等待/空闲)
和**额度**(5h/7d 用量、会话开销),全程走 BLE,不依赖 WiFi。

本文同时面向**人**和**AI IDE**:第 5 节给出可直接粘贴给 AI 的一键指令。

---

## 1. 设备地址速查(macOS CoreBluetooth UUID)

> ⚠️ 这些 UUID 只在**对应那台 Mac** 上有效:macOS 不暴露蓝牙真实 MAC,CoreBluetooth
> 给「每台主机 × 每个设备」各自生成 UUID。换 Mac、重装系统、清蓝牙缓存都可能让它变。
> 变了就用 `push_quota.py --discover` 重新发现(设备名 `CC-HUD` 是固件广播的,跨机器不变)。

| 用途 | 地址 (UUID) | 设备名 | 说明 |
|---|---|---|---|
| **当前设备(在用)** | `EC875770-C5EA-539F-2A65-EAF348861E29` | `CC-HUD` | 现在连接的设备,已写入全部脚本默认值 |
| 旧设备 | `0A12EA0B-ECB0-6020-64E9-8C72447DEB51` | `CC-HUD` | 最早连接过的那块 HUD |
| 原作者仓库内置 | `03265204-7126-B6FE-6F17-6E9621CEA97F` | `CC-HUD` | 原作者(firshme)Mac 的 UUID,**在别的 Mac 上无效** |

**UUID 写在这 4 个脚本里**(默认值,可被环境变量 `CCHUD_ADDR` 覆盖):
`cchud-hook.sh`、`cchud-quota-push.sh`、`cchud-update.sh`、`cchud-codex-notify.sh`。

---

## 2. 组成与文件清单

| 文件 | 作用 | 触发方 |
|---|---|---|
| `cchud-hook.sh` | 把 Claude Code 的应用状态(思考/工具/空闲/等待)推到 HUD;多会话聚合取最高优先级;BLE 串行锁 | Claude Code 5 个 hook 事件 |
| `cchud-statusline.sh` | statusLine 包装器:原样渲染 `ccstatusline` + 后台推额度,不阻塞状态栏 | Claude Code `statusLine` |
| `cchud-quota-push.sh` | 从 statusline JSON 取官方 `rate_limits` 百分比(5h/7d)+ 会话开销 + 模型名标题,跨会话取最大值合并 | 被 `cchud-statusline.sh` 调用 |
| `cchud-update.sh` | 限频(30s)、后台、串行化的额度 BLE 推送(传输层) | 被 `cchud-quota-push.sh` 调用 |
| `cchud-codex-dispatch.sh` | Codex `notify` 分发器:保留原有 notify(如 computer-use)+ 追加 CC-HUD | Codex `notify` |
| `cchud-codex-notify.sh` | Codex → CC-HUD 适配:回合结束推绿色 done-pulse | 被 dispatch 调用 |
| `push_state.py` / `push_quota.py` | 底层 BLE 写入(bleak);`push_quota.py --discover` 用于发现设备 | 被上面脚本调用 / 手动 |

状态映射:`UserPromptSubmit→thinking`、`PreToolUse→tool`、`PostToolUse→thinking`、
`Stop→idle`、`Notification→waiting`(良性提示自动降级为 idle)。

---

## 3. 新电脑首次配置

> 约定:`CCHUD_DIR` = 本仓库的 `host` 目录绝对路径(例:`/Users/<you>/github/cc_hud_esp32/host`)。
> 下面命令把它先设成变量,后续复用。

### 3.1 依赖

```bash
# 必需:jq(解析 hook/statusline JSON)、Python venv + bleak(BLE)
brew install jq            # 没装 Homebrew 就用系统包管理器
command -v uv >/dev/null || curl -LsSf https://astral.sh/uv/install.sh | sh

CCHUD_DIR="$(cd "$(dirname "$0")" 2>/dev/null && pwd)"   # 或手动填绝对路径
cd "$CCHUD_DIR"
uv venv .venv
uv pip install --python .venv/bin/python -r requirements.txt
.venv/bin/python -c "from bleak import BleakClient; print('bleak OK')"
# 额度功能还需要 bunx(随 bun 安装),且你已在用 ccstatusline;只要状态灯可不装
```

### 3.2 发现设备 UUID

给 HUD 通电(USB-C 或电池+自锁开关,屏幕亮、在广播),然后:

```bash
cd "$CCHUD_DIR"
.venv/bin/python push_quota.py --discover --verbose --timeout 8
# 输出形如:
# ADDRESS                                   NAME     RSSI
# XXXXXXXX-XXXX-XXXX-XXXX-XXXXXXXXXXXX      CC-HUD   -42 dBm
```

记下 `CC-HUD` 那行的地址,设为 `NEW_UUID`。

### 3.3 写入 UUID(一条命令改全部 4 个脚本)

```bash
cd "$CCHUD_DIR"
NEW_UUID="XXXXXXXX-XXXX-XXXX-XXXX-XXXXXXXXXXXX"   # ← 换成 3.2 发现的
# macOS 的 sed 需要 -i ''(GNU/Linux 用 sed -i)
sed -i '' -E "s/CCHUD_ADDR:-[0-9A-Fa-f-]+/CCHUD_ADDR:-$NEW_UUID/" \
  cchud-hook.sh cchud-quota-push.sh cchud-update.sh cchud-codex-notify.sh
grep -l "$NEW_UUID" cchud-hook.sh cchud-quota-push.sh cchud-update.sh cchud-codex-notify.sh
```

### 3.4 Claude Code hooks(合并进 `~/.claude/settings.json`)

把下面 5 项**合并**进现有 `hooks`(不要整体覆盖,保留你已有的 hook)。
把 `<CCHUD_DIR>` 替换为绝对路径。

```json
{
  "hooks": {
    "UserPromptSubmit": [{ "hooks": [{ "type": "command", "command": "<CCHUD_DIR>/cchud-hook.sh thinking" }] }],
    "PreToolUse":  [{ "matcher": "*", "hooks": [{ "type": "command", "command": "<CCHUD_DIR>/cchud-hook.sh tool" }] }],
    "PostToolUse": [{ "matcher": "*", "hooks": [{ "type": "command", "command": "<CCHUD_DIR>/cchud-hook.sh thinking" }] }],
    "Stop":         [{ "hooks": [{ "type": "command", "command": "<CCHUD_DIR>/cchud-hook.sh idle" }] }],
    "Notification": [{ "hooks": [{ "type": "command", "command": "<CCHUD_DIR>/cchud-hook.sh waiting" }] }]
  },
  "statusLine": { "type": "command", "command": "<CCHUD_DIR>/cchud-statusline.sh", "padding": 0 }
}
```

- `statusLine` 是**额度推送**入口(可选)。`cchud-statusline.sh` 内部会调 `bunx -y ccstatusline@latest`
  渲染你原来的状态栏 —— 若你用别的状态栏工具,改这一行包装即可;只要状态灯不配 `statusLine` 也行。
- hooks **会话启动时加载**,改完要**新开会话**才生效。

### 3.5 Codex notify(`~/.codex/config.toml`)

**情况 A:你没有其它 notify**(最简单)——直接指向 CC-HUD 适配器:

```toml
notify = ["<CCHUD_DIR>/cchud-codex-notify.sh"]
```

**情况 B:你已有 notify**(例如 computer-use,想保留)——用分发器,并把它内部的
`ORIG` 改成你原来的 notify 程序绝对路径:

```toml
notify = ["<CCHUD_DIR>/cchud-codex-dispatch.sh"]
```

```bash
# 编辑 cchud-codex-dispatch.sh,把 ORIG 改成本机的 computer-use(或你的)notify:
#   ORIG="/Users/<you>/.codex/computer-use/.../SkyComputerUseClient"
```

Codex 同样需**新开会话**生效。

### 3.6 验证(不依赖真机也能验证接线)

```bash
cd "$CCHUD_DIR"
# 真机直推一发状态,屏幕应闪「工具/Bash」:
.venv/bin/python push_state.py --address "$NEW_UUID" --state tool --detail Bash --timeout 8
# 真机直推额度,屏幕应显示 5h/7d 条:
CCHUD_MODE=sub ./cchud-update.sh 8 100 4 100 0 0
# 退出码 0 + 屏幕响应 = 成功。然后新开 Claude/Codex 会话,实跑观察。
```

---

## 4. 旧电脑切换 UUID(换了设备 / UUID 变了)

只需「重新发现 + 一条 sed」:

```bash
cd "$CCHUD_DIR"
.venv/bin/python push_quota.py --discover --verbose --timeout 8   # 拿到新 UUID
NEW_UUID="XXXXXXXX-XXXX-XXXX-XXXX-XXXXXXXXXXXX"
sed -i '' -E "s/CCHUD_ADDR:-[0-9A-Fa-f-]+/CCHUD_ADDR:-$NEW_UUID/" \
  cchud-hook.sh cchud-quota-push.sh cchud-update.sh cchud-codex-notify.sh
```

无需重配 hooks(脚本路径没变)。`statusLine`/hooks 是热的额度部分立即生效;
状态 hook 因缓存在会话内,**新开会话**后用新 UUID。

> 临时只想换一次、不改脚本:`export CCHUD_ADDR=新UUID`(脚本默认值会让位给环境变量)。

---

## 5. 给 AI IDE 的一键指令(直接粘贴)

> 把下面整段发给 AI IDE(Claude Code / Cursor / Codex 等),并按提示补上你的实际路径。

```
请帮我把本仓库 host/ 目录下的 CC-HUD hooks 配置到 Claude Code 和 Codex,按 host/HOOKS_SETUP.md 执行:
1. 在 host/ 下用 uv 建 .venv 并安装 requirements.txt(bleak);确认 jq 已安装。
2. 运行 `.venv/bin/python push_quota.py --discover --verbose --timeout 8` 发现我的设备 UUID
   (设备名 CC-HUD);把发现到的 UUID 用一条 sed 写入 cchud-hook.sh / cchud-quota-push.sh /
   cchud-update.sh / cchud-codex-notify.sh 的 CCHUD_ADDR 默认值。
3. 把 HOOKS_SETUP.md 第 3.4 节的 5 个 hook + statusLine **合并**进 ~/.claude/settings.json
   (保留我已有的 hook,不要覆盖;命令里的路径用 host 目录绝对路径)。用 jq/python 校验 JSON 合法。
4. 按 3.5 节配置 ~/.codex/config.toml 的 notify(我没有其它 notify 就用情况 A 直连 cchud-codex-notify.sh)。
   先备份 settings.json 和 config.toml。
5. 按 3.6 节做真机验证(push_state.py 推一发 tool、cchud-update.sh 推一发额度),报告退出码和屏幕反应。
注意:hooks 改完需新开会话才生效;UUID 是 macOS CoreBluetooth UUID、本机专属。
```

---

## 6. 故障排查

| 现象 | 原因 / 处理 |
|---|---|
| `Device ... not found` | 设备没通电/没广播,或 UUID 不对(换机器/重装后会变)→ 重新 `--discover` 改 UUID;`--timeout 20` 再试 |
| `--discover` 扫不到 | 蓝牙没开 / 终端无蓝牙权限(系统设置→隐私与安全性→蓝牙)/ 设备未上电 |
| 状态灯一直 thinking 停不下 | 已修(固件:quota 推送不再误触发 thinking)。若仍有,确认设备已刷最新固件 |
| 额度数字与官方面板对不上 | 额度取自 statusline JSON 的官方 `rate_limits` 百分比;多会话取最大值合并,与面板一致(允许刷新延迟) |
| 灯环不亮但屏幕正常 | 灯环走 MT3608(自锁开关之后);纯 USB 没拨开关时灯环无电,拨开关走电池链路 |
| 日志 | 状态:`/tmp/cchud-state.log`;额度:`/tmp/cchud-push.log`;Codex:`/tmp/cchud-codex.log` |

环境变量覆盖:`CCHUD_ADDR`(地址)、`CCHUD_RATE_LIMIT`(额度限频秒,默认 30)、
`CCHUD_5H_LIMIT`/`CCHUD_7D_LIMIT`(已弃用,现按官方百分比)、`CCHUD_TITLE`(覆盖标题)。

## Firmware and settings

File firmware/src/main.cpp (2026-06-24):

// main.cpp
// Top-level firmware for cc_hud. Glues persistence, display, and the BLE
// GATT server into a small state machine:
//
//   setup():    init Serial, init NVS, load last quota, init ST7789, init BLE
//   loop():     drain redraw / connection events, refresh footer every 5 s
//
// BLE callbacks fire on the NimBLE task; they push parsed state into
// `g_quota` / `g_conn_*` under a portMUX critical section, then set flags
// for the main task to consume. Display rendering only happens in loop().

#include <Arduino.h>

#include <cstring>

#include "battery.h"
#include "ble_server.h"
#include "button.h"
#include "config.h"
#include "display.h"
#include "led_ring.h"
#include "lvgl_ui.h"
#include "ota_server.h"
#include "persistence.h"
#include "wifi_ota.h"

namespace cc_hud {

// Shared state between BLE callbacks (NimBLE task) and the Arduino loop task.
portMUX_TYPE  g_lock = portMUX_INITIALIZER_UNLOCKED;
QuotaSnapshot g_quota;

volatile bool g_redraw_pending = true;
volatile bool g_conn_pending   = false;
volatile bool g_conn_state     = false;
volatile bool g_alert_pending  = false;  // set true when a 5h/7d crossing >= 95% fired
volatile bool g_force_idle     = false;  // explicit force-idle latch (msg_type 0x05)
volatile int8_t g_force_mood   = kPetMoodAuto;  // -1 = compute from quota; else 0..4
volatile uint32_t g_thinking_until_ms = 0;  // millis() until which we draw the star

constexpr uint32_t kThinkingHoldMs = 90UL * 1000UL;  // 90s window after any quota push

// App-state, pushed by Claude Code hooks via msg_type 0x07.
volatile int8_t g_app_state = kAppStateUnset;
char            g_app_state_detail[kAppStateDetailMaxLen + 1] = {0};
// 介入类型(state=waiting 时):0=none 1=approval 2=question 3=error(第 3 层)
volatile uint8_t g_app_intervention = 0;
// 会话列表(第 4 层),由 v7 帧解析填充,按优先级排序(等你的在前)
V7Session g_v7_sessions[kMaxV7Sessions];
volatile uint8_t g_v7_session_count = 0;
// Multi-session counts from the aggregating hook (stage 3). 0 = unknown.
volatile uint8_t g_total_sessions = 0;
volatile uint8_t g_busy_sessions  = 0;
// One-shot "an AI finished a turn" pulse request (state 0x04 = done).
volatile bool g_ping_pending = false;

// Compute percent (mirrors the helper in display.cpp; keeping it local avoids
// pulling display internals into the BLE callback path).
static uint8_t computePct(uint16_t used, uint16_t limit) {
    if (limit == 0) return 0;
    const uint32_t pct = (static_cast<uint32_t>(used) * 100u) / limit;
    return pct > 100u ? 100u : static_cast<uint8_t>(pct);
}

// --------------------------------------------------------------- callbacks --
//
// Invoked from the NimBLE task. Keep the work minimal: stash the parsed
// snapshot, persist to NVS, flip the redraw flag — the main loop does the
// actual display work.
void onQuotaWrite(const QuotaSnapshot& parsed) {
    // Carry the alert flags and the idle-time fields forward from the
    // previous snapshot — a v1/v2/v3 payload only describes quota state,
    // so unix_ts / utc_offset_min / time_capture_ms / idle_status must
    // be preserved across writes (otherwise the idle screen would lose
    // its calibrated clock every time the statusline pushes quota).
    QuotaSnapshot next;
    {
        portENTER_CRITICAL(&g_lock);
        const bool      prev_alerted_5h    = g_quota.alerted_5h;
        const bool      prev_alerted_7d    = g_quota.alerted_7d;
        const uint32_t  prev_unix_ts       = g_quota.unix_ts;
        const int16_t   prev_utc_offset    = g_quota.utc_offset_min;
        const uint64_t  prev_time_capture  = g_quota.time_capture_ms;
        char            prev_idle_status[33];
        std::strncpy(prev_idle_status, g_quota.idle_status,
                     sizeof(prev_idle_status));
        prev_idle_status[sizeof(prev_idle_status) - 1] = '\0';
        portEXIT_CRITICAL(&g_lock);

        next = parsed;
        next.alerted_5h      = prev_alerted_5h;
        next.alerted_7d      = prev_alerted_7d;
        next.unix_ts         = prev_unix_ts;
        next.utc_offset_min  = prev_utc_offset;
        next.time_capture_ms = prev_time_capture;
        std::strncpy(next.idle_status, prev_idle_status,
                     sizeof(next.idle_status));
        next.idle_status[sizeof(next.idle_status) - 1] = '\0';
    }

    bool need_flash = false;
    if (next.mode == kSnapshotModeSubscription) {
        const uint8_t pct_5h = computePct(next.used_5h, next.limit_5h);
        const uint8_t pct_7d = computePct(next.used_7d, next.limit_7d);

        if (pct_5h < kAlertThresholdPct) next.alerted_5h = false;
        if (pct_7d < kAlertThresholdPct) next.alerted_7d = false;

        if (pct_5h >= kAlertThresholdPct && !next.alerted_5h) {
            next.alerted_5h = true;
            need_flash = true;
            Serial.printf("[ALERT] 5H crossed %u%% (now %u%%)\n",
                          (unsigned)kAlertThresholdPct, (unsigned)pct_5h);
        }
        if (pct_7d >= kAlertThresholdPct && !next.alerted_7d) {
            next.alerted_7d = true;
            need_flash = true;
            Serial.printf("[ALERT] 7D crossed %u%% (now %u%%)\n",
                          (unsigned)kAlertThresholdPct, (unsigned)pct_7d);
        }
    } else {
        // API mode has no notion of % usage — never alert.
        next.alerted_5h = false;
        next.alerted_7d = false;
    }

    portENTER_CRITICAL(&g_lock);
    g_quota          = next;
    g_redraw_pending = true;
    if (need_flash) g_alert_pending = true;
    // NOTE: deliberately do NOT touch g_thinking_until_ms here. The app-state
    // (idle/thinking/tool) is driven solely by explicit state pushes
    // (msg_type 0x07) from the hooks. Coupling it to quota writes made the
    // statusline's ~30s quota cadence perpetually re-arm a 90s "thinking"
    // window, so the device looked stuck "thinking" forever once any quota
    // arrived (the legacy fallback below only fires while no 0x07 has ever
    // been seen — e.g. right after boot — but the quota cadence kept it lit).
    portEXIT_CRITICAL(&g_lock);

    if (persistenceSave(next)) {
        Serial.println("[NVS] saved");
    } else {
        Serial.println("[NVS] save FAILED");
    }
}

void onConnChange(bool connected) {
    portENTER_CRITICAL(&g_lock);
    g_conn_state   = connected;
    g_conn_pending = true;
    portEXIT_CRITICAL(&g_lock);
}

// v4 idle write: host pushed wall clock + status string. We merge only
// the idle fields into g_quota, leaving the quota data alone, and we
// deliberately do NOT update last_update_ms — that timer still counts
// from the last v1/v2/v3 quota write so the 30-min idle threshold
// behaves correctly.
void onIdleWrite(uint32_t unix_ts,
                 int16_t  utc_offset_min,
                 uint64_t capture_ms,
                 const char* idle_status) {
    // Sentinel: utc_offset_min == -32768 means "this is a force-idle
    // toggle command, not a normal time push". The unix_ts field carries
    // the command (1 = enter forced idle, 0 = leave).
    if (utc_offset_min == -32768) {
        portENTER_CRITICAL(&g_lock);
        g_force_idle = (unix_ts != 0);
        g_redraw_pending = true;
        portEXIT_CRITICAL(&g_lock);
        Serial.printf("[FORCE] g_force_idle = %d\n",
                      static_cast<int>(unix_ts != 0));
        return;
    }

    portENTER_CRITICAL(&g_lock);
    g_quota.unix_ts         = unix_ts;
    g_quota.utc_offset_min  = utc_offset_min;
    g_quota.time_capture_ms = capture_ms;
    std::strncpy(g_quota.idle_status, idle_status,
                 sizeof(g_quota.idle_status) - 1);
    g_quota.idle_status[sizeof(g_quota.idle_status) - 1] = '\0';
    g_redraw_pending = true;
    QuotaSnapshot snapshot_copy = g_quota;
    portEXIT_CRITICAL(&g_lock);

    if (persistenceSave(snapshot_copy)) {
        Serial.println("[NVS] idle saved");
    }
}

// v7 app-state write: Claude Code hook → host script → BLE → here.
// `state` is one of AppState (0..3). `detail` is the tool name when
// state == kAppStateTool, empty otherwise. We just stash it for the
// main loop's state tick to pick up.
void onStateWrite(int8_t state, const char* detail,
                  uint8_t total_sessions, uint8_t busy_sessions,
                  uint8_t intervention_kind,
                  const V7Session* sessions, uint8_t session_count) {
    // state 0x04 (done) is a one-shot "turn finished" signal: fire the green
    // done-pulse and settle to idle rather than persisting a "done" state.
    if (state == kAppStateDone) {
        g_ping_pending = true;
        state = kAppStateIdle;
    }
    portENTER_CRITICAL(&g_lock);
    g_app_state = state;
    g_app_intervention = intervention_kind;
    g_v7_session_count = session_count;
    for (uint8_t i = 0; i < session_count && i < kMaxV7Sessions; i++) {
        g_v7_sessions[i] = sessions[i];
    }
    std::strncpy(g_app_state_detail, detail,
                 sizeof(g_app_state_detail) - 1);
    g_app_state_detail[sizeof(g_app_state_detail) - 1] = '\0';
    g_total_sessions = total_sessions;
    g_busy_sessions  = busy_sessions;
    portEXIT_CRITICAL(&g_lock);
    Serial.printf("[STATE] %d (%s) sess=%u/%u\n",
                  static_cast<int>(state), detail,
                  static_cast<unsigned>(busy_sessions),
                  static_cast<unsigned>(total_sessions));
}

// v9 WiFi credentials write — persist + reconnect. Safe to call from the
// NimBLE task; wifi_ota's NVS write is small/fast and WiFi.begin is
// non-blocking.
void onWifiWrite(const char* ssid, const char* password) {
    cc_hud::wifiOtaSetCredentials(ssid, password);
}

// ----------------------------------------------------- burn prediction --
// Tracks usage over time and exposes a smoothed burn rate so the HUD can
// warn "this window will hit 100% before it resets". Fed one fresh sample
// per quota push (~30 s cadence); EMA-smoothed to ride out the noise.
struct BurnTrack {
    bool     have       = false;
    uint64_t t_ms       = 0;
    uint16_t used       = 0;
    float    rate_per_s = 0.0f;   // EMA of used-units per second
};

void burnUpdate(BurnTrack& b, uint16_t used, uint64_t t_ms) {
    if (!b.have) { b.have = true; b.t_ms = t_ms; b.used = used; return; }
    if (t_ms <= b.t_ms) return;
    if (used < b.used) {            // window reset → restart cleanly
        b.t_ms = t_ms; b.used = used; b.rate_per_s = 0.0f; return;
    }
    const float dt = (t_ms - b.t_ms) / 1000.0f;
    if (dt < 1.0f) return;
    const float inst = (used - b.used) / dt;   // units/sec
    b.rate_per_s = (b.rate_per_s > 0.0f)
                       ? 0.6f * b.rate_per_s + 0.4f * inst
                       : inst;
    b.t_ms = t_ms;
    b.used = used;
}

// Projected seconds until `used` reaches `limit`. 0 = no usable prediction.
uint32_t burnEtaSeconds(const BurnTrack& b, uint16_t used, uint16_t limit) {
    if (b.rate_per_s <= 0.0001f || used >= limit) return 0;
    return static_cast<uint32_t>((limit - used) / b.rate_per_s);
}

// Seconds remaining until a window resets, decremented live from millis().
uint32_t resetRemaining(uint32_t captured_s, uint64_t cap_ms, uint64_t now_ms) {
    if (captured_s == 0) return 0;
    const uint32_t el = static_cast<uint32_t>(
        (now_ms >= cap_ms ? now_ms - cap_ms : 0) / 1000ULL);
    return el >= captured_s ? 0u : captured_s - el;
}

}  // namespace cc_hud

// ============================================================== Arduino ===
void setup() {
    // Bring up the panel FIRST, before USB CDC enumeration. With
    // ARDUINO_USB_CDC_ON_BOOT=1, plugging into an active USB host triggers
    // enumeration during the early boot window — host-side DTR/RTS toggles
    // and the USB interrupt storm can disturb ST7789 SPI init timing,
    // leaving the panel backlit but blank. Doing displayInit() before
    // Serial.begin() guarantees the SPI init sequence completes on a quiet
    // bus. (We lose the [TFT] log line — no CDC yet — but that's fine.)
    cc_hud::displayInit();
    cc_hud::lvglUiInit();

    // LED ring (WS2812B status light). Boots in Off mode; loop() drives
    // it from g_app_state once BLE hooks start arriving.
    cc_hud::ledRingInit();

    // WiFi + ArduinoOTA — no-op if NVS has no creds yet; otherwise connects
    // in the background and starts listening on cc-hud.local:3232.
    cc_hud::wifiOtaInit();

    // Optional add-ons — both ship safe when unwired (see config.h).
    cc_hud::batteryInit();
    cc_hud::buttonInit();

    Serial.begin(115200);
    // Only pause for USB-CDC enumeration if a host is actually attaching, so
    // early boot logs aren't lost when debugging over USB. `Serial` turns
    // truthy once the host asserts the CDC line, so we break out the instant
    // it's ready. On battery/charger no host ever attaches, so this falls
    // through after a short cap instead of the old fixed 2.5s stall — boot
    // feels instant off-USB. (Capped so a flaky CDC line can't hang startup.)
    for (uint32_t t0 = millis(); !Serial && (millis() - t0) < 600u; ) {
        delay(10);
    }
    Serial.println();
    Serial.println("[BOOT] cc_hud v1");
    Serial.println("[TFT] init done (pre-CDC)");
    Serial.printf("[CHIP] %s rev %d, %lu MHz, flash %lu MB, psram %lu B\n",
                  ESP.getChipModel(),
                  static_cast<int>(ESP.getChipRevision()),
                  static_cast<unsigned long>(ESP.getCpuFreqMHz()),
                  static_cast<unsigned long>(ESP.getFlashChipSize() /
                                             (1024UL * 1024UL)),
                  static_cast<unsigned long>(ESP.getPsramSize()));

    // Load last-known quota from NVS so we have something to show even
    // before the first BLE write arrives.
    cc_hud::QuotaSnapshot loaded;
    if (cc_hud::persistenceLoad(loaded)) {
        Serial.printf("[NVS] load ok: 5h %u/%u  7d %u/%u  ts %llu\n",
                      loaded.used_5h, loaded.limit_5h,
                      loaded.used_7d, loaded.limit_7d,
                      static_cast<unsigned long long>(loaded.last_update_ms));
    } else {
        Serial.println("[NVS] cold start (no quota saved)");
    }
    // millis() resets to 0 on boot, but NVS holds a stale last_update_ms
    // from the previous run. Reset the time-relative fields so the idle
    // timer counts from THIS boot and the clock waits for a fresh BLE
    // calibration before claiming to know the time.
    loaded.last_update_ms  = 0;
    loaded.time_capture_ms = 0;
    cc_hud::g_quota = loaded;

    // Build BLE state in three steps so NimBLE's "all services must exist
    // before advertising starts" rule is honored:
    //   1. bleServerInit  — quota service + chars + advertising metadata
    //   2. otaServerInit  — OTA service + chars on the same server
    //   3. bleStartAdvertising — finally make us discoverable
    cc_hud::bleServerInit(cc_hud::onQuotaWrite,
                          cc_hud::onConnChange,
                          cc_hud::onIdleWrite,
                          cc_hud::onStateWrite,
                          cc_hud::onWifiWrite);
    cc_hud::otaServerInit(cc_hud::bleGetServer());
    cc_hud::bleStartAdvertising();

    Serial.println("[BOOT] setup done");
}
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

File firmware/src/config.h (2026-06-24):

// config.h
// Central definitions for cc_hud firmware: pin map, BLE UUIDs, colors, layout
// constants, NVS keys, thresholds and protocol-related sizes.
//
// Hardware: ESP32-S3-Nano (Arduino Nano ESP32 pinout) + ST7789 1.54" 240x240
// LCD on 4-wire SPI. Pins listed here mirror the wiring documented in the
// project root README and CLAUDE.md.

#pragma once

#include <Arduino.h>

namespace cc_hud {

// ---------------------------------------------------------------------------
// Hardware pin map (board pin -> ESP32 GPIO). Already configured for TFT_eSPI
// via build_flags in platformio.ini; the constants below are repeated for
// project-side use (e.g. backlight control or future expansion).
// ---------------------------------------------------------------------------
constexpr uint8_t kPinLcdMosi = 38;  // D11
constexpr uint8_t kPinLcdSclk = 48;  // D13
constexpr uint8_t kPinLcdCs   = 21;  // D10
constexpr uint8_t kPinLcdDc   = 10;  // D7
constexpr uint8_t kPinLcdRst  = 17;  // D8
constexpr uint8_t kPinLcdBl   = 18;  // D9

// ---------------------------------------------------------------------------
// WS2812B status LED ring (8 pixels), powered from the 3.7V lithium
// directly (before boost), DIN -> GPIO via 470Ω, with a 470µF cap across
// VCC/GND. Common-ground with the ESP32.
//
// kPinLedRing must be the *GPIO number*, not the silkscreen "Dx" label.
// On the genuine Arduino Nano ESP32 mapping, silk "D5" = GPIO8; on some
// cheap clones silk "D5" = GPIO5. If the ring doesn't light up after a
// fresh OTA, swap this between 5 and 8 to match your board.
// ---------------------------------------------------------------------------
constexpr uint8_t  kPinLedRing        = 5;   // silk "D2" on Arduino Nano ESP32 standard mapping

// ---------------------------------------------------------------------------
// Optional add-on hardware (firmware ships ready; safe when unwired).
//
// Battery voltage sense (GPIO1 = ADC1_CH0). Wire a 2:1 divider:
//   BAT+ ── 100kΩ ──┬── GPIO1
//                   └── 100kΩ ── GND
// So the ADC sees half the battery voltage (4.2V → 2.1V, within range).
// When the pin is left floating (not yet wired) the reading is implausible
// and the firmware treats it as "no battery sensor" — no false warnings.
//
// Push button (GPIO2 → button → GND). Uses the internal pull-up, so an
// unwired pin reads HIGH (released). Short press = manual page advance,
// long press = toggle manual dim.
// ---------------------------------------------------------------------------
constexpr uint8_t  kPinBatterySense   = 1;    // ADC1_CH0
constexpr uint8_t  kPinButton         = 2;
constexpr uint16_t kBatDividerRatioX10 = 20;  // 2.0× (×10 to stay integer)
constexpr uint16_t kBatFullMv         = 4200; // Li-ion 100%
constexpr uint16_t kBatEmptyMv        = 3000; // Li-ion 0%
constexpr uint16_t kBatLowMv          = 3450; // low-battery warning threshold
constexpr uint16_t kBatPlausibleMinMv = 2500; // below → assume no sensor wired
constexpr uint16_t kBatPlausibleMaxMv = 4500; // above → assume no sensor wired
constexpr uint32_t kButtonLongPressMs = 800;  // ≥ this = long press
constexpr uint32_t kButtonDebounceMs  = 30;
constexpr uint16_t kLedRingCount      = 24;   // WS2812B 24-position ring (per BOM)
// Brightness 0..255. 24 LEDs lit together (gauge / red full-ring) get glary
// fast, so keep this low. Day ~16, night dims to kLedRingBrightnessNight.
constexpr uint8_t  kLedRingBrightness      = 10;  // daytime
constexpr uint8_t  kLedRingBrightnessNight = 3;   // 23:00–07:00 auto-dim
constexpr uint32_t kLedChaseStepMs    = 90;   // 90ms × 24 ≈ 2.2s rotation (calm)
constexpr uint8_t  kLedCometLen       = 7;    // lit pixels in the comet tail (of 24)
constexpr uint32_t kLedBlinkHalfMs    = 500;  // 500ms on / 500ms off

// ---------------------------------------------------------------------------
// Firmware identity + NTP time. kFirmwareVersion is shown on the web
// dashboard for support. NTP auto-syncs the clock whenever WiFi is up, so
// the clock survives a power loss without a manual BLE re-calibration.
// kDefaultTzMin is the timezone used until a BLE idle-push provides one
// (480 = UTC+8, China). NVS-persisted tz overrides it.
// ---------------------------------------------------------------------------
constexpr const char* kFirmwareVersion = "2026.06.21";
constexpr int16_t     kDefaultTzMin    = 480;   // UTC+8
constexpr const char* kNtpServer1      = "ntp.aliyun.com";
constexpr const char* kNtpServer2      = "pool.ntp.org";
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

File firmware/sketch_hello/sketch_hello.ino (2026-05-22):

// cc_hud — ST7789 1.54" 240x240 hello-world (Arduino CLI sketch)
// Board: ESP32-S3R8 (8MB Flash + 8MB PSRAM), Arduino Nano ESP32 clone
// FQBN:  esp32:esp32:esp32s3:PartitionScheme=huge_app,CDCOnBoot=cdc
//
// Wiring (LCD silkscreen -> board pin -> ESP32-S3 GPIO):
//   GND -> GND
//   VCC -> 3V3
//   SCL -> D13  (GPIO48, SPI SCK)
//   SDA -> D11  (GPIO38, SPI MOSI)
//   RST -> D8   (GPIO17)
//   DC  -> D7   (GPIO10)
//   SC  -> D10  (GPIO21)  (CS)
//   BL  -> D9   (GPIO18)

#include <SPI.h>
#include <Adafruit_GFX.h>
#include <Adafruit_ST7789.h>

constexpr int8_t PIN_MOSI = 38;
constexpr int8_t PIN_SCK  = 48;
constexpr int8_t PIN_CS   = 21;
constexpr int8_t PIN_DC   = 10;
constexpr int8_t PIN_RST  = 17;
constexpr int8_t PIN_BL   = 18;

SPIClass spi(HSPI);
Adafruit_ST7789 tft(&spi, PIN_CS, PIN_DC, PIN_RST);

void setup() {
  Serial.begin(115200);
  delay(2500);
  Serial.println();
  Serial.println("[BOOT] cc_hud Adafruit_ST7789 hello-world");
  Serial.printf("[CHIP] %s rev %d, %lu MHz, flash %lu MB, psram %lu B\n",
                ESP.getChipModel(), (int)ESP.getChipRevision(),
                (unsigned long)ESP.getCpuFreqMHz(),
                (unsigned long)(ESP.getFlashChipSize() / (1024UL * 1024UL)),
                (unsigned long)ESP.getPsramSize());

  pinMode(PIN_BL, OUTPUT);
  digitalWrite(PIN_BL, HIGH);
  Serial.println("[BL] HIGH (panel should be lit even before SPI)");

  Serial.printf("[SPI] begin SCK=%d MOSI=%d CS=%d (no MISO)\n",
                PIN_SCK, PIN_MOSI, PIN_CS);
  spi.begin(PIN_SCK, -1, PIN_MOSI, PIN_CS);
  Serial.println("[SPI] begin done");

  Serial.println("[TFT] init(240,240,SPI_MODE0)...");
  tft.init(240, 240, SPI_MODE0);
  Serial.println("[TFT] init done");

  tft.setSPISpeed(10 * 1000 * 1000);  // 10 MHz conservative
  tft.setRotation(0);

  Serial.println("[TFT] fill RED");
  tft.fillScreen(ST77XX_RED);
  delay(600);
  Serial.println("[TFT] fill GREEN");
  tft.fillScreen(ST77XX_GREEN);
  delay(600);
  Serial.println("[TFT] fill BLUE");
  tft.fillScreen(ST77XX_BLUE);
  delay(600);

  Serial.println("[TFT] BLACK + 'HELLO'");
  tft.fillScreen(ST77XX_BLACK);
  tft.setTextColor(ST77XX_WHITE);
  tft.setTextSize(4);
  tft.setCursor(20, 90);
  tft.print("HELLO");

  Serial.println("[DONE] -> loop()");
}

void loop() {
  static uint32_t last = 0;
  if (millis() - last >= 1000) {
    last = millis();
    Serial.printf("[tick] %u s, heap=%lu\n",
                  (unsigned)(millis() / 1000),
                  (unsigned long)ESP.getFreeHeap());
  }
}

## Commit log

2026-05-22 hardware: verified ST7789 SPI wiring via Adafruit hello-world sketch
    - sketch_hello/sketch_hello.ino: minimal Arduino sketch, cycles
    RED/GREEN/BLUE then draws 'HELLO' (proven to light up the panel)
    - Switched from TFT_eSPI to Adafruit_ST7789 — TFT_eSPI was crashing
    in tft.init() on this ESP32-S3R8 clone
    - Switched board target from arduino_nano_esp32 to esp32-s3-devkitc-1
    to avoid ARDUINO_USB_DFU_ON_BOOT clashing with the USB JTAG/Serial unit
    - PSRAM left disabled for the hello-world; can be re-enabled with
    board_build.arduino.memory_type = qio_opi when needed
    - Flash via Arduino CLI FQBN
    esp32:esp32:esp32s3:PartitionScheme=huge_app,CDCOnBoot=cdc
    Recovery trick when the user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
    [main.cpp, sketch_hello.ino]
2026-05-22 feat: full v1 implementation — BLE + Adafruit_ST7789 end-to-end working
    Firmware (firmware/src/):
    - display.cpp rewritten with Adafruit_GFX + Adafruit_ST7789 (replaces
    TFT_eSPI which crashed in init() on this ESP32-S3R8 clone).
    Same layout: header + 5H/7D rows with big percentage + colored
    progress bar + 'used/limit' + footer freshness, partial redraw via
    LastDrawnState diff.
    - main.cpp: full state machine — load NVS → init display → init NimBLE
    → loop drains redraw / connection events, footer ticks every 5s.
    - ble_server.cpp + persistence.cpp restored (renamed from .disabled).
    - config.h, *.h unchanged.
    Build:
    - platformio.ini: board=esp32-s3-devkitc-1, NimBLE-Arduino a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
    [display.cpp, main.cpp]
2026-05-22 feat: v3 protocol — title, reset countdown, subscription/api modes
    Protocol v3 (msg_type=0x03, 27+title_len bytes, variable):
    u8 msg_type=0x03
    u8 mode (0=sub, 1=api)
    u16x4 5h/7d used+limit (sub mode)
    u32x2 5h/7d reset_in_seconds (sub mode, decrements live on device)
    u32x2 cost_micro_usd, duration_s (api mode)
    u8 title_len + title_len ASCII bytes (e.g. 'Plan Max (20x)')
    v1 (0x01, 9B) and v2 (0x02, 17B) still accepted for back-compat.
    Firmware:
    - config.h: new constants for v3, mode flags, title max len, new NVS keys.
    - persistence.{h,cpp}: QuotaSnapshot grows mode/title/reset_in_s/cost/duration;
    NVS save/load extended.
    - ble_server.cpp: payload router dispatches v1/v2/v3 by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
    [ble_server.cpp, config.h, display.cpp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]
2026-05-22 feat: BLE OTA + 95% threshold alert + on-device OTA progress UI
    Three loosely coupled features, but they ship together because OTA forces
    a partition-table change that wipes NVS once, so we want all of v3.1
    landed in the same flash.
    --- Partition table ---
    - Added firmware/partitions_ota_8mb.csv: dual-app OTA layout for 8 MB flash
    (each app slot 3 MB, ~1.9 MB spiffs, 64 KB coredump).
    - platformio.ini switched from huge_app.csv to the new CSV;
    board_upload.maximum_size is now 0x300000 (one slot).
    - .gitignore exempts partitions_ota_8mb.csv from the project-wide *.csv
    ignore (it's firmware source-of-truth).
    --- Threshold alert (5H/7D ≥ 95% one-shot red flash) ---
    - config.h: kAlertTh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
    [partitions_ota_8mb.csv]
2026-05-22 hardware: 3D-printed enclosure (case + back cover) + comprehensive README
    Enclosure (parametric build123d sources, Bambu-ready 3MF, CAD-portable STEP):
    - cc_hud_case.py / .3mf / .step — main shell 38×50×30 mm, front panel with
    32.7×35.3 screen window, top USB-C cut-out, 4 corner hooks for the screen
    PCB, 4 standoffs for the ESP32 board, 4 bottom feet, open back
    - cc_hud_back_cover.py / .3mf / .step — drop-in lip-joint cover 38×50×5 mm,
    2 fingernail-pry notches in the bottom edge
    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
    [cc_hud_back_cover.3mf, cc_hud_back_cover.step, cc_hud_case.3mf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]
2026-05-22 docs: add UI photos (running HUD + OTA progress)
    - images/screen.jpg: live HUD on the device showing plan title +
    5H/7D usage bars with reset countdown
    - images/screen-ota.jpg: full-screen OTA progress overlay while a new
    firmware is streaming in over BLE
    - README: render both photos side-by-side at the top, drop the
    assembled-photo placeholder section (we already document the
    layout in the assembly step list)
    - Remove images/README.md (folder no longer needs its own README)
2026-05-22 hardware: enclosure v2 — fits real screen module + battery + power chain
    Re-measured the parts and grew the case to actually fit everything:
    Screen module:
    - Active area: 32.7 × 35.3 → 35 × 33 (rotated)
    - Module PCB: 33 × 44 → 44 × 34
    - Combined thickness: 1.6 + 2 (header) → 4.2 mm (active + PCB combined;
    this module has no separate back-side header pins)
    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
    [cc_hud_back_cover.3mf, cc_hud_back_cover.step, cc_hud_case.3mf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]
2026-05-22 hardware: enclosure v2 portrait — keep tall screen orientation
    Previous v2 commit had the screen laid out landscape by accident. The
    real screen module is portrait: long edge along Y, short edge along X.
    Re-laid the case out to match.
    Dimensions:
    - Screen active : 33 × 35 (was wrongly 35 × 33)
    - Screen PCB : 34 × 44 (was wrongly 44 × 34)
    - Outer case : 40 × 58 × 55 (was 48 × 56 × 55)
    - X (40) snug around the 35 mm battery + 4 mm walls
    - Y (58) tall enough for the 52 mm battery + 1 mm clearance per side
    - Z (55) unchanged
    - Screen-PCB retention: back to 4 corner L-bracket hooks (4 × 8 × 2)
    flush with the inner X and Y walls — the PCB has clearance on both
    axes n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
    [cc_hud_back_cover.3mf, cc_hud_back_cover.step, cc_hud_case.3mf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]
2026-05-22 hardware: drop the 4 corner hooks + shorten standoffs
    Per user feedback the corner L-bracket hooks were unnecessary and the
    standoffs felt too tall.
    Changes:
    - Removed the 4 corner L-bracket hooks behind the screen PCB. The PCB
    is now simply sandwiched between the front panel and the front face
    of the ESP32 board. A dab of foam / hot glue in each corner is the
    suggested capture if you want it positively locked.
    - Tightened WIRE_GAP from 3.0 mm → 1.4 mm. Physical standoff height
    therefore drops from 7.2 mm → 5.6 mm (SCREEN_TOTAL_T 4.2 + WIRE_GAP
    1.4). The standoff cannot go below 4.2 mm physical because the
    screen module itself is 4.2 mm thick — see the comment in the .py.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
    [cc_hud_case.3mf, cc_hud_case.step]
2026-05-22 hardware: standoffs literally 1.4 mm tall — screen glass embeds in panel
    User wants the four cylindrical standoffs to be physically 1.4 mm. To
    make that geometrically possible without the ESP32 board crashing into
    the screen PCB, the front panel was bumped from 2.0 to 2.7 mm so the
    screen active glass (2.7 mm thick) sits *inside* the panel cut-out:
    the glass occupies Z=0..2.7 (within the front-panel thickness), the
    screen PCB occupies Z=2.7..4.2 right behind the panel, and the 1.4-mm
    standoffs occupy Z=2.7..4.1, lifting the ESP32 board to Z=4.1..5.7.
    A 0.1 mm nominal interference between the PCB back face (4.2 mm) and
    the ESP32 board front face (4.1 mm) is left as print-tolerance slack.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
    [cc_hud_case.3mf, cc_hud_case.step]
2026-05-22 hardware: rotate ESP32 board sideways so USB-C exits the side wall
    USB-C connector is physically soldered to one short edge of the ESP32
    board, so to put the charge port on the side of the case the entire
    board has to lie sideways inside the enclosure. The case grew on the
    X axis to accept the now-horizontal board (45 mm long edge along X).
    - ESP_PCB_W / ESP_PCB_H swapped (32 × 45 → 45 × 32)
    - CASE_W 40 → 51 (INNER_W 36 → 47, accepts the 45 mm board edge with
    1 mm clearance per side)
    - USB-C cut-out moved from the +Y top wall to the +X side wall
    (right-hand side when the screen faces the user)
    - STANDOFF_INSET flipped back to +0.5 (positive). With the board on
    its sid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
    [cc_hud_back_cover.3mf, cc_hud_back_cover.step, cc_hud_case.3mf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]
2026-05-22 hardware: drop standoffs + add header-pin relief pocket; USB-C exits back cover
    Two-part change per user feedback:
    1. The four cylindrical standoffs were removed entirely. They were
    redundant — the screen PCB and the ESP32 board can be held in
    place with a 5x5 mm dab of double-sided foam tape or hot glue
    at each corner. Geometry is much cleaner now (~64 vertices vs
    ~1k before).
    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
    [cc_hud_back_cover.3mf, cc_hud_back_cover.step, cc_hud_case.3mf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]
2026-05-22 hardware: case depth 55 → 45 mm
    Drop CASE_D from 55 to 45 mm. The previous 55 mm depth left ~38 mm of
    free Z behind the ESP32 board, which is more than the LiPo (~5 mm) +
    TP4056 (~4 mm) + MT3608 (~4 mm) + slide switch (~4 mm) + cabling
    actually need. 45 mm still leaves ~27 mm of free Z back there — plenty
    for the power stack — and shaves ~10 mm off print height + cuts the
    finished depth proportionally.
    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
    [cc_hud_case.3mf, cc_hud_case.step]
2026-05-23 hardware: TP4056 pocket in back cover + USB-C exits case top wall
    The TP4056 charging module is now mechanically secured by the back
    cover instead of floating loose inside the cavity:
    • Back cover gets a 25.5 × 18.5 × 3.5 mm pocket carved from the
    lip-top inward. The pocket positions the TP4056 board so its
    USB-C edge lines up with the cover lip's top Y edge (+Y).
    • The case top wall (+Y) gets a 9.8 × 4.3 mm USB-C cut-out at
    case_z = 42.25, derived from the TP4056 placement geometry.
    When assembled, the TP4056's USB-C connector pokes straight out the
    top of the case — the user plugs a charging cable into the top and
    the lead runs directly into the module.
    The prev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
    [cc_hud_back_cover.3mf, cc_hud_back_cover.step, cc_hud_case.3mf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]
2026-05-23 hardware: TP4056 vertical orientation, snap-fit hooks, deeper pin relief slot
    Three small refinements per user feedback:
    1. TP4056 module is now mounted VERTICALLY: long edge (25 mm) along
    Y, short edge (18 mm) along X. Swaps TP4056_W/H values; pocket
    becomes 18.5 × 25.5 × 3.5 mm. USB-C is still on the board's +Y
    short edge so it stays aligned to the case top-wall cutout.
    2. Added two retention hooks at the +X / -X edges of the TP4056
    pocket. Each hook is HOOK_OVERHANG=0.5 mm of overhang catching
    the board top, HOOK_X_THICK=1.5 mm of anchor in the lip, total
    2 mm thick. Hook height covers the full distance from the board
    top face (cover_z=3) to the l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
    [cc_hud_back_cover.3mf, cc_hud_back_cover.step, cc_hud_case.3mf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]
2026-05-23 hardware: TP4056 pocket Y +2.2mm; 4 retention hooks (2 pairs)
    Two adjustments per dry-fit feedback:
    - TP4056_H bumped 25.0 → 27.2 (real-world board is 2.2 mm longer
    than the typical spec). Pocket grows to 18.5 × 27.7 × 3.5 mm.
    TP4056_Y_CENTER recomputes to 13.2.
    - Retention hooks doubled from 2 to 4 (one pair at +Y end of board,
    one pair at -Y end). The new HOOK_Y_INSET=3 mm parameter places
    each hook 3 mm in from its corresponding board Y edge.
    Hook hold geometry unchanged: 0.5 mm X overhang, 1.5 mm X anchor
    in the lip, 4 mm Y length, 2 mm Z height — board snaps in and is
    held flat at four points.
    [cc_hud_back_cover.3mf, cc_hud_back_cover.step]
2026-05-23 feat: idle clock screen with v4 BLE time push + force-idle command
    When the device sees no v1/v2/v3 quota write for 30 minutes (or on
    demand via msg_type 0x05) it swaps the HUD for a centred clock + date
    + user-supplied status string. The clock is calibrated from the host
    via BLE (no NTP / WiFi); millis() keeps it ticking between calibration
    pushes.
    Protocol additions:
    - v4 (msg_type 0x04): 8 + status_len bytes
    u8 msg_type = 0x04
    u32 unix_ts (LE) -- host UTC seconds
    i16 utc_offset_min (LE)
    u8 status_len
    .. status_len ASCII bytes
    - Force-idle command (msg_type 0x05, 2 bytes): 0x05 + 0x01 enters
    forced idle, 0x05 + 0x00 releases it (useful for previewing the
    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
    [ble_server.cpp, config.h, display.cpp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]
2026-05-23 feat: walking cat sprite + automatic weather fetch on idle screen
    Idle screen gets a hand-drawn pixel cat that walks across the top:
    - 26-px head with yellow body, red inner ears, white sparkle in the
    eyes, pink nose, small smile, and grey whiskers — all drawn from
    GFX primitives (no bitmap data, no flash cost beyond the calls).
    - Walk: triangle-wave X between 28..212 over 18 seconds, so the cat
    paces back and forth above the clock.
    - Bob: 2 px vertical step every 500 ms, suggesting actual walking.
    - Blink: eyes close for 200 ms every 4 s.
    - Repaint guard: skips frame if cx hasn't moved >=3 px (keeps the
    redraw cadence below the visible-flicker threshold). Erases the
    previous bbo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
    [display.cpp, main.cpp]
2026-05-24 feat: brand logo + animated thinking GIF + mood pet + BLE 2M PHY
    Visual upgrades to the HUD and idle screens:
    HUD footer (left → right):
    - updated Xm ago (existing)
    - 40x40 brand badge (Naiopsis / mirrorin.ai)
    - 40x40 thinking GIF — 8-frame animated splatter star in Claude
    orange, drawn from a const uint16_t RGB565 array embedded in flash
    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
2026-05-27 feat: live Claude Code state mirroring via hooks (msg_type 0x07)
    The footer right-side 40x40 slot now reflects what Claude Code is
    doing right now, driven by hook callbacks on the host:
    UserPromptSubmit → cchud-hook.sh thinking → splatter GIF
    PreToolUse → cchud-hook.sh tool → tool icon
    PostToolUse → cchud-hook.sh thinking → splatter GIF
    Stop → cchud-hook.sh idle → blank
    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
2026-05-27 ui: idle state shows three dim dots instead of a static splatter
    Empty footer slot was too cold ("Claude vanished"); the first try at
    a dim static Claude splatter looked like a sea-urchin / pen nib at
    low intensity. Swap to three small dim-orange dots in a row — reads
    as "ready, resting", like chat typing-dots frozen in place.
    The thinking GIF still fires when Claude is actively working, so the
    state transitions are obvious:
    work → bright animated splatter
    tool → tool icon
    waiting → pulsing dot
    idle (Stop) → three small dots, no animation
    [display.cpp]
2026-05-27 fix(hook): single-flight lock prevents BLE adapter race
    Symptom: footer slot got stuck on whichever state happened to win the
    BLE write race — often "waiting" — and every subsequent push failed
    with "Device with address ... was not found". macOS CoreBluetooth
    only allows one peripheral connection at a time, but Claude Code
    hooks fire dozens per second and each was spawning its own
    fire-and-forget BLE pusher, all trying to connect simultaneously.
    Fix:
    - mkdir-based POSIX mutex /tmp/cchud-push.lock around the push.
    Concurrent hooks either acquire the lock and push, or skip
    instantly. Dedup makes skipping safe — the next state transition
    reads the latest cached key and pushes that.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
2026-06-11 spike: LVGL 9 running on ST7789 via Adafruit flush path
    Phase-1 validation before committing to a full UI migration. Verified
    on hardware:
    - LVGL 9.2 + two 40-row partial SRAM buffers (no PSRAM dependency —
    the OPI PSRAM boot-loop issue on this board doesn't block LVGL).
    - flush_cb → Adafruit drawRGBBitmap. No RGB565 byte swap needed:
    native uint16_t out of LVGL's sw renderer matches what drawRGBBitmap
    expects on this panel.
    - Animated bar + spinner render smoothly at LV_DEF_REFR_PERIOD=16.
    - BLE + OTA stack untouched and confirmed alive on the spike build,
    so wireless iteration continues to work.
    Build cost: flash 676 KB → 877 KB (27.9% of slot), RAM 42 KB → 130 KB
    (39.8%,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
    [display.cpp, main.cpp]
2026-06-11 feat: migrate HUD + idle screens to LVGL 9
    Replaces ~1100 lines of hand-drawn Adafruit_GFX rendering (manual
    diff caches, coordinate math, partial-redraw bookkeeping) with LVGL
    widgets. The OTA progress screen intentionally stays on the legacy
    direct-draw path — LVGL stops ticking while OTA owns the panel and
    the device reboots after, so migrating it buys nothing.
    Architecture
    - main.cpp remains the single data owner. Once per loop it drains
    shared state under the portMUX lock, derives idle/mood/app-state
    with the exact same rules as the legacy path, and hands one
    LvglUiModel to lvglUiApply(). All widget updates diff against
    cached values, so a no-change tick costs a few strcmps.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
    [main.cpp]
2026-06-11 ui: larger HUD typography (title 20pt, row labels + countdowns 18pt)
    The plan title and the used/limit + reset-countdown sublabels were
    the hardest things to read at arm's length. Bump title Montserrat
    14 → 20 (clipped at 196 px so long plan names can't reach the BLE
    dot) and row labels + sublabels 14 → 18, then re-flow the vertical
    layout so nothing collides:
    title 4..30 · 5H block 36..110 · 7D block 116..190
    logo/state slot 192..232 · footer 214..230 (font 14, unchanged)
    Adds Montserrat 18 + 20 to lv_conf.h (~35 KB flash; now at ~34%).
2026-06-11 feat: Chinese weather on the idle screen (CJK font + WWO code map)
    Firmware
    - font_cn_20.c: 20 px / 4 bpp LVGL font generated from Arial Unicode
    with lv_font_conv. Glyph set = full ASCII + ° · ℃ ℉ + 136 CJK chars
    covering every WWO weather phrase plus major Chinese city names
    (~70 KB flash). The idle status label switches to this font; all
    other labels stay on Montserrat.
    - -DLV_LVGL_H_INCLUDE_SIMPLE so the generated font resolves "lvgl.h".
    Host
    - wttr.in's own zh translation is broken (lang_zh returns English),
    so push_idle.py now fetches format=j1 JSON and maps the numeric WWO
    weatherCode to Chinese locally (48-entry table, phrased strictly
    within the firmware glyph se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
2026-06-21 feat: WiFi OTA + 网页面板 + 多 AI 工具(Codex) + 24 灯环状态灯 + 制作指南
    固件:
    - WS2812B 24 灯环状态灯:额度表/工作彗星/等权限红闪/Codex 完成绿脉冲
    - WiFi OTA + cc-hud.local 网页面板(亮度滑块/翻页/调暗/版本健康)
    - 4 屏轮播(额度/统计/工具/时钟)+ 燃烧率耗尽预测 + 夜间/空闲自动调暗
    - NTP 自动校时(断电免手动校准)、电池电量监测 + 实体按钮(可选)
    - 修复 USB-CDC-on-boot 导致的插电脑黑屏(displayInit 前移)
    host:
    - push_wifi/state/quota/idle 加 BLE 重试;Notification 智能过滤(只权限请求才红)
    - Codex 支持:notify 适配器 + 链式调度器(保留 computer-use),答完触发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
    [battery.cpp, ble_server.cpp, config.h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]
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2026-06-21 docs+fix: TP4056 CC电阻避坑写入指南 + 修复 idle 下手动调暗失效
    - 指南: BOM 备注/充电方法/排障表 增加「TP4056 缺 CC 电阻 → C-to-C 不充,
    改用 USB-A→C 线或换带 CC 电阻版」;淘宝搜索要点
    - 固件: 手动调暗(长按/网页)改为覆盖式,赢过自动 night/idle 调暗,
    AI 活动后自动恢复 —— 修复 idle 自动调暗压住手动切换的 bug
    [main.cpp]
2026-06-23 feat: CC-HUD 状态/额度推送接入 Claude 与 Codex
    - 新增 cchud-statusline.sh:包装 ccstatusline,后台向 HUD 推送,不阻塞状态栏渲染
    - 新增 cchud-quota-push.sh:从 statusline JSON 读官方 rate_limits 百分比(5h/7d)
    与会话开销,跨会话取最大值合并(按 resets_at 区分窗口、窗口重置归零),
    交 cchud-update.sh 限频推送;额度口径与 Claude 官方 Usage 面板一致
    - cchud-hook.sh:状态推送改为短暂自旋等 BLE 锁,避免与额度推送争锁导致状态灯滞后
    - cchud-codex-dispatch.sh:修正 computer-use notify 的 ORIG 路径为本机
    - 各脚本默认 CCHUD_ADDR 更新为本机设备 UUID
    影响范围:仅 host 端推送脚本,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
2026-06-23 fix: CC-HUD 固件启动速度、开机闪屏与工作态调暗
    - main.cpp:启动时 delay(2500) 改为「检测到 USB 主机才等、连上即跳出,
    无主机 600ms 封顶」,电池/充电头供电下启动近乎瞬时
    - main.cpp:手动调暗(长按/网页)改为仅在「空闲→活动」跳变沿清除覆盖,
    修复工作态下长按无法调暗(原逻辑每个循环都把覆盖重置回自动)
    - display.cpp:背光点亮移到 fillScreen 清屏之后,消除开机时背光照出
    面板残留导致的全屏闪烁
    - lvgl_ui.cpp:LVGL 默认屏强制黑底,避免默认浅色主题在首帧/切屏露出白底
    影响范围:仅显示/启动/交互,BLE 协议不变。
    自测:WiFi OTA 刷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
    [display.cpp, main.cpp]
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2026-06-23 fix: 修复 CC-HUD 因 quota 推送被持续误判为 thinking
    app-state(idle/thinking/tool)本应只由显式状态推送(msg_type 0x07)驱动,
    但 onQuotaWrite 每次都会续上一个 90s 的「thinking 星标」窗口(本是给只推
    quota、不推状态的老 host 兜底用)。statusline 接入后每 ~30s 推一次 quota,
    该窗口被不断续命,导致开机后(app_state 仍为 Unset 时)设备一直显示 thinking,
    直到某个 session 推出真实状态才停下。
    去掉 onQuotaWrite 里对 g_thinking_until_ms 的刷新:状态完全由 0x07 决定,
    未收到状态前显示 idle。
    自测:WiFi OTA 刷入真机,开机保持 idle,仅 session 真实思考/调工具时 thinking。
    回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
    [main.cpp]
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2026-06-24 docs: 修正第 1 层计划 statusLine 数据流(保留渲染 + payload 契约一致)
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2026-06-24 feat: 新增 QuotaTracker 额度分窗合并与限频
    实现纯逻辑模块 QuotaTracker:
    - merge(): 按 resets_at 分窗处理额度,新窗口直接替换,同窗口取最大值
    - should_push() / mark_pushed(): 30s 限频实现,复刻原 bash 脚本行为
    已通过 3 个 TDD 测试覆盖所有逻辑分支。
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2026-06-24 fix: SocketServer 关闭连接后 await wait_closed 释放 transport
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2026-06-24 fix: cchud-emit nc 失败时回退到 venv Python 投递,避免事件静默丢失
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2026-06-24 fix: native test 改用 test_build_src 编译 src,移除失效的 symlink
    git core.symlinks=false 环境下,test/test_v7_tlv/v7_tlv.cpp 的 symlink 会
    退化成内容为路径字符串的文本文件,导致 pio test 把它当 C++ 源码编译报错。
    改用 PlatformIO 原生的 test_build_src=true + build_src_filter,仅编译
    src/v7_tlv.cpp,跨平台可靠。
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2026-06-24 fix(daemon): v7 ctx_pct 加 clamp(0-100)与 v6 对齐
    encode_quota_v6 中 ctx_pct 已有 max(0,min(100,...)) clamp,
    v7 分支 tlv_u8(TAG_CONTEXT_USED_PCT,...) 缺失同等 clamp。
    对齐:仅对 ctx_pct 处理,其余百分比字段与 v6 保持一致(无 clamp)。
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2026-06-24 fix: Codex request_user_input 工具映射为 waiting(实测修正)
    真机日志证明 Codex(CLI/App)通过名为 request_user_input 的工具调用向用户
    提问(走 PreToolUse),而非 PermissionRequest。原 adapter 误把它当普通工具
    显示为 tool 态(彗星)。改为命中 _WAIT_TOOLS 时映射 waiting,设备正确进入
    等待态(红环)。新增回归测试。
2026-06-24 feat: 第 3 层 host 侧 - intervention_kind 贯穿 + v7 状态帧
    - CcHudEvent 加 intervention_kind(approval/question/error);SessionStore、
    Aggregator 贯穿该字段。
    - adapter 填介入类型:Codex request_user_input / Claude AskUserQuestion →
    waiting+question;权限请求 → waiting+approval。
    - codec.encode_v7_state:状态帧 v7 化(AGG_STATE + 会话计数 + 工具名 +
    INTERVENTION_KIND/TOOL),取代旧 0x07(解决 I1 遗留);daemon use_v7 时改用。
    - 新增 v7 介入域 tag(0x40-0x45)。测试 42 passed。
2026-06-24 feat: 第 3 层固件 - v7 解析介入类型 + waiting 显示在等什么
    v7_tlv 解析 INTERVENTION_KIND(0x40);StateWriteHandler 贯穿 kind;
    main 存 g_app_intervention 入 snapshot;TOOL 页 waiting 文本按介入类型
    细化:approve?/answer?/error!(取代泛泛 needs you)。native 5 passed。
    [ble_server.cpp, main.cpp]
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2026-06-24 fix: daemon 接管时间推送 + Codex bypass 模式不误亮红灯
    时间:第 1 层 daemon 重构遗漏了时间推送(旧 push_idle.py 职责),设备
    无网无 NTP 导致时钟错误。daemon 现启动即推、每 30 分钟推一次 v4 时间帧
    (encode_time_v4,固件现成解析,无需 OTA)。
    红灯:Codex 在"替我审批"(bypassPermissions)模式下仍发 PermissionRequest
    hook,旧 adapter 误判为等待批准亮红灯。现检测 permission_mode,bypass 时
    视为 thinking 不亮红灯。测试 45 passed。
2026-06-24 fix: daemon 接管天气推送 + v4 status 改 UTF-8
    时间修复用 v4 帧时漏了 status=天气字段,推空 status 清掉了空闲页天气。
    daemon 现复用 push_idle.fetch_weather(wttr.in,走线程不阻塞),时间+天气
    一起推;encode_time_v4 改 UTF-8 安全截断支持中文天气。城市可用
    CCHUD_WEATHER_CITY 配置,默认北京。
2026-06-25 fix: daemon 周期重聚合自愈,会话静默结束后设备回 idle
    纯事件驱动的缺陷:会话异常结束(关窗口/崩溃/断网,无 Stop)时 daemon
    不会主动重推 idle,设备卡在最后的 thinking/tool 态。新增 _tick_loop
    每 10 秒重聚合一次(启动即先推一次),TTL 过期会话被清后自动推 idle。
    抽出 _emit_state 供事件与 tick 共用。新增自愈测试,共 46 passed。
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2026-06-30 docs+fix: daemon 接入文档对齐实况 + Codex hooks 修正 + 防闪烁/npx
    - README/DAEMON.md: 改为 cchud_daemon.cli install 一键配置 Claude/Codex
    - 固化踩坑: Python>=3.10(3.9 asyncio loop bug)、macOS 蓝牙 TCC 别用 launchd、Codex 勿写 hooks=true(自动加载 hooks.json + 重启 Trust)、旧 cchud-hook.sh 需手动清
    - cli.py: install codex 提示改为 Trust hooks(原 hooks=true 提示会坑人)
    - cchud-hook.sh: busy 推送限频防多会话闪烁(CCHUD_STATE_MIN_GAP)
    - cchud-statusline.sh: bunx -> npx(本机无 bun)
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2026-10-23 feat: migrate desktop HUD to Codex
    替换图标、中文界面与配色，移除 5H 额度显示和告警，保留旧协议、配网、按钮及升级能力。
    新增多会话工作页，展示项目、模型、思考强度、上下文、工具阶段、计划步骤和耗时；按问题 ID 跟踪待回答状态，修复自动审批红灯误报和并行工具状态覆盖。
    验证：主机 88 项测试、native 12 项测试与 ESP32-S3 构建通过。上一版工作页已完成真机回读；本轮 codex.4 正在 BLE 升级，验收结果另行记录。可通过保留的旧协议和本机固件备份回滚。
2026-10-23 docs: record Codex HUD device verification
    记录 codex.4 OTA、版本回读和真实待回答状态验收，修正 README 对仓库可见性的错误描述；回答后的清除仍待真实用户回复验证。
2026-10-23 fix: clear stale question reminders after plain replies
    新轮次收到普通用户消息时撤下旧轮次的待回答提醒，保留同轮追问、环境更新和结构化部分回答对应的未处理问题。
    验证：90 项主机测试通过；后台服务已更新，主机和设备均回读 pending_questions=0。
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2026-10-26 feat: improve Codex HUD workflow and attention cards
    使用 Codex 项目名称和侧边栏会话名称，合并模型指标并优化两行标题。新增公开进展、分类待处理卡和近期结果回看；去掉总览，短按直接浏览详情与结果，保留自动停留和手动保持。
    区分待回答、人工审批和错误提示，调整工作、等待及完成灯效。扩展卡片分片与只读回读，保留旧协议兼容。降低 BLE 接收回调栈占用并增加任务栈余量，修复真机写入断连。
    验证：106 项主机测试、19 项固件测试和 ESP32-S3 构建通过；codex.10 已完成 BLE OTA、分类诊断及真实会话回读。保留本机旧固件备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
